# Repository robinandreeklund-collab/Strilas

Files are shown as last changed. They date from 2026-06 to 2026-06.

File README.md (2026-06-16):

# STRILAS

**Ballistic Laser Tactical-Engagement Simulator** — an open, DIY force-on-force training/gaming system. Players carry replica weapons that fire **coded infrared light** (not projectiles). Hits are registered by body/helmet detectors, ballistics and time-of-flight are simulated centrally, and every shot, movement, reload and hit is logged for live tracking and after-action review.

Think MILES / laser-tag, but with simulated ballistics, physical recoil feedback, NFC-based ammunition logistics, and an open telemetry stack you own.

> 📖 **Komplett systemguide (master-referens):** [`STRILAS-SYSTEM-GUIDE.md`](STRILAS-SYSTEM-GUIDE.md)
> — allt på ett ställe: arkitektur, ballistik/räckvidd, precision, hitbox, algoritm, optik, RTK-position,
> haptik, korten, batteritid, eye-safety, tillverkning, verifiering och repo-karta.
> Tillverkningsberedskap: [`vapen-stack/nextpcb/FORSTA-BATCH.md`](vapen-stack/nextpcb/FORSTA-BATCH.md).

---

## ⚠️ Safety first — read this before building anything

STRILAS is a **simulation and immersion** system. It does **not** fire projectiles and provides **no** uplift toward any real weapon. It does, however, contain three genuine hazards that you are responsible for handling correctly:

1. **Eye safety (IR laser).** The engagement emitter uses near-IR (~905 nm) which is **invisible**. Keep the optical output within **Class 1 (eye-safe)** limits and enforce the current limit **in hardware**, not just firmware. The risk is highest near the muzzle where players point at each other. If you are not confident you can keep it Class 1, use a diverged IR-LED emitter instead of a collimated laser diode.
2. **LiPo charging.** The base dock charges many lithium packs at once. This is the single largest fire risk in the project — larger than the laser. Use per-cell balancing, a real BMS, thermal monitoring, and a fire-safe charging area.
3. **High-current contacts.** The recoil rail carries ~20 A peaks through the magazine interface. Use contacts rated **> 25 A** and only ever make/break them **cold** (rail disabled during insert/extract — see the make-ready state machine).

**Replica / airsoft chassis:** STRILAS is typically built onto an airsoft replica body. Airsoft replicas are age- and region-restricted; check and follow your local laws for ownership, transport (e.g. muzzle covers / cases), and where you may use them. Treat and store the device responsibly and never carry it in public in a way that could be mistaken for a real firearm.

**Play safety:** eye protection (rated goggles) for all participants, defined play boundaries, and a clear "weapons safe" procedure.

---

## What it does

- **Coded IR engagement** — every shot transmits a packet (shooter ID, weapon profile, ammo/damage code). Detectors on harness + 360° helmet register hits and hit zones.
- **Simulated ballistics** — per-weapon/ammo profiles define muzzle velocity, drag model, drop and time-of-flight. Because the laser arrives instantly, the **server** adjudicates whether the simulated round would land, using both players' positions, the weapon's attitude and the computed flight time.
- **Physical recoil** — an electronic reciprocating-mass unit gives a real kick, scaled per weapon profile. The IMU senses the muzzle climb it causes and feeds it into the **next** shot's trajectory (the recoil-to-aim loop), so uncontrolled bursts walk off target.
- **NFC ammunition logistics** — each magazine carries a passive NFC tag (ID, capacity, rounds remaining). Inserting a mag sets the ammo counter; running dry blocks fire; reloading rewrites the tag to full at base.
- **Make-ready drill** — the recoil power rail (sourced from a battery inside the magazine) is enabled only after racking a charging handle, mirroring "chamber a round," and disabled before the magazine is released. This also guarantees the high-current contacts are always made/broken cold.
- **Live positioning & telemetry** — UWB (+ GNSS outdoors) gives sub-30 cm position; body/weapon IMUs give pose. Everything is timestamped to a shared clock.
- **After-action review** — weapon-cam video synced with the full event timeline, plus a live dashboard and map.

---

## How it works (engagement model)

```
trigger ──► IR emitter sends coded pulse ──► target detector registers strike
   │                                                  │
   └─► recoil unit fires (PWM scaled)                 │
   └─► IMU captures barrel attitude                   ▼
                                       SERVER adjudicates:
                                       shooter pos + target pos (UWB/GNSS)
                                       + barrel attitude (IMU)
                                       + simulated time-of-flight & drop
                                       ──► hit / miss / hit-zone outcome
```

The key design choice is **central, positional adjudication**: rather than computing the result on each weapon, the server knows where both parties are and how they are moving, and resolves the engagement with the simulated projectile's flight time. This is fairer for moving targets and is the basis for the analytics layer.

---

## Project map (design → validated → runnable)

This repo has grown from the spec above into a **physically-validated design with a runnable
reference implementation**. Where to look:

| Area | What | Where |
|---|---|---|
| **Analysis & BOM** | README review + state-of-the-art level-3 BOM + chosen dev boards | [`docs/hardware-analysis.md`](docs/hardware-analysis.md) |
| **Architecture** | geometric ballistic adjudication + fused pose stack (incl. precision ≠ beam width) | [`docs/level3-ballistic-architecture.md`](docs/level3-ballistic-architecture.md) |
| **System flow** | how it all connects (component map, shot sequence, pose layers) | [`docs/system-flowchart.md`](docs/system-flowchart.md) |
| **v1 build** | exact shopping list for a precise 100–150 m shooting test | [`docs/mvp-shooting-test-bom.md`](docs/mvp-shooting-test-bom.md) |
| **Weapon PCB** | optic module: camera + 2× 940 nm emitters + IMU + buck-CC driver (42×62 mm) | [`hardware/README.md`](hardware/README.md) |
| **Receiver PCBs** | vest detector patch + helmet halo (TSOP + 860 nm constellation + GNSS) | [`hardware/receiver-boards.md`](hardware/receiver-boards.md) |
| **Design resolution** | every open problem → decision (wavelength split, eye safety, etc.) | [`hardware/weapon-module-design-resolution.md`](hardware/weapon-module-design-resolution.md) |
| **Eye safety** | Class 1 current budget (script + report) | [`hardware/eye-safety-budget.md`](hardware/eye-safety-budget.md) |
| **Physics verification** | end-to-end @150 m (radiometry + Monte Carlo + link budget) | [`hardware/system-verification-report.md`](hardware/system-verification-report.md) |
| **Firmware/CV** | runnable, hardware-abstracted chain (CV → fire-control → server) — no HW needed | [`firmware/README.md`](firmware/README.md) |
| **3D simulator** | interactive level-3 pipeline in the browser | [`sim/README.md`](sim/README.md) |

Run it (no hardware): `python3 -m firmware.run_demo` · `python3 -m firmware.test_chain` ·
`python3 hardware/system_physics_verification.py`

The key design choice — **central, positional adjudication** — is fully realized in
[`firmware/adjudicator.py`](firmware/adjudicator.py): the server knows where both parties are and
how they move, and resolves the engagement with the simulated projectile's flight time.

---

## System architecture

```
PLAYER NODE ×N
  ├─ Weapon unit (ESP32 + IMU)   ── ballistics, recoil control, state machine, radio
  ├─ IR emitter (905 nm, coded)
  ├─ Recoil unit (reciprocating mass)   ◄── powered by magazine LiPo via load-switch
  ├─ Harness + 360° helmet detectors
  ├─ Magazine (NFC tag + recoil LiPo + power contacts)
  ├─ Charging-handle & mag-release sensors  (make-ready / cold-mate sequencing)
  ├─ Internal logic cell  ── keeps node alive without a magazine
  └─ Weapon camera
        │  ESP-NOW / WiFi
        ▼
NETWORK (field)
  ├─ UWB anchors ×4–8   (sub-30 cm trilateration)
  ├─ WiFi mesh AP        (telemetry + video backhaul)
  └─ [optional] LoRa gateway + GNSS beacons   (large outdoor fields, coarse/long-range)
        │
        ▼
SERVER / EXERCISE CONTROL
  ├─ Hit adjudicator      (position + attitude + flight time → outcome)
  ├─ Position engine      (UWB + GNSS + IMU fusion → live map)
  ├─ Telemetry DB         (shots · movement · recoil · hits · ammo · make-ready)
  └─ AAR / replay + live dashboard
```

---

## Hardware (reference BOM, per player)

| Subsystem | Part (reference) | Notes |
|---|---|---|
| Weapon MCU | ESP32 (WiFi/BLE/ESP-NOW) | the brain; timing-critical IO |
| IMU | BNO085 (or BNO055) | barrel attitude + muzzle climb |
| IR emitter | 905 nm pulsed module + constant-current driver | **Class 1**, hardware current limit |
| Detectors | IR receiver array (harness) + 360° helmet sensor | hit + hit-zone |
| NFC reader | PN532 (I²C/SPI) + magwell switch | wakes on mag insert |
| Magazine tag | NTAG215 (passive) | ID / capacity / remaining |
| Recoil unit | reciprocating-mass actuator | ~0.12 kg moving mass, ~30 mm stroke |
| Recoil switching | logic-level MOSFET load-switch (>30 A) + flyback diode + 2×2200 µF low-ESR | soft-start |
| Magazine battery | high-discharge LiPo (≥25C) | powers recoil rail only |
| Logic battery | small internal 1S/2S cell + buck | keeps node alive without mag |
| Tracking | UWB tag (e.g. DW3000) + GNSS + body IMU | sub-30 cm + pose |
| Camera | ESP32-CAM / RunCam (5.8 GHz FPV or WiFi) | AAR + live |
| HUD | micro-OLED (SPI) | ammo · hits · weapon state |
| Sensors | charging-handle + mag-release micro-switches/hall | make-ready sequencing |

**Infrastructure:** UWB anchors ×4–8, WiFi mesh AP, server host, multi-bay LiPo charging dock (with BMS), optional Heltec CubeCell (HTCC-AB02S) boards as GNSS beacons / LoRa gateway for large outdoor fields.

> The CubeCell boards are **not** suitable as the weapon MCU (no WiFi/BLE, low-power M0+ core, LoRa is low-rate/duty-cycle-limited). Use them only for coarse outdoor GNSS beaconing or as a long-range LoRa gateway.

---

## Power architecture

Two physical sources, deliberately separated:

- **Logic rail** — internal cell → buck (3V3/5V) → MCU, IMU, IR driver, NFC, camera, OLED, radio. ~0.95 A average.
- **Recoil rail** — magazine LiPo → cold-mate power contacts → MOSFET load-switch (soft-start) → cap bank → recoil motor. ~4 A average, ~20 A peaks during full-auto.

The recoil rail is enabled by the MCU **only between "rack" and "mag release"**, so the magazine contacts are never made or broken under load.

---

## Make-ready state machine

```
NO MAG ──insert mag──► MAG IN (rail OFF, cold contacts)
                          │
                          └─ rack charging handle ─► validate (mag present, ammo>0)
                                                     ─► soft-start recoil rail
                                                     ─► chamber ─► READY (rail ON)
READY ──trigger──► IR + recoil, ammo−1 ──► READY
READY ──ammo == 0──► EMPTY (fire blocked, bolt-lock)
EMPTY ──swap mag + re-rack──► READY
ANY  ──mag-release──► drop rail FIRST ─► mag out (cold) ─► NO MAG
```

---

## Magazine NFC tag layout

| Field | Size | Contents |
|---|---|---|
| UID | 7 B | fixed magazine ID (read-only) |
| Capacity | 2 B | max rounds |
| Remaining | 2 B | current rounds |
| Profile | 1 B | weapon/ammo type |
| HMAC (optional) | 4–8 B | signature to prevent tampering |

Notes:
- The live count is held in **weapon RAM** while seated; the tag is written **once on extraction** (and once on base reload), staying well within EEPROM endurance.
- **Ammo count and battery charge are separate quantities.** Base reload is two decoupled cycles: a fast NFC ammo rewrite, and a slow BMS-managed battery charge. Keep a pool of magazines in rotation.
- For competitive integrity, sign `remaining` with an HMAC shared by weapon and base; mirror counts server-side per mag ID as backup.

---

## Weapon profile (example)

```yaml
# profiles/m4_556.yaml
name: "M4 / 5.56 sim"
muzzle_velocity_mps: 880
drag_model: G7
ballistic_coefficient: 0.151
rof_rpm: 720           # capped by recoil cycle time (~12 Hz)
recoil_pwm: 0.65       # 0..1 felt-recoil scale
mag_capacity: 30
damage_code: 0x12
```

---

## Repository structure

```
strilas/
├─ firmware/
│  ├─ weapon-node/        # ESP32: ballistics, recoil FSM, IR, NFC, IMU, radio
│  ├─ tracking-tag/       # UWB + GNSS + IMU beacon
│  ├─ base-dock/          # NFC rewrite + charge sequencing + logging
│  └─ detectors/          # harness / helmet receiver
├─ server/
│  ├─ adjudicator/        # positional hit resolution + flight-time model
│  ├─ position-engine/    # UWB/GNSS/IMU fusion
│  ├─ telemetry-db/       # time-series store
│  └─ dashboard/          # live map + AAR replay
├─ hardware/
│  ├─ weapon-unit/        # schematics, PCB, enclosures
│  ├─ magazine/           # tag + LiPo + contacts
│  └─ base-dock/          # multi-bay charger + BMS
├─ profiles/              # weapon/ammo YAML
├─ docs/
│  └─ strilas-systemritning.html   # full schematic set
└─ README.md
```

---

## Build & flash (outline)

> Detailed per-module instructions live in each subfolder's README.

```bash
# Weapon node (ESP32, PlatformIO)
cd firmware/weapon-node
pio run -t upload

# Server (dev)
cd server
docker compose up        # adjudicator + position-engine + telemetry-db + dashboard
```

Configuration (network keys, UWB anchor coordinates, weapon profiles) is set in `config/` — see `config/example.env`.

---

## Calibration & pre-game checklist

- [ ] IR emitter verified within Class 1 limits (hardware current limit confirmed).
- [ ] IR/detector boresight and range check; hit-cone divergence set per play style.
- [ ] UWB anchors surveyed; position fix < 30 cm in the play area.
- [ ] Recoil rail soft-start verified; no contact arcing on rack/mag-release.
- [ ] Magazine tags initialised (ID, capacity, profile); base reload writes full.
- [ ] All LiPos balanced/charged on the BMS dock; no swollen cells.
- [ ] Clocks synced across nodes (NTP/PTP); telemetry logging confirmed.
- [ ] Eye protection issued; boundaries and "weapons safe" briefed.

---

## Roadmap

- [ ] Environmental ballistics (wind, temperature) in the flight model.
- [ ] AR reticle/HUD overlay in the optic.
- [ ] Auto-generated engagement clips in AAR (tag video by event).
- [ ] Optional LoRa layer for large outdoor fields.
- [ ] Bolt-lock-back + muzzle-report audio for empty/feedback realism.

---

## Contributing

Issues and PRs welcome. Please keep the safety constraints (IR class, cold-mate contacts, BMS charging) non-negotiable in any hardware change, and document power/timing implications for changes that touch the recoil or engagement path.

---

## License

- Code: MIT
- Hardware: CERN-OHL-S
- Docs: CC BY 4.0

*(Adjust to taste before publishing.)*

---

*STRILAS is a training/gaming simulator. It is not a weapon and provides no real-world weapon capability. Build and operate it responsibly and within your local laws.*

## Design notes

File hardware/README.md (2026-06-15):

# STRILAS — Hårdvaruritningar

Två fysiskt skilda noder, två kort:

| Kort | Nod | Funktion | Doc |
|---|---|---|---|
| **Vapnets optikmodul** | vapen | precis sikteskamera + IR-**sändare** (940 nm) + IMU + driver | nedan |
| **Väst-detektor-patch** | väst | IR-**mottagare** (TSOP 940 nm) + 860 nm-konstellation | [receiver-boards.md](receiver-boards.md) |
| **Hjälm-halo** | hjälm | 8× TSOP 360° + 860 nm-konstellation + **GNSS-patch** | [receiver-boards.md](receiver-boards.md) |

*(Föråldrad: `detector-ring-8x-tsop4856` hade kamera i mitten — player har ingen kamera; ersatt av väst-patch + hjälm-halo.)*

---

## 1. Vapnets optikmodul v1 (KOMPAKT) — sikteskamera + 2× IR-emitter + IMU + driver

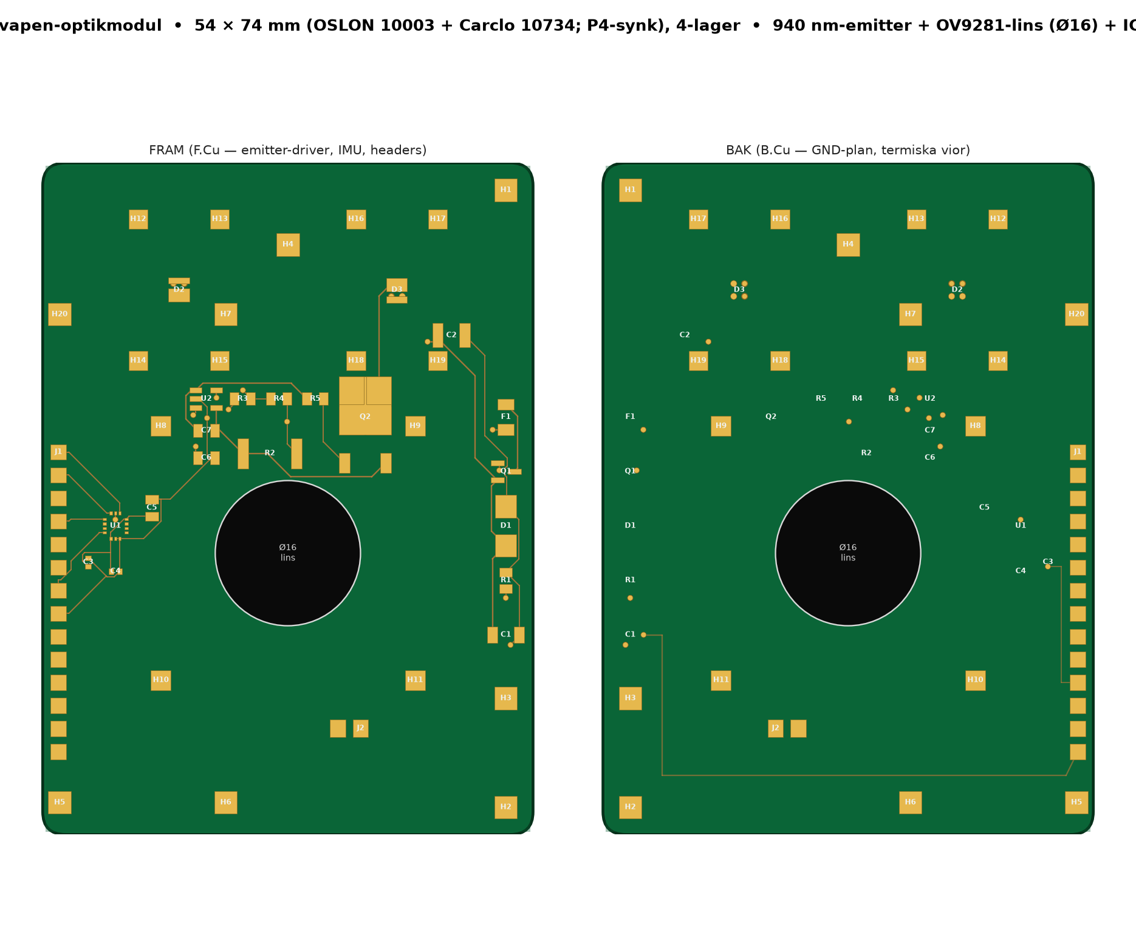
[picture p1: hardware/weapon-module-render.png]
Vapnets optikmodul


**Allt vapnet behöver** på ett kort: precist sikte, skottstråle, attityd och driver.
Krympt från Ø80 (4 emittrar) till **42×62 mm** *utan prestandaförlust*. Genereras av
[`weapon_emitter_layout.py`](weapon_emitter_layout.py).

> **Full designupplösning (alla problem → beslut):** se
> [`weapon-module-design-resolution.md`](weapon-module-design-resolution.md).

**Precisionen** kommer från **sikteskameran** (centrum) som mäter bäringen till målets
IR-konstellation → sub-0,1° (se `../docs/level3-ballistic-architecture.md` §3.2) — den är
**oförändrad oavsett emitterantal**. **Skottet** är de 2 kollimerade emittrarna, symmetriskt
ovanför kameran → **samboresikt** (parallax ~0,01° @150 m; bred kon = bara LOS/ID).

### Vad som sitter på kortet

| Ref | Del | Roll |
|---|---|---|
| (mitten) | **Sikteskamera: OV5647 NoIR + 860 nm bandpass + M12 (FOV 15–30°)** | **PRECISION** — ser konstellationen → solvePnP → bäring (rolling shutter; fast-pan-grind i firmware) |
| D1–D2 | **940 nm OSLON Black** ×2 + **Carclo 10195** (~Ø20) kollimator | **skott** — kodad 56 kHz-stråle, 100–150 m |
| U2 | **TDK ICM-45686 IMU (SPI)** | attityd mellan kamerabildrutor + rekyl; **array borttagen — verifierat 1 räcker** (drift 0,0005°) |
| U6 / L1 / Rsense | **buck konstantströms-LED-driver** (från 2S) / induktor / sense-resistor | konstantström + **hårt HW-tak = ögonsäkerhet** |
| C1 / Cin / D5 / Q1 | Cout 220 µF / in-cap / freewheel-diod / AO3400 **56 kHz-gate** | switch-passiva + bärvågs-gate |
| Q2 / TVS / F1 | reverse-FET / clamp / PTC | inskydd på VBAT |
| J1 | **2×5 SPI:** VBAT·EN·IR_MOD·SCK·MOSI / GND·3V3·GND·MISO·CS | mot ESP32-P4 (kamera via FFC) |

### Mått & el — och varför prestandan hålls

- Kort **42 × 62 mm** (rundad rektangel), 3× M2.5. **~48 % mindre yta än Ø80**, halva bredden.
- **2 LED i serie** delar effektlasten → 100–150 m bibehålls; **VBAT 2S in**, U6 **buck-CC** steg ner (boost ej nödvändig); **IR_MOD** = 56 kHz på Q1-gaten.
- **1 IMU på SPI** (SPI för hög ODR vid rekyl). Array **borttagen** — fysik-verifieringen visade inter-frame-drift 0,0005° ≪ krav.
- **Precision = kameran** (emitter- & IMU-antal påverkar inte rubrik-precisionen — kameran 90 fps GS är primär referens).

### ✅ Självbländning — LÖST via våglängdssplit

**SKOTT = 940 nm**, **kamera = 860 nm bandpass** → kameran **avvisar sina egna emittrar**.
Inget timing-/baffelberoende (baffel kvar som backup). Bonus: 940 nm = TSOP-topp, 860 nm =
bättre kisel-QE för konstellationen. (Detaljer: design-resolution §0.)

### ⚠️ Ögonsäkerhet (mätpunkt)

Buck-CC-drivern (U6) ger **hårt HW-strömtak** (sense-resistor; firmware bara lägre).
**150 m kräver ~2 A** med medium-lins (10195) → Eavg ≈ 18× *punktkälle*-MPE @100 mm; **extended-
source-relaxationen täcker** men **måste mätas** (AE/skenbar källa per IEC 60825-1).
**Bringup: börja 1 A.** Notera: **ögonexponeringen sätts av 150 m-räckviddskravet (~Ie 59 W/sr),
ej av linsvalet** — medium @ 2 A ≈ minsta möjliga exponering. (Verifiering + design-resolution §3.)

### ⚠️ Kamera = OV5647 (kit), men MÅSTE vara NoIR

Kit-kameran är **Raspberry Pi Camera Model B = OV5647** (5 MP, 1/4″, M12 6 mm/F2.0/60,6° diag),
P4-stödd. **MEN spec säger "IR night vision: nonsupport" → den har IR-cut-filter och ser INTE
860 nm.** Vår precisionsväg kräver att kameran ser målets 860 nm-konstellation, så:
**du måste använda NoIR-varianten** (ta bort IR-cut-filtret, eller köp RPi NoIR-kameran).
Utan det ser sikteskameran ingen konstellation.

- **Stock-lins 6 mm/F2 (~33° H):** fungerar (verifierat SNR ≈ 30 @150 m, kort exp) men mindre
  marginal. **M12-linsen är utbytbar** → längre brännvidd ger mer räckvidd/SNR om du vill.
- Rolling shutter hanteras med kort exponering + modulerade LED + **fast-pan-grind** i firmware.

**GS-uppgradering om grinden blir för begränsande:** **ams-OSRAM MIRA220MINI MONO** (global shutter,
NIR) — köpbar (DigiKey **~$141**), men **eval-/sensorkort**, inte ett färdigt kit → P4-integration
gör du själv (ams-OSRAM-exempel finns); footprint ur deras öppna PCB-filer.

**Inte** IMX296/Arducam Pivariety (= Pi). Fullt kameraval: [`camera-selection.md`](camera-selection.md).

---

## 2. Detektor-ring (MÅLSIDAN) — 8× TSOP4856 + kamera

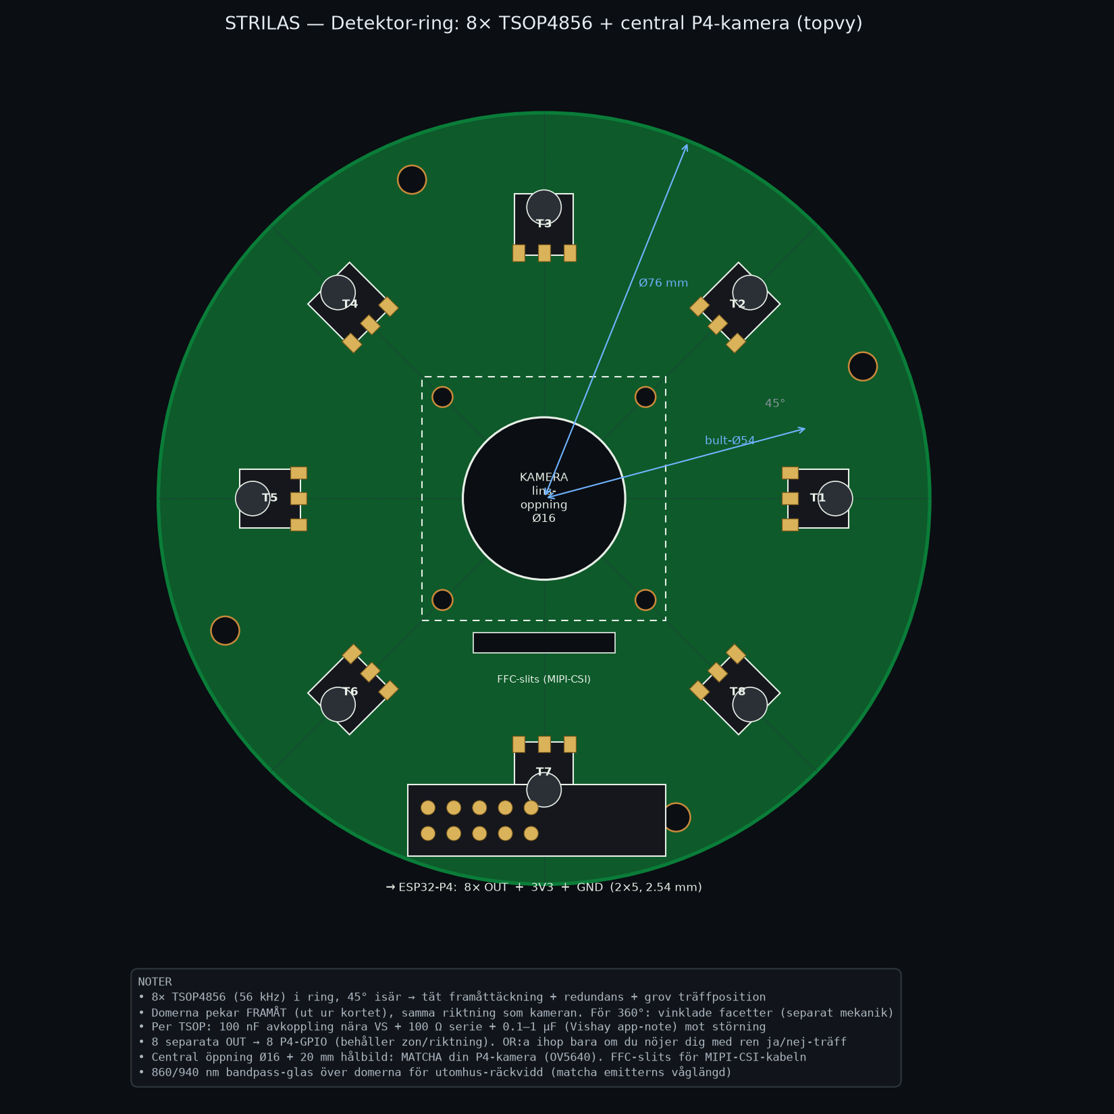
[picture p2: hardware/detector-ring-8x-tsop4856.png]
Detektor-ring


**Målets/västens** mottagarmodul (du skjuter MOT den) — 8 IR-mottagare i ring runt en
kamera. Genereras av [`detector_ring_layout.py`](detector_ring_layout.py). Separat nod
från vapnet; specen för mått/avkoppling/360°-täckning står i skriptets noter.

> Den här hör hemma på målet/västen, inte på vapnet — vapnet **sänder** (kort 1),
> målet **tar emot** (kort 2).

---

## Nästa steg mot riktig PCB

Dessa ritningar → KiCad: SFH 4715AS- + TSOP4856- + kameramodul-footprints, dragning till
header. Säg till så genererar jag KiCad-footprintsen och ett schema.

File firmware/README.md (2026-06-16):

# STRILAS — firmware/CV-skelett (komplett, körbart utan hårdvara)

Hårdvaru-abstraherad referensimplementation av **hela** STRILAS-kedjan + sim-harness,
så allt kan köras och testas i kod innan en enda lödpunkt. Samma logik portar till ESP-IDF
(vapen/mål); bara I/O-lagret (`world_sim`) byts mot riktiga sensorer.

## Kör

```bash
cd <repo-rot>
python3 -m firmware.run_demo      # end-to-end-demo @150 m (perception → FC → server → verdikt)
python3 -m firmware.test_chain    # 15 automatiska tester (alla PASS)
python3 -m firmware.benchmark     # server-prestanda (~57k adj/s)
```

## Moduler

| Fil | Roll | HW-motsvarighet |
|---|---|---|
| `config.py` | delade HW-värden (kamera, konstellation, zoner, profil) | — |
| `protocol.py` | `FireEvent`/`IRHit`/`PlayerState`/`Verdict` (+ nonce/hmac) | WiFi/MQTT-meddelanden |
| `cv_pose.py` | **blob-detektion + pose** (az/el/range) | ESP-P4 kamera/ISP |
| `fire_control.py` | **sikteslösning**: lead (rörligt mål) + holdover (drop) | vapen-firmware/HUD |
| `ballistics.py` | bana → flygtid/drop/anslagsfart (**cachad tabell, O(1)**) | server |
| `imu`-modell | *(IMU-residual i `world_sim`)* | ICM-45686 |
| `anticheat.py` | rullande IR-kod + nonce + HMAC + replay-skydd | säkert element + server |
| `transport.py` | meddelandebuss (pub/sub) | WiFi6/MQTT |
| `engine.py` | **server**: pairing FireEvent↔IRHit, lag-komp, tick-loop | laptop/server |
| `adjudicator.py` | **dom**: ballistik + lead + geometri × IR-grind + anti-fusk | server |
| `weapon_node.py` | vapen-logik: perception + engage → signerad FireEvent | ESP32-P4 |
| `target_node.py` | mål-logik: TSOP → IRHit + PlayerState | ESP32-C5/XIAO-S3 |
| `vest_mb_hw.py` | **väst-moderkortets HW-I/O**: 74HC165-läsning + TPIC6B595-PWM + LED_EN (delat SPI-svep) | XIAO ESP32-S3 (MicroPython→ESP-IDF) |
| `world_sim.py` | **sim-harness**: fejk-kamera, IR-länk, scenario | *ersätts av hårdvaran* |

## Vad som är verifierat i kod (@150 m, allt PASS)

- **Perception:** `render_frame`→`detect_blobs` hittar alla 5 konstellations-LED → pose, range ~150 m.
- **Fire-control:** stationärt + rörligt → HIT rätt zon (bröst/huvud); lead + holdover räknas.
- **Realism:** naivt skott utan holdover landar **lågt** (drop 16 cm @150 m); utan lead **missar** rörligt mål.
- **IR-grind:** cover (ingen IR-LOS) → `NEAR_MISS_NO_LOS` (geometrin dömer, IR grindar hits).
- **Anti-fusk:** manipulerad HMAC + omspelad sekvens → `REJECTED_REPLAY`.
- **Server-motor:** pairing FireEvent↔IRHit, tick-timeout, lag-komp via PlayerState.
- **Prestanda:** **~57 000 adjudikationer/s** (17 µs/skott) → ×120 marginal mot full-auto 32 spelare.

## Nyckelresultat: fire-control

| Mål | Naivt (människa) | Fire-control |
|---|---|---|
| Stationärt | ~10 % | **~100 %** |
| 4 m/s | ~7 % | **~100 %** |

Människans sikt-σ är begränsningen — **inte systemet** (kamerans σ ≈ 0,0004°). Kameran mäter
felet exakt och räknar lead/holdover → träff-% mot 100 %.

## Hårdvaru-abstraktionen (nyckeln)

`WeaponNode.process_detections()` tar **detektor-utdata** (sim nu / P4-kamera sen). Allt ovanför
(pose → fire-control → FireEvent → server-adjudikation) är **identiskt** sim↔HW. `world_sim` är
det enda som kastas när hårdvaran kommer.

## Nästa steg mot skarp drift

1. **Port:** `cv_pose`/`fire_control`/`weapon_node` → C (ESP-IDF); `adjudicator`/`engine` stannar i Python.
2. **Riktig CV:** byt centroid+baslinje mot `cv2.solvePnP` (full 6DoF) + modulerad blink-ID-matchning.
3. **Nät/tid:** WiFi6/MQTT på `transport` + PTP-tidsstämplar på protokoll-lagret.
4. **Bänk:** koppla mot riktiga kort + mät (Class 1, dagsljus-SNR, räckvidd).

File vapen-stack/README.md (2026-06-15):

# STRILAS — vapen-stack (ren leveransmapp)

Allt för den kompletta vapen-stacken i **en mapp**: tre kort, hopsättnings-STEP,
verifiering och komplett BOM. Källkoden (generatorerna) ligger kvar i `../hardware/`.

## Stacken (uppifrån och ned)
```
FC-kort   (fire-control)  ── socket J1 → P4 edge A (12)  ·  J2 → P4 edge B (3V3-tapp)
ESP32-P4  (Waveshare)     ── edge A uppåt (FC) · edge B nedåt (optik)
Optik     (weapon-module) ── socket J1 → P4 edge B (14)  ·  lins Ø16 fram
```
Kraft: **batteri → optik J2 → VBAT → P4 VSYS → P4-regulator → 3V3 → alla kort**
(FC tar 3V3 direkt från edge B via J2 — ingen kabel/bygel).

## Filer

**Färdiga kort (beställ/tillverka):**
| Kort | PCB | 3D | Gerbers |
|---|---|---|---|
| Optik | `weapon-module.kicad_pcb` | `weapon-module.step` | `weapon-module-gerbers.zip` |
| P4-carrier* | `p4-board.kicad_pcb` | `p4-board.step` | — (köps, ej PCB) |
| Fire-control | `firecontrol.kicad_pcb` | `firecontrol.step` | `firecontrol-gerbers.zip` |

\* P4 = köpt **Waveshare ESP32-P4-WIFI6**. `p4-board.*` är mekanik-/headermodell.

**Hopsättning i Fusion (co-orienterade — droppa in vid origo, utan rotation):**
`weapon-module.step` (ankare) · `p4-board-stack.step` · `firecontrol-stack.step`
→ lyft P4 och FC i Z (~socket+header-höjd). USB-kabelpluggen i J_CAM kräver
clearance i P4↔optik-gapet.

**Färdig hop-assembly (allt i en fil):** `strilas-assembly.step` — alla tre korten
i en STEP, co-orienterade, **12 mm plan-till-plan** (optik z0 · P4 z12 · FC z24).
Standoffs läggs in av användaren. Regenereras med `python3 merge_assembly_step.py`
(kräver `pip install cadquery` — bygger en korrekt OCCT-assembly, stel Z-placering).

**BOM:** `BOM.csv` · `BOM.md` (komplett, alla kort + externa moduler). Regenereras
med `python3 gen_bom.py`.

**Verifiering:** `python3 system_sim.py` → ström-/signalflöde över kortgränserna
(0 typkrock · 0 utan ström · 0 dinglar). Bilder (regenereras ur live-netlista/-geometri):
- `port-matching.png` — varje stift etiketterat, mate-par med ✓ (`render_port_labels.py`)
- `edgeB-match-proof.png` — edge B↔optik: alla 14 stift + 4 hål, standoff-låst,
  speglad mate J1.k↔P4-stift(15-k), verifierad 0.000 mm (`render_edgeb_proof.py`)
- `system-flow.png` — kraft-/databuss-översikt

> **Mate (verifierat 0.000 mm mot _pads_z-geometrin):** P4 edge B är flippad till baksidan
> (J_B) → STACKAD/speglad mate, så optik **J1.k ↔ P4 edge B-stift (15-k)** (J1.1↔GPIO32 …
> J1.14↔VSYS). Edge A (FC) är på framsidan → RAK mate (FC J1.k ↔ edge A-stift k+5).
> De 5 IMU/SPI-näten ligger på J1-stift {1,2,4,6,7} = GPIO {32,27,26,23,22} och är
> permuterade för planär (korsningsfri, via-fri) routning IMU→J1 på F_Cu.

**Footprints:** `strilas.pretty/` (IR-emitter + ICM-456xx IMU).

**Design-noter:** `firecontrol.md` · `weapon-module-fab.md`

## Regenerera (källa i ../hardware/)
```
python3 hardware/weapon_module_netlist.py   &&  python3 hardware/receiver_place.py weapon
python3 hardware/make_p4_board.py
python3 hardware/firecontrol_netlist.py     &&  python3 hardware/receiver_place.py firecontrol
python3 hardware/export_stack_step.py        # co-orienterade STEP
```

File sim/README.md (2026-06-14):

# STRILAS — 3D hårdvarusimulator (webb-frontend)

En **komplett interaktiv simulering** av hela STRILAS-vapnet med den valda hårdvaran, i en 3D-vy. Inget behöver köpas — du ser exakt hur allt fungerar och hänger ihop, och kan trimma alla parametrar förrän du spikar designen.

## Kör den

Den är **självständig (offline)** — Three.js ligger lokalt i `vendor/`. ES-moduler kräver en HTTP-server (inte `file://`):

```bash
cd sim
python3 -m http.server 8099
# öppna http://localhost:8099 i Chrome/Edge/Firefox
```

## Vad som simuleras (all "riktig" hårdvara)

| Hårdvara | Modelleras som |
|---|---|
| **ESP32-P4 + C6** | fire-control-FSM (NO_MAG→MAG_IN→READY→EMPTY→KIA), ammo, timing |
| **SFH 4715AS-emitter** | IR-länkbudget på riktigt: räckvidd = √(Ie/Emin), beror på **pulsström, strålvinkel, antal LED, 860 nm-filter och miljö (sol!)**. IR-räckviddsringen på marken blir röd när målet är utom räckhåll. |
| **TSOP4856-detektorer** | kroppszoner (huvud/bröst/mage/ben) som tänds vid träff; träff kräver att strålen når inom IR-räckvidd |
| **ICM-45686-IMU** | rekyl-klättring per skott (ackumuleras i auto → serien vandrar av), IMU-pitch-rate i telemetrin |
| **Magasin / NFC** | ammo-räkning, omladdning |
| **MilesTag II** | paketet (typ+ID+team+skada) byggs och visas live + airtime |
| **Ballistik (M4-profil)** | flygtid/drop, skalas per vapenprofil |
| **Fas 2 server-adjudikation** | togglas: flygtid + lead mot rörligt mål + exakt zon (headshot på alla avstånd). Av = Fas 1 (stråle+zon, headshot bara nära). |

## Kontroller

- **Auto-eld** (på som default) visar systemet live direkt.
- **Skytt-vy (FPS):** klicka knappen → sikta med musen, vänsterklick = eld, `Esc` = tillbaka till orbit.
- **Orbit:** dra för att rotera, scrolla för zoom.
- Reglage: vapenprofil, miljö (sol), pulsström, strålvinkel, antal LED, 860 nm-filter, **GNSS-heading**, **kamera/AI-pose**, Fas 2 på/av, skytt-skicklighet (siktfel σ), målets fart.
- FSM-knappar: sätt i magasin · rack · avfyra · ladda om.

## Saker att testa (bevisa designen själv)

1. Ställ miljö = **"Direkt sol mot sensor"**, pulsström **1 A**, 1 LED → se IR-räckvidden krympa (ringen röd, missar). Höj till **3 A, 2 LED, smal stråle, +filter** → räckvidden återvänder. (Bevisar IR-länkbudgeten från `docs/phase1-feasibility-sim.md`.)
2. Sätt **strålvinkel ±0.4°** och hög skicklighet → precisa headshots. Höj **σ** → missar. (Sikt-momentet.)
3. **Fas 2 av** + snabbt mål → se hur headshot-precisionen tappas på avstånd. **Fas 2 på** → återställs.
4. Håll auto-eld i gång → se **rekyl-klättringen** vandra serien uppåt (IMU).

Modellerna ligger i `hardware.js` (porterade från Python-simuleringen i `docs/`).

## Nivå 3 — geometrisk ballistik-adjudikation (uppdaterad)

Simulatorn kör nu den **riktiga nivå-3-pipelinen** (se `docs/level3-ballistic-architecture.md`), inte laser-tag:

1. **① Sikte** — auto-aim/FPS-siktvektor med siktfel σ, rekyl-klättring och **IMU heading-drift** (växer över tid, **nollställs av varje IR-träff** → visar varför IR-ankaret behövs).
2. **② Ballistik-bana** — kulan integreras i 3D (`integrate3D`): gravitation + drag + **sidvind**. Banan ritas som en **böjd gul kurva**; kulan flyger längs den med drop.
3. **③ Geometri** — **CCD-skärning** av banan mot målets **kapsel-kropp** (huvud/bröst/mage/ben), utvärderad vid varje tidssteg → leadet mot rörligt mål sköts automatiskt.
4. **④ IR LOS + zon** — strålen mot målplanet: inom strålkon + IR-räckvidd → LOS ✓ + zon.
5. **FUSION** — `HIT` = geometri-anlände **OCH** IR-LOS; zon från IR, skada skalad av anslagsfart. Annars NEAR-MISS / FÖRKASTAD / MISS.

Adjudikationspanelen (nere till höger) visar alla fyra steg + fusionsverdikt live. Testa: sätt **sidvind** och se banan kröka i sidled; öka **avstånd/målfart** och se geometrin räkna lead; dra ut målet bortom IR-räckvidden och se att fusionen kräver både geometri och IR.

## Fuserad pose-stack (kamera/AI + GNSS-heading)

Den **beslutade** pose-arkitekturen (se `docs/system-flowchart.md`) är inbyggd som två togglar under "Pose-stack (fuserad)":

- **GNSS-heading-ankare (~0,1° yaw)** — på som default. Binder IMU:ns heading-drift kontinuerligt; av → driften vandrar igen tills nästa IR-träff nollställer den.
- **Kamera + AI-pose (samboresiktad emitter-ring)** — sikteskameran läser målets **fiducial-konstellation** och AI-fire-control förfinar siktet optiskt. När lås finns krymper **σ_eff** till kamerans bäringsgolv (~0,17° @30 m) och leadet blir exakt (kameran mäter farten).

**Visuellt:** vid mynningen sitter de **4 IR-emittrarna i en kvadrat runt en cyan kamera** (samaxlig fire-stråle). När kameran är på syns målets fiducial-konstellation; vid **lås** tänds den cyan och en lås-linje dras till målet. Telemetrin visar **Pose-källa**, **σ_eff** och **Kamera-lås** live.

**Bevisa värdet:** sätt **σ = 2–3°** (skakig skytt) och håll auto-eld → spridda missar. Slå på **Kamera/AI** → σ_eff kollapsar, serien dras ihop och träffprocenten skjuter i höjden. Det är exakt vinsten med den optiska pose-uppgraderingen (HITS/TrackingPoint-vägen) ovanpå IMU/IR-basen.

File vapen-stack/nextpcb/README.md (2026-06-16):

# STRILAS — NextPCB tillverknings-underlag (PCB + SMT-montering)

Två tillverkade kort. **P4 (Waveshare ESP32-P4-WIFI6) köps separat — tillverkas ej.**

För varje kort, ladda upp på nextpcb.com:

| Steg | Optik | Fire-control |
|---|---|---|
| **PCB (Gerber)** | `optik-gerbers.zip` | `firecontrol-gerbers.zip` |
| **BOM** | `optik-bom.xls` | `firecontrol-bom.xls` |
| **Centroid (pick&place)** | `optik-centroid.csv` | `firecontrol-centroid.csv` |

## Kort-data (för PCB-formuläret)
- **Lager:** 4 (F.Cu signal · In1=GND · In2=VBAT · B.Cu=GND) — bägge korten.
- **Optik:** ~54 × 74 mm. **Fire-control:** ~71 × 21 mm.
- Koppar 1 oz, FR-4, HASL eller ENIG. Min spår/gap 0.2 mm, min via 0.3 mm (håller marginal).

## BOM — kolumnstruktur (NextPCB-mall)
`Designator* · Quantity* · Manufacturer Part Number* · Manufacturer ·
Package/Footprint · Description · Procurement Type · Customer Note`
- **Procurement Type:** tom = NextPCB sourcar · `DNP` = montera ej · `C` = du levererar delen.
- Monteringshål (H*) och Carclo-linsben är **kort-features, ej komponenter** → ej i BOM.

## Att VERIFIERA före beställning (`Customer Note`-flaggor)
1. **U1/U2 IMU = TDK ICM-42670-P** — vald för att den är **IN-STOCK** hos LCSC/NextPCB (C3288646),
   till skillnad från ICM-42688-P/45686 (~285–327 dgr ledtid). Pinout verifierad mot databladet
   DS-000451 (`../../datasheet/`): pin 7 = FSYNC ("connect to GND if not used" → vår koppling).
   **Drop-in i SAMMA footprint** som hela ICM-426xx/456xx-familjen → vill du senare ha lägre
   gyrobrus kan ICM-42688-P bestyckas på exakt samma kort utan ändring.
2. **D2/D3 SFH 4725S** (IR-emitter) — bestyckas av NextPCB (matchad, ~10 dgr). INTE kund-levererad
   → kortet kommer komplett bestyckat. (Linser/kamera tillkommer separat, se huvud-README.)
3. **R2 (optik) 3R3 2W 2512** — effektresistor (IR-strömtak). MPN är 2 W-variant (Vishay HP); bekräfta effekt.
4. **F1 (optik) PTC** — bekräfta hold-ström mot systemets toppmedelström (16 V-variant vald för 2S).
5. **C2 (optik) 100 µF 25 V 1210** — bytt till in-stock Murata (matchar direkt).
6. **Genomplåtskontakter (TH):** JST-PH/-XH + stiftssocklar → selektiv-/handlödning,
   kan offereras separat. Sätt `C` om du själv lödder/levererar dem.
7. Generiska passiva (R/C) MPN = representativa — byt gärna mot NextPCB:s basbibliotek
   (lägre pris); paket/värde är det som måste stämma.

## Centroid-format
`Designator, Mid X(mm), Mid Y(mm), Layer, Rotation` — samma origo som Gerbers
(KiCad absolut/sidorigo). Rotation enligt KiCad/IPC-konvention; granska vid DFM.
J1/J2 sitter på **Bottom** (stack-kontakter flippade till baksidan).

Regenereras: `python3 gen_nextpcb.py` (i `vapen-stack/`).

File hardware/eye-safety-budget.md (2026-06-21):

# STRILAS — Class 1-ögonsäkerhets-strömbudget (skott-emitter, 940 nm)

> **Ingenjörsestimat** för att sätta konservativ start-/HW-tak-ström. **Ersätter inte**
> en formell IEC 60825-1-mätning — slutlig Class 1 kräver uppmätt accessible emission vid
> aperturen, vid låst pulsformat. Beräknad av [`eye_safety_budget.py`](eye_safety_budget.py)
> (parametrisk — stoppa in dina uppmätta värden).

## Antaganden

2× LED, 80 % lins-effektivitet, ±7,5° kon (Carclo 10195), eval @ **100 mm** (IEC Condition 3),
7 mm pupill. Pulsduty: **semi 1,4 %**, **full-auto 9,1 %** (56 kHz-bärvåg × paket × repetition).
λ = 940 nm → C4 = 3,02. Konservativ punktkälle-MPE ≈ **30,6 W/m²** (medel, ~10 s).

## Resultat (konservativ punktkälla, C6 = 1)

| Ström | Ie [W/sr] | E@100 mm | Eavg full-auto | verdikt |
|---|---|---|---|---|
| 0,25 A | 8,3 | 834 | 76 | 2,5× över |
| 0,50 A | 16,5 | 1648 | 150 | 4,9× över |
| 1,0 A | 32,1 | 3215 | 293 | 9,6× över |
| 3,0 A | 86,8 | 8680 | 790 | 25,8× över |

**Max ström för Class 1 (punktkälla):** full-auto **~0,10 A**, semi **~0,67 A**.

## Den avgörande nyansen: utsträckt källa (C6)

Punktkälle-antagandet är **worst case** och dödar räckvidd. Men en **LED + lins är en
utsträckt källa**. Om den uppmätta **skenbara källan ≥ α_max (100 mrad)** relaxeras taket
**~67×** → då blir **1–3 A Class 1 med marginal** (full-auto-tak ~6,7 A, semi ~44 A).

→ **Svaret hänger helt på den skenbara källstorleken.** Det är därför mätning krävs:
- Skenbar källa = liten LED-die imagead → nära punktkälla → restriktivt.
- Skenbar källa = fylld linsöppning (Ø20 @ 100 mm = 200 mrad) → full relaxation.

## Design-regler (beslutade)

1. **HW-strömtak** via sense-resistor (firmware kan bara gå lägre) — "ögonsäkerhet i hårdvara".
   **REALISERAT** (2026-06): aktiv CC-sänka (U2=OPA171 + DPAK-FET + R2=0R2 sense) i optik-netlistan.
   Hård gräns I = Vref/Rsense; Vref ≤ 0,206 V (3,3 V-delaren 15k/1k) → **default I_max ≈ 1,0 A** (R2=0R2).
   **3A-OVERRIDE (2026-06):** montera-för-3A-motstånd **R3 (Rp=0R1, 0805, DNP)** parallellt direkt
   över R2 (sense) → Rsense 0,2→0,067 Ω → I_max ≈ **3,0 A**. Kraft-HW (Rp, F1=PTC_3A, spår) 3A-klassad;
   default **DNP/obestyckat = 1 A** (säker fail-safe — kortet levereras som 1 A). 3 A kräver **medveten
   montering av R3 + förnyad mätning**. (Optikkortet är för tätt för en separat bygel vid sense-noden;
   ett DNP-motstånd är platsfritt, ligger >4,6 mm från linshålskanten och täcker inte kamera-aperturen.)
   - **Headroom (2S, 2 emittrar i SERIE):** 3 A behöver VBAT > 2·Vf(3A)+Vsense ≈ 7,1 V → håller bara i
     övre 2S-delen; firmware-LV-spärr ~7,5 V @3 A (~6,9 V @1 A).
   - **Emitter:** SFH 4725S utgången → **SFH 4725AS** (samma paket/footprint/optik, drop-in; puls-max
     3 A @ tp≤800µs; vårt ~9µs/≤9,1% duty ligger inom kurvan, men 3 A = emitterns abs-tak).
2. **Börja på 0,5–1 A** vid bringup.
3. **Cap full-auto-duty** i firmware (semi är ~6–7× snällare).
4. **2 separata emittrar** = 2 skenbara källor → var och en lägre exponering.
5. **MÄT** AE + skenbar källa per IEC 60825-1 (inkl. enkelpuls + pulståg-N^(-1/4)) **innan**
   modulen riktas mot människor. Köp räckvidd med mottagar-bandpass före mer ström.

## Slutsats

Med konservativ punktkälla är vi **inte** Class 1 vid räckviddsström — men extended-source-
relaxationen täcker troligen 1–3 A. **Det måste mätas**, inte antas. HW-taket + duty-cap +
2-emitter-splitten är de hårda skyddsbarriärerna oavsett mätutfall.

---

# Konstellations-emitter (850 nm Lumileds L1I0, väst-patch + hjälm-mb) — FIRMWARE-TRIMBAR CC-sänka

> Separat hazard från skott-emittern: **850 nm, 90° vidvinkel** (kamera-markör, LUXEON IR Domed).
> Ingen lins-koncentration → irradiansen vid given ström är **mycket lägre** än den kollimerade
> skott-strålen. Men 850 nm är näIR-näthinnefarligt vid hög effekt → samma HW-tak-princip gäller.
>
> **⚠️ LED-BYTE VSMY98545 → Lumileds L1I0-0850090200000 (2026-06):** L1I0 ger **~750 mW/sr@1A ≈ 2× VSMY:s
> 380 mW/sr**. Det betyder att **den ögonsäkra strömmen ungefär HALVERAS** mot VSMY-budgeten nedan — det HÅRDA
> 1 A-taket står kvar (säkert), men den uppmätta säkra DRIFTPUNKTEN blir lägre. *Netto positivt för räckvidd:*
> du når samma räckvidd som VSMY vid ~halva strömmen → större eye-safety-marginal. L1I0 tål 1,5 A DC / 5 A puls
> (200000-variant), Vf~3,2 V@1A (tightare 2S-headroom → firmware-LV-spärr ~7,2 V). **Kräver förnyad IEC 60825-1-
> mätning med L1I0 innan modulen riktas mot människor** — siffrorna nedan är VSMY-baserade och konservativa nu.
>
> **STATUS:** Realiserat på BÅDA korten — **väst-patch** (×14; U5/Q1/R6 etc.) OCH **hjälm-mb:s egna 6
> navmarkör-LED** (U9/Q1/R14 etc.). Hjälm-mb routades INKREMENTELLT (`hardware/helmet_cc_sink.py`,
> bevarar de 886 befintliga spåren) eftersom full freerouting hänger på det tätt routade 4-lagers-kortet.

## Topologi (2026-06, ersätter passiv 10R-strömsättning)

Samma aktiva CC-sänka som skott-emittern, men **referensen är nu FIRMWARE-STYRD**:
- **U5 = OPA171** + **Q1 pass-FET (AO3400)** + **R6 = 0R2 sense** → I = Vref/Rsense.
- **Vref = LED_EN** (moderkortets broadcast-GPIO) körd som **FILTRERAD LEDC-PWM**: R8(15k)/R9(1k)-
  delare + C6(100nF) → RC ~94 µs släpper blink (≤120 Hz kamera-fps) men filtrerar PWM-bärvågen.
- **Delaren 15k/1k är SAMTIDIGT det HÅRDA TAKET:** Vref_max = 3,3·1/16 = 0,206 V → **I_max = 1,0 A**
  (R6 = 0R2). Firmware sätter PWM-duty 0–100 % → I **0–1,0 A STEGLÖST** men kan **ALDRIG** överstiga
  taket (eye-safety-regel #1 i HÅRDVARA — firmware-bugg/full duty ger fortfarande ≤1 A).
- **3A-override:** montera DNP **R7 = 0R1** parallellt över R6 → 0,2∥0,1 = 0,067 Ω → I_max ≈ 3 A.
  Default **DNP/obestyckat = 1 A** (säker fail-safe, levereras så). 3 A = medvetet labbeslut, kräver
  **förnyad IEC 60825-1-mätning + branch-balans-R-termik-koll** (R3-R5 = 1R 1206: 1 A/gren → 1 W → uppgradera).

## ⚠️ FIRMWARE-KONTRAKT — LED_EN är nu ANALOG setpunkt, EJ digital enable

`LED_EN` (vest-mb GPIO7 / helmet-mb GPIO2, broadcast till alla konstellations-drivare) drivs nu som
**LEDC-PWM**, INTE en på/av-GPIO. **Ström ∝ PWM-duty** (filtrerad). Blink/identifiering görs genom att
släppa duty till 0 i blink-takten (RC släpper ≤120 Hz). PWM-bärvåg ≥100 kHz (filtreras av RC). Varje
kort har egen CC-sänka → **självreglerar oavsett kabellängd** (ingen kalibrering per patch).

## Design-regler (konstellation)

1. **Börja LÅGT** (duty f. ~0,3 A) vid bringup; öka stegvis och **MÄT** accessible emission + skenbar
   källa per IEC 60825-1 **innan** patchar/hjälmar bärs mot människor.
2. HW-taket (R6 + 15k/1k) = hård barriär; firmware kan bara gå lägre. 3 A endast via medveten R7-montering.
3. L1I0 (~2× VSMY mW/sr) når räckvidd vid LÄGRE ström — **varje strömnivå/LED-byte kräver ommätning**
   (OSLON 0,5A → VSMY → L1I0: Ie/A ökar nu kraftigt → KÖR LÄGRE ström, mät om den säkra punkten).

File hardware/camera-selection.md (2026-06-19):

# STRILAS — Kameraval (sikteskamera)

> ## 🔒🔒 LÅST (för 150 m): **Arducam B0332 (USB OV9281 GS) + 16 mm M12-lins + 850 nm IR-pass**
> | Del | Exakt | ~Pris | Not |
> |---|---|---|---|
> | **Modul** | **Arducam B0332** — 1 MP OV9281 **mono global shutter**, **USB-UVC 2.0**, M12-fäste | ~$30 | UVC → P4:ans USB OTG 2.0 HS, ingen drivrutin; sensorn ser NIR (850 nm) i grunden |
> | **Lins** | **16 mm M12, F/2** (t.ex. Arducam M2016ZH01) → på 1/4″ OV9281 = **13,7° H FOV** | ~$8 | byt mot stock-vidvinkeln; M12-barrel Ø12 mm går genom Ø16-hålet |
> | **Filter** | **M12 850/860 nm IR-pass/bandpass** | ~$8 | dagsljus-avvisning + ser bara 860 nm-konstellationen |
>
> **Varför 16 mm (inte 6 mm):** OV9281 är 1 MP. Vid 6 mm (35,5° FOV) subtenderar konstellationen
> bara ~9 px @150 m → LED:erna smälter ihop. **16 mm (13,7°) ger ~24 px baslinje + ~14 px LED-
> separation → robust PnP @150 m med marginal** (verifierat, se [`system-verification-report.md`](system-verification-report.md),
> brännvidds-svep). Scen @150 m = 36 m bred → gott om plats att hitta mål. *(12 mm = vidare FOV men
> knappare marginal; 6 mm = bara ~80 m.)*
> **MÅSTE se 860 nm:** OV9281-sensorn är NIR-känslig utan IR-cut; välj 16 mm-lins **utan IR-cut**
> + IR-pass-filtret ovan. (Stock-B0332-linsen har redan 850 nm-pass — vid linsbyte tillförs filtret separat.)
> Kameran sitter mekaniskt **bakom** optikkortet, linsen genom Ø16-hålet; ansluts till P4 via **USB-kabel**.
> P4 mounteras som **carrier** (header-mount). **PCB:t är oberoende av brännvidd** (kameran är mekanisk/USB).
>
> ### P4-carrier pin-map (J1 → P4-GPIO)
> | Signal | P4-pin | | Signal | P4-pin |
> |---|---|---|---|---|
> | VSYS (batteri→P4) | VSYS | | SCK | GPIO22 |
> | 3V3 (P4→logik) | 3V3 | | MOSI | GPIO23 |
> | IR_MOD | GPIO20 (RMT) | | MISO | GPIO26 |
> | IMU INT | GPIO32 | | nCS | GPIO27 |
> *(Batteri matas in på optikkortet J2 → VSYS till P4 + emitter-rail; trigger → egen P4-GPIO på greppet.)*

> ## ✅ KAMERA-BESLUT (juni 2026) — B0332 NU, AR0234-USB som framtida uppgrade
> **P4 = LÅST: Waveshare ESP32-P4-WIFI6.** Kameran kopplas på P4-kortets **4-pin MX1.25 USB-OTG**.
> Verifierat ur Waveshare-schemat: stiften = **USB0_5V (5 V/VBUS, TVS-skyddad), USBD_P (D+),
> USBD_N (D−), GND** — kortet kan **källa 5 V i host-läge** (DCDC + switch). Carriern bär ej
> kamerasignal → **kameran = mekanik + USB-kabel, NOLL PCB-ändring.** (Verifiera pin-ordning mot silk +
> aktivera host-mode VBUS i firmware. Kamera drar ~150–250 mA @5 V → inom VBUS-budget.)
>
> **NU (vald): Arducam B0332** = OV9281 1 MP mono global shutter **USB-UVC**, M12 (~$30) +
> **16 mm M12-lins** (13,7° → 150 m) + **850/860 nm bandpass** (~$16). UVC → ingen drivrutin.
> Kabel: kamera-USB → P4 MX1.25 (5V/D+/D−/GND). **Räcker för 150 m** (verifierat, ~24 px konstellation).
>
> **FRAMTID (drop-in-uppgrade): DECXIN AR0234 1/2.6″ mono GS USB-UVC** (2,3 MP, ~$78) + **25 mm M12**
> (13° på större sensor) + 850 nm. **Mekanisk + elektrisk drop-in:** 38×38 mm kort med **28 mm fäst-hål
> = samma som B0332**, M12-fäste, USB (5-pin-1.25 → P4 MX1.25). 2,3× upplösning → mer 150 m-marginal.
> Bänk-verifiera UVC-enum + 860 nm-känslighet vid leverans. (AR0234:s NIR-QE < OV9281 → bandpass +
> LED-modulering bär; B0332 = fallback om NIR/UVC sviktar.)
>
> **⚠ VIKTIG distinktion AR0234:** funkar **bara via USB-UVC** (DECXIN ovan — egen ISP, syns som webbkamera).
> AR0234 via **MIPI** funkar EJ på P4 (ingen `esp_cam_sensor`-driver), och **Pivariety/Jetson-AR0234**
> (Arducam B0353, Camemake) är Pi-/Jetson-låsta → köp INTE dem.
>
> **Max-NIR-alternativ (ej planerat): ams Mira220 mono** (`MIRA220MINI-SENSOR-BOARD-MONO`, ~$92, 2,2 MP
> NIR-*enhanced*) via MIPI-CSI — bäst 860 nm, har officiellt P4-exempel (ams-OSRAM), men kräver MIPI-
> adapter till P4:ans CSI + firmware-port. Bara om USB-AR0234 inte räcker.
>
> **❌ Köp INTE:** AR0234-**MIPI**/Pivariety (B0353), allt *"Pivariety / for Raspberry Pi / libcamera"*,
> Sony **IMX** = Raspberry-Pi-låsta. Tumregel: "raw MIPI/bare sensor" i `esp_cam_sensor` (ov9281, sc2336,
> mira220, ov5647) → ja; "Pivariety/Pi/libcamera" → nej; **USB-UVC (webbkamera) → ja oavsett sensor.**

> ## (Bakgrund) Två nivåer (custom PCB → tänk långsiktigt)
> - **v1-bänk / snabbstart: Arducam 5MP OV5647 NoIR, M12** (B012S6WJOS, ~$15) — drop-in i kit:et,
>   börja CV-utvecklingen direkt.
> - **Custom-PCB (långsiktigt optimalt): SC2336** (2MP MIPI) — **NIR-native** (ser 860 nm utan
>   filter-pyssel), **större 1/3″-pixlar → bäst IR-SNR** av de billiga, **P4-stödd** (esp_cam_sensor
>   + jeff-cn-exempel), ~$5–10. Designa kortets kamera-urtag/kontakt för SC2336-modulen.
> - **Global shutter** (ideal mot pan-smet): **OV9281 HAR P4-drivrutin** (`esp_cam_sensor`, MIPI) +
>   fungerar via **USB-UVC** (B0332, ingen driver) → GS är fullt möjligt. (AR0234 saknar P4-driver;
>   Mira220 har P4-exempel men dyr/eval.) Se KÖP-KLARA MODULER ovan. *(Äldre not: trodde fel att ingen
>   billig GS hade P4-stöd — OV9281 finns i esp_cam_sensor.)*

### USB-vägen (P4 har USB OTG 2.0 HS) — enda billiga global-shutter-vägen

P4:an har **USB 2.0 HS host** + Espressifs **UVC-host-drivrutin** + **HW-JPEG-avkodare** → en
**USB UVC-kamera fungerar**. Det låser upp **global shutter (OV9281, ~$30)** plug-and-play utan
MIPI-drivrutin — GS tar bort rolling-shutter/pan-smet, den verkliga vinsten för ett rörligt vapen.
Pris: USB-kabel (klumpigare än FFC) + JPEG-avkod-latens (litet med HW-JPEG) + mer firmware
(USB-host+UVC). **OV9281 måste vara NoIR** (ser 860 nm). Ändrar EJ det routade kortet (kameran =
mekanisk + kabelval).

**Gaffel efter prioritet:** GS-precision på rörligt mål → **USB OV9281 GS**; enklast/lägst latens →
**MIPI SC2336/OV5647 NoIR** (rolling + fast-pan-grind).

Kravet: **ser 860 nm** (måste), **billig**. Resolution: ≥1–2 MP räcker för blob-konstellationen.

## Beslut: **OV5647 NoIR** ⭐

| Kamera | P4 | Ser 860 nm | Kontakt | ~Pris | Kommentar |
|---|---|---|---|---|---|
| **OV5647 NoIR** ⭐ | ✅ (egen ISP) | ✅ (inget IR-cut) | **= kit (RPi-stil)** | **$10–15** | **drop-in**, 5 MP, P4-native |
| SC2336 (NIR) | ✅ (P4-exempel) | ✅ NIR-native | 24-pin MIPI (verifiera) | $5–10 | billigast, större 1/3″-pixlar = bäst IR-SNR, 2 MP |
| Kit-OV5647 stock | ✅ | ❌ (IR-cut) | kit | (medföljer) | ser ej IR → kan ej användas som sikte utan filterbortagning |
| Mira220 mono (GS) | ✅ | ✅ NIR | eval-kort | ~$141 | global shutter, men dyr — uppgradering, ej v1 |
| IMX296 / Arducam Pivariety | ❌ (Pi) | — | — | — | ingen P4-drivrutin |

## Varför OV5647 NoIR

- **Drop-in:** kit:et tar redan OV5647 → NoIR-versionen = samma kamera utan IR-cut-filter → samma
  kontakt + samma P4-drivrutin, men **ser 860 nm**. Noll integrationsfriktion.
- **Billig** (~$12), 5 MP (gott om marginal).
- **Verifierad:** SNR ≈ 30 + bäring σ ≈ 0,0008° @150 m med denna sensor-klass (`system-verification-report.md`).

## Billigare alternativ: SC2336

Ännu billigare ($5–10), **NIR-native** (säkerhetskamerasensor → ser 860 nm utan filter-pyssel),
**större pixlar (1/3″) → bättre IR-SNR**, 2 MP räcker. **Haken:** ofta 24-pin MIPI-modul →
**verifiera att FFC/kontakten matchar kit:et**. Driver finns i `esp_cam_sensor` + jeff-cn/esp32-p4-cam-exempel.

## Global shutter (senare)

GS undviker pan-smet men kostar: **Mira220 mono** (~$141 eval) är den P4-stödda GS-NIR-vägen.
Skjut på — rolling shutter + **fast-pan-grind** i firmware räcker för v1.

## Åtgärd — och köp inte en kamera du inte kan använda

Kit:ets stock-OV5647 (med IR-cut) duger **inte** som sikte som den är. Två rena vägar:

1. **Köp kit UTAN kamera + OV5647 NoIR separat (~$12)** — om "utan kamera"-varianten är billigare
   med ungefär kamerans pris. Garanterat, ingen mod-risk. **(rekommenderas)**
2. **Köp kit med kamera + konvertera till NoIR** — RPi Cam Model B har justerbar M12-lins;
   IR-cut-filtret sitter i linshållaren och kan tas bort → NoIR. Gratis, ~10 min, viss risk.

P4 + C6 + högtalare behövs oavsett — frågan gäller bara kameran. SC2336 ($5–10 NIR-native) är
billigast om dess 24-pin-kontakt matchar kit:et.

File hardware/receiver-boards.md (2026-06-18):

# STRILAS — Receiver-/player-kort (väst + hjälm)

Player-sidan. **Ingen kamera** (det är skytten som ser dig). Varje kort gör två saker:

- **Tar emot skott:** Vishay **TSOP4856** (56 kHz) + **940 nm bandpass** — skottstrålen är 940 nm.
- **Syns för skyttens kamera:** **860 nm IR-konstellations-LED** i känd geometri → PnP-bäring.

Genereras av [`receiver_boards_layout.py`](receiver_boards_layout.py). Två kort:

## 1. Väst-detektor-patch (placera 10 → zoner)

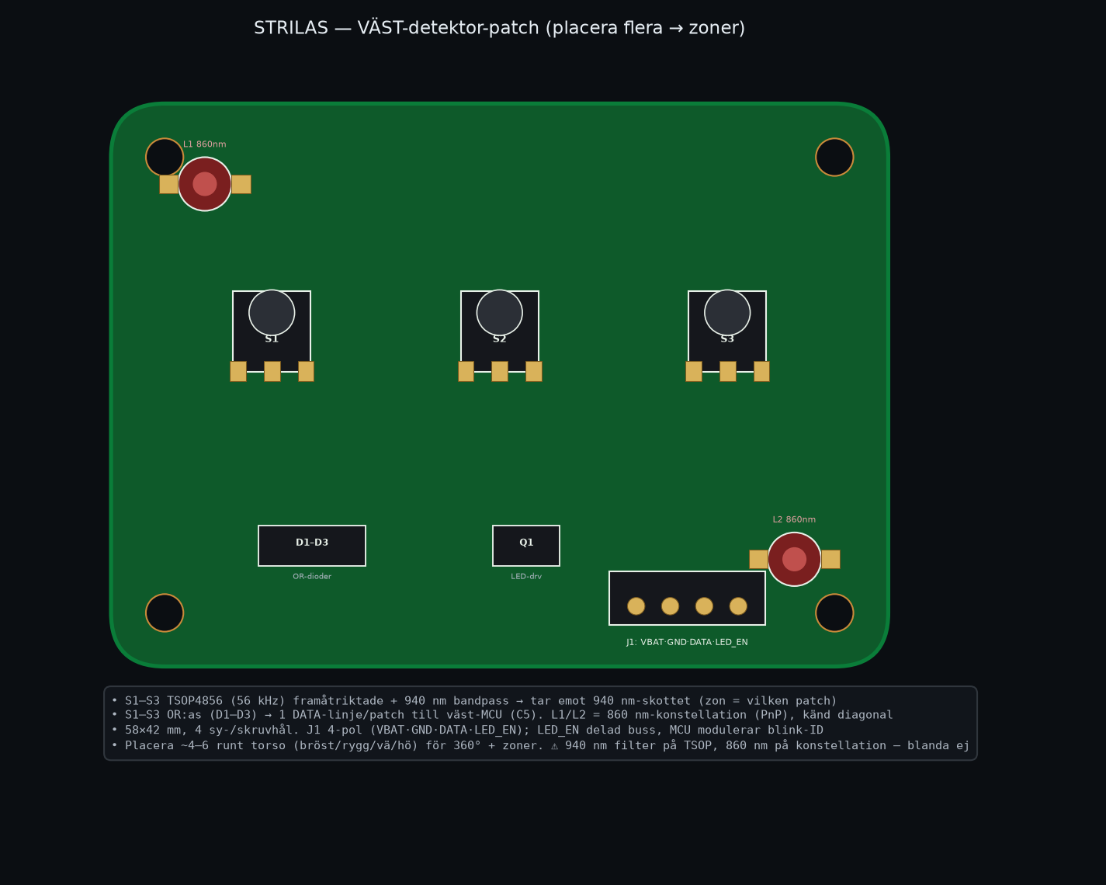
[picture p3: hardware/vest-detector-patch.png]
Väst-patch


- **RUND Ø43 mm** (4-falds symmetrisk, för skydds-/dom-kåpa), 4× M2-skruvhål. **U1–U4 TSOP4856** i
  diamant på kanten, var böjd ~40° utåt (99,5 % framåt-hemisfär, funkar i valfri vridning) +
  **konstellation: 2 fasta 860 nm OSLON (centrum) + 4 böjbara LED-tabbar (kant N/Ö/S/V)** = **6 LED**.
  Rund form → optiken aim:ar radiellt ut utan att en platt frontkant skuggar synvinkeln; ryms i en
  rökfärgad polykarbonat-dom (Ø46,5 inner) som skyddar de böjda benen.
- U1–U4 **OR:as** (BAT54-dioder D5–D7 + en till) → **1 DATA-linje per patch** till väst-noden (ESP32-P4).
  Zon = vilken patch som fyrar.
- **J1 5-pol:** `VBAT · GND · DATA · LED_EN · +3V3`. +3V3 kommer FRÅN moderkortet (matar TSOP, abs-max
  6 V → tål ej 2S direkt); LED-konstellationen drivs på **VBAT** via N-FET (AO3400, LED_EN-grind), i
  **3 seriepar-grenar** (2 LED + 10R 2512/gren). LED_EN delad buss; noden modulerar blink-ID.
- **10 patchar runt torso** (bröst / rygg / vä / hö) → 360° + zoner. (Vibratorn matas separat via zon-kontaktens VIB-stift.)

## 2. Hjälm-halo (360° + huvud-zon + GNSS)

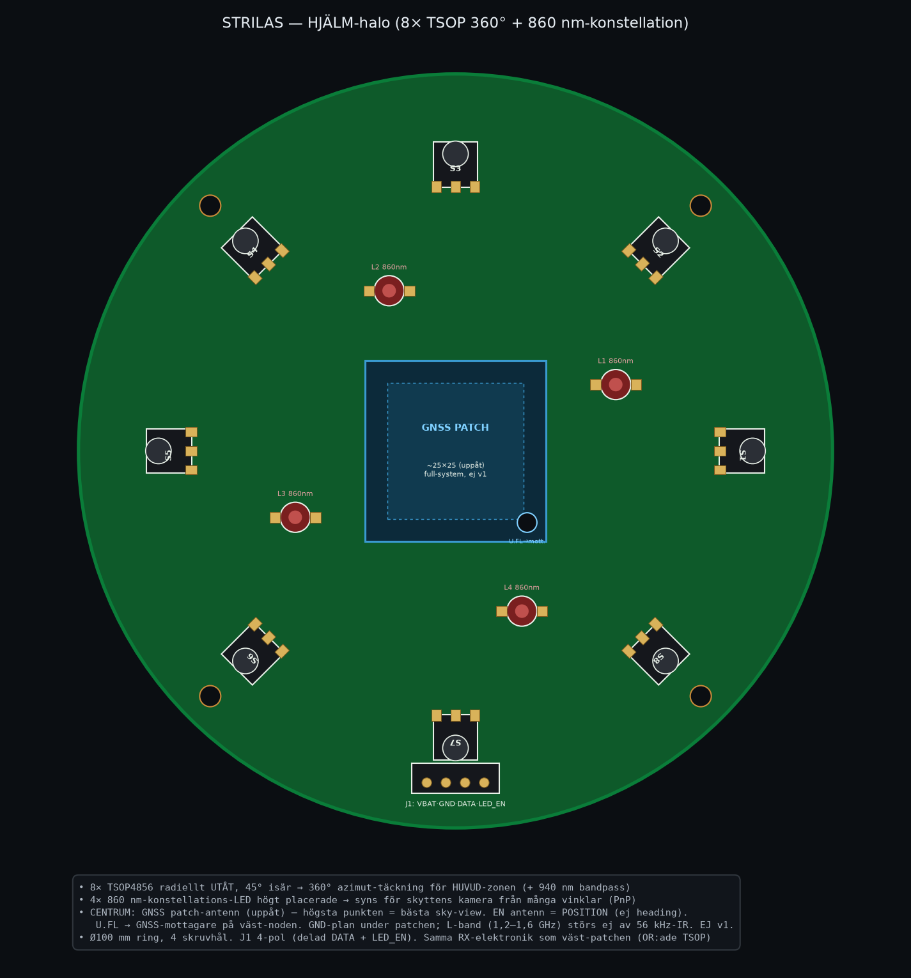
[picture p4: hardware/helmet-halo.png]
Hjälm-halo


- **Ø100 mm ring**, 4 skruvhål. **8× TSOP4856 radiellt utåt** (45°) → 360° azimut för **huvud-zonen**.
- **4× 860 nm**-konstellation högt placerade → syns för skyttens kamera från många vinklar.
- **CENTRUM: GNSS patch-antenn (uppåt)** — hjälmen är högsta punkten = bästa sky-view.
  - **En** antenn = **position** (heading är vapnets dubbelantenn-jobb, separat).
  - U.FL → GNSS-mottagare på väst-noden. GND-plan under patchen. L-band (1,2–1,6 GHz) störs ej av 56 kHz-IR.
  - **Full-system, ej v1-aktiv** — footprint nu, bestyckas senare.

## Våglängdsplan (måste hållas)

| Funktion | Våglängd | På kortet |
|---|---|---|
| Ta emot skott | **940 nm** | TSOP4856 + 940 nm bandpass |
| Synas (konstellation) | **860 nm** | 860 nm-LED |

⚠️ Blanda inte filtren: 940 nm på TSOP, 860 nm på konstellationen.

## Inkoppling (samma för båda)

Varje patch → **5-pol** kabel till **väst-noden (ESP32-P4)**: `VBAT · GND · DATA · LED_EN · +3V3`
(zon-kontakten på moderkortet är 6-pol, med extra **VIB**-stift för zonvibratorn). DATA = patchens
OR:ade TSOP-utgång (noden avkodar MilesTag + vet vilken patch = zon). LED_EN = delad; noden blinkar
konstellationen (frame-synk för skyttens kamera + ID).

## Användning i testet (v1)

Receiver-korten **är** måltavlan: ett kort (eller en patch på ställning/väst) registrerar
skottet (TSOP → ljud/log) **och** lyser med 860 nm-konstellationen så skyttens kamera kan
PnP:a bäringen. GNSS-patchen är vilande i v1 (position mäts med måttband).

## Att verifiera (mätpunkter)

- TSOP-räckvidd @150 m i sol (940 nm bandpass-vinst) — bänk/fält.
- Konstellations-LED-effekt/modulering för kamera-detektion @150 m dag.
- Zon-granularitet (antal patchar) vs önskad upplösning.

---

> **Föråldrad:** `detector-ring-8x-tsop4856.png` (8 TSOP med **kamera** i mitten) var en tidig
> felaktig player-design — player har ingen kamera. **Ersatt av** väst-patch + hjälm-halo ovan.

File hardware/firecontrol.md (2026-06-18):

# STRILAS — Fire-control-kort (vapen)

Litet kort (**71 × 21 mm, samma format som ESP32-P4-WIFI6**, 2-lager) som **stackas rakt
ovanpå P4** och tar dess SIGNALKANT **edge A** via en **FEMALE socket** (P4 bär
male-stiften). Fan-out till greppets I/O via **stående JST-PH** (kabel rakt upp).
Bär även en **extra IMU** (I²C). Optikmodulen (edge B, under P4) förblir ren optik.

## Stack & orientering

```
   FC-kort        (socket ↓ mot P4 edge A, stående JST ↑)
   ───────────  ← genomgående M2-standoff (4 st, P4:ans hål)
   P4 (USB-upp)   (male header edge A ↑ / edge B ↓)
   ───────────
   Optikmodul     (female socket ↑ mot P4 edge B)
   ───────────
   IR + lins + kamera (under)
```

- **P4 orienteras USB-C uppåt.**
- **KANTBYTE (2026-06):** mot den RIKTIGA P4-modellen (Fusion) hamnade J1 fel — den dockade
  edge B i stället för edge A. FC-kortet är därför **speglat om långaxeln (y=120)** så att
  J1 (→ edge A) och J2 (3V3-tapp → edge B) byter långsida och dockar rätt (bekräftat i CAD:
  optik→P4→FC monteras korrekt). Speglingen behåller hålbilden (symmetrisk) → samma genomgående
  M2-standoff. **Pin-ORDNINGEN är OFÖRÄNDRAD (original):** FC J1 (B.Cu) möter edge A på P4:ans
  F.Cu = MOTSATT lager, så speglingen + ansikts-flippen tar ut varandra → fysisk J1.k möter
  edge A pin (k+5). Verifierat mot riktig P4-geometri + kalibrerat mot optik↔edge B = 8/8.
- Edge A saknar kraftskena → **3V3 matas via edge-B kraft-tapp (J2)** direkt från P4 edge B.

## J1 — FEMALE socket mot P4 edge A (pin 6–20, 15-pin)

| J1 | P4-pin | GPIO | Funktion |
|---|---|---|---|
| 1 | 6 | GPIO29 | MAGWELL (magasin-närvaro) |
| 2 | 7 | GPIO28 | RECOIL_FAULT (eFuse fault-in) |
| 3 | 8 | GND | |
| 4 | 9 | GPIO50 | **IMU_INT** (IMU U1, 0x69) |
| 5 | 10 | GPIO49 | **IMU_INT** (IMU U2, 0x68) |
| 6 | 11 | GPIO5 | RACK |
| 7 | 12 | GPIO4 | TRIG |
| 8 | 13 | GND | |
| 9 | 14 | GPIO3 | MAG_REL |
| 10 | 15 | GPIO2 | RECOIL_PWM (→ eFuse EN/gate) |
| 11 | 16 | GPIO8 | NFC_SCL (I²C) |
| 12 | 17 | GPIO7 | NFC_SDA (I²C) |
| 13 | 18 | GND | |
| 14 | 19 | GPIO24 | MODE_A (lägesväljare bit 0) |
| 15 | 20 | GPIO25 | MODE_B (lägesväljare bit 1) |

## Komponenter

| Ref | Typ | Funktion |
|---|---|---|
| J1 | PinSocket 1×15 (female) | mot P4 edge A (pin 6–20) |
| J2 | PinSocket 1×3 (female) | edge-B kraft-tapp (3V3+GND direkt från P4) |
| J3–J6 | JST-PH B2B vertikal 2-pin | trigger / rack / mag-release / magwell (interna pull-ups) |
| J7 | JST-PH B3B vertikal 3-pin | recoil-effektkort (PWM/FAULT/GND) |
| J8 | JST-PH B4B vertikal 4-pin | NFC PN532 (SDA/SCL/3V3/GND) |
| J9 | JST-PH B4B vertikal 4-pin | **OLED SSD1306 I²C** (GND/3V3/SCL/SDA) |
| J10 | JST-PH B3B vertikal 3-pin | **4-läges rotarykopplare** (MODE_A/MODE_B/GND) |
| U1 | TDK IIM-42653 (LGA-14) | **extra IMU #1**, I²C 0x69 (AD0 hög), INT=GPIO50 |
| U2 | TDK IIM-42653 (LGA-14) | **extra IMU #2**, I²C 0x68 (AD0 låg), INT=GPIO49 |
| R1/R2 | 4k7 | I²C-pullups (delas av NFC + båda IMU + OLED) |
| R3/R4 | 4k7 | MODE_A / MODE_B pull-ups (pull-up till 3V3, switch drar till GND) |
| C1/C2 | 100nF / 1µF | 3V3-rail/NFC-avkoppling |
| C3/C4 | 100nF | U1 VDD/VDDIO-avkoppling |
| C5/C6 | 100nF | U2 VDD/VDDIO-avkoppling |
| H1–H4 | M2 | i linje med P4-standoffsen → genomgående stack |

> **4-läges rotarykopplare (MODE_A/MODE_B):**
> Switch common=GND, utgång A → MODE_A, utgång B → MODE_B.
> Pull-ups R3/R4 (4k7) håller linjerna höga när switch-positionen är öppen.
> | Läge | MODE_A | MODE_B | Binärkod |
> |------|--------|--------|----------|
> | Safe | H | H | 00 |
> | Single | L | H | 01 |
> | Burst | H | L | 10 |
> | Auto | L | L | 11 |

> **OLED I²C (J9):** SSD1306 adress 0x3C → ingen krock med NFC (0x24/0x48), IMU (0x68/0x69).
> Delar SDA/SCL (GPIO7/8) med NFC + båda IMU:er. Pinout JST: GND / 3V3 / SCL / SDA.

> **2 IMU på delad I²C-buss** (max på en buss — ICM-45686 har bara adress 0x68/0x69).
> Båda: CS hög → I²C-läge; SDO/AD0 sätter adress. Delar SDA/SCL (GPIO7/8) med NFC
> (PN532 = 0x24/0x48) och OLED (0x3C) — ingen adresskrock; egna INT på GPIO50 resp GPIO49.

## Bygg / reproduktion

```
python3 hardware/firecontrol_netlist.py          # SKiDL → firecontrol.net
python3 hardware/receiver_place.py firecontrol   # placering + outline (71×21, PRE-MIRROR)
python3 hardware/firecontrol_flip.py             # J1/J2 → B.Cu (face down mot P4)
python3 hardware/fc_add_ports_v2.py              # speglar + lägger till J9/J10/R3/R4 (KÖRS EJ vid ny plac.)
# DSN → freerouting → ses_apply → GND-pour → gerbers/STEP
python3 hardware/route_firecontrol.py
python3 hardware/fc_route_fixup.py               # VID BEHOV: kopplar U2.1 om maze stängt in den (annars no-op)
```

> **U2.1-fixen (fc_route_fixup.py) — villkorlig:** U2 (IIM-42653, LGA-14) har AD0/SDO = GND (pin 1)
> inne i fotavtrycket. freerouting kör med GND uteslutet (maze-routas separat). Med nuvarande
> placering (J9/J10 borta från U2) når maze U2.1 direkt → skriptet blir en no-op. MEN routning är
> icke-deterministisk; skulle en seed stänga in U2.1 (verify: 1 oroutad GND, ingen via-plats mellan
> +3V3/NFC_SCL i LGA-pitchen 0,5 mm) tar skriptet bort +3V3-väggen söder om paddan, drar en egen
> GND-flykt (F.Cu→via→B.Cu) och routar om C5:s +3V3 med DRC-min keepout (`MAZE_KEEP=0.30`).

> **Placering (trångt 71×21-kort):** överkanten (y114) full → J9 (OLED, 4-pin) i nedre högra hörnet,
> J10 (lägesväljare, 3-pin) i luckan J6→H4 (J3–J6 skjutna 1 mm vänster), R3/R4 i cap-radens luckor.
> 0 courtyard-krock verifierat.

Routning verifierad **ren**: 0 oroutade (inkl. GND-plan), 0 clearance @0,2 mm, 0 courtyard-krock.
Mate mot P4 edge A verifierad: **0 felmatchningar** (15/15 paddar).

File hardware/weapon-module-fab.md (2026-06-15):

# STRILAS — Vapen-optikmodul: tillverkningspaket (PCB 1)

Komplett elektrisk design för vapen-modulen, genererad i kod
([`weapon_module_netlist.py`](weapon_module_netlist.py) → [`weapon-module.net`](weapon-module.net),
KiCad-format). Kortet är **färdigroutat** (4-lager) med Gerbers — se status nedan.

> **Driver-val (v1):** enkel + ögonsäker — effektresistor **R2 (Rset)** sätter ett **hårt
> strömtak**, N-FET **Q1** gatar 56 kHz. (Buck-CC = effektivitetsuppgradering, design-resolution §2.)
> **Sikteskameran (USB OV9281 GS NoIR) är MEKANISK** bakom kortet (lins genom Ø16-hålet),
> ansluts till P4 via **USB-kabel** → ingen kamera-elektrik på detta kort.

## BOM (24 komponenter, riktiga footprints — inga platshållare)

| Ref | Värde / del | Footprint | Roll |
|---|---|---|---|
| J1 | **P4-carrier-header (2×6)** — VSYS·3V3·GND·IR_MOD·SCK·MOSI·MISO·nCS·INT | PinHeader_2x06 | **P4-anslutning** (kort kabel till P4:ans GPIO) |
| J2 | 2S batteri-in | PinHeader_1x02 | matar VSYS + emitter-rail |
| F1 | PTC ~1 A | Fuse_1206 | inskydd (över-ström) |
| Q2 | AO3401 (P-FET) | SOT-23 | reverse-polarity-skydd |
| R1 | 100 k | R_0805 | Q2 gate-pulldown |
| D1 | SMBJ12A | D_SMB | TVS-clamp på VBAT |
| C1 | 10 µF | C_1206 | ingångskondensator |
| C2 | 100 µF | C_1210 (MLCC) | reservoar för IR-pulsen (låg-ESR @56 kHz) |
| R2 | 3R3 2 W | R_2512 | **Rset — sätter hårt strömtak (ögonsäkerhet)** |
| D2, D3 | **Vishay VSMA1094750X02 (940 nm)** | `strilas:IR_Emitter_Vishay_VSMA1094750` | 2× IR-skott-emitter i serie (1,5 A DC / 5 A puls) |
| Q1 | AO3400 (N-FET) | SOT-23 | 56 kHz-gate |
| R3 | 220 Ω | R_0805 | gate-resistor |
| U1 | **TDK ICM-45686** | `strilas:InvenSense_LGA-14_2.5x3mm_ICM-456xx` | IMU (SPI 4-wire) |
| C3, C4 | 100 nF | C_0402 | IMU-avkoppling |
| C5 | 1 µF | C_0805 | 3V3-bulk |
| H1–H3 | M2.5 | MountingHole_2.5mm | kort-montering (till GND) |
| **H8–H15** | Ø3,2 | MountingHole_3.2mm | **kollimatorfäste — Carclo 60475 4-bens-hållare**, 4 hål/lins, 9,5×16,45 mm-rektangel (R2,4 ben-clearance) |
| **H4–H7** | **M2** | MountingHole_2.2mm_M2 | **kamerafäste — Arducam B0332 28×28-mönster**; **6 mm M2-standoff** (DigiKey 9488532) → kamera bakom, lins genom Ø16 |

Footprints för D2/D3 och U1 ligger i [`strilas.pretty/`](strilas.pretty/) och är ritade mot
datablad (Vishay DocNo 80365; TDK AN-000483 Fig. 2). **Standard DFM:** verifiera padstacken mot
den köpta delens datablad innan beställning.

> **Våglängd:** skottstrålen är **940 nm** (TSOP-topp + kamerans 860 nm-bandpass avvisar egen
> stråle → ingen självbländning). Vishay VSMA1094750X02 = äkta 940 nm (945 nm topp). *(Tidigare
> dokument angav felaktigt "SFH 4715AS 940 nm" — OSLON "AS" är 850/860 nm; rättat här.)*

> **Kamerafäste:** kameran (Arducam B0332, 38×38 mm, OV9281 USB) skruvas fast **bakom** kortet
> via **H4–H7 (M2, 28×28 mm)** — matchar B0332:s hålbild; linsen går genom Ø16-hålet. (B0332 stödjer
> 28×28 och 34×34; vi använder 28×28 = mest inåt, fritt från komponenter.)
> **P4-anslutning:** **J1 (2×6)** för en kort kabel till ESP32-P4-WIFI6:ans GPIO (P4-kortet 71×21 mm
> monteras i vapenkroppen — det får inte plats bakom kortet där kameran sitter). Se routed-doc.

## Nät (konnektivitet — verifierad)

```
VBAT_IN : F1.1 J1.1                    (batteri in)
VBAT_F  : F1.2 Q1.3                    (efter säkring → reverse-FET drain)
VBAT    : C1 C2 D1(TVS) Q2.S R2(Rset)  (skyddad rail; Q2 = reverse-P-FET)
R2→D2→D3→Q1.D (LED-sträng) ; Q1.S→GND ; Q1.G←R3←IR_MOD   (driver + 56 kHz-gate, Q1 = N-FET)
SPI     : SCK(13)/MOSI(14)/MISO(1)/nCS(12)/INT1(4)  ↔  U1(ICM-45686)  ↔  J1
+3V3    : U1.VDD(8)/VDDIO(5) + C3/C4/C5 + J1.2
GND     : U1.GND(6) + allt retur + monteringshål   (IMU RESV 2,3,7,9,10,11 = NC per datablad)
```

## Stackup & designregler (4-lager)

- **4 lager:** Sig / GND / VBAT-pour / Sig. Solid GND-plan; separat effekt-pour för pulsströmmen.
- **Pulslooped** (C2 → R2 → LED → Q1 → GND) **kort & bred**; MLCC nära LED:erna.
- **Termiska vias** under LED-paddarna till baksidans koppar (pulsad effekt).
- **EMI:** håll IR-driverns switchande nod borta från IMU-SPI-spåren.
- DRC: 6/6 mil spår/gap (JLCPCB std), via 0.3/0.6 mm.
- Kort **52×80 mm** (stackad box: P4 bakom); placering enligt [`weapon_emitter_layout.py`](weapon_emitter_layout.py)
  (kamera i mitten, 2 emittrar ovan, IMU + driver i sidoremsorna, J1 nedtill).

## Status: FÄRDIGROUTAD — Gerbers klara

Hela kedjan (placering → routning → kopparplan → Gerbers) kördes autonomt i container; se `build_weapon.sh` för stegen och egenkontrollen.
**35 komponenter, 166 spår + 22 vior, 0 oroutade, 0 clearance-brott @ 0,2 mm.** Färdiga filer:

- **`weapon-module-gerbers.zip`** → ladda upp direkt till JLCPCB/PCBWay (4-lager, 1,6 mm).
- **`weapon-module.kicad_pcb`** → öppna i KiCad för granskning / GUI-DRC.

> **DRC-not:** clearance/connectivity är kontrollerade geometriskt i container (kicad-cli 7
> saknar `pcb drc`). Öppna gärna i KiCad 8 GUI för en formell DRC-stämpel — inga fel väntas.

## Två kvarvarande fysik-steg (kräver den fysiska delen — normalt)

1. **Verifiera footprint-padstacken** mot den köpta delens datablad innan beställning (standard DFM).
2. **Bänkmät ögonsäkerhet (Class 1 / AE)** per IEC 60825-1 vid driftströmmen — R2/Rset är vakten.

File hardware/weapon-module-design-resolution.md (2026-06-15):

# STRILAS — Vapen-optikmodul: full designupplösning (inga genvägar)

> Mål: ta modulen från placerings-sketch → **korrekt, byggbar spec**. Varje känt
> problem listas med **beslut + konkreta värden + motivering**. Det som *måste mätas*
> (ögonsäkerhet, exakt kameramodul) är utpekat som mätpunkter — det är rätt process,
> inte en genväg.

---

## 0. Den avgörande låsningen: två våglängder (löser självbländning + optimerar båda vägar)

| Funktion | Väg | **Våglängd** | Filter |
|---|---|---|---|
| **SKOTT** (vapen-emitter → måls TSOP) | D1/D2 | **940 nm** | måls-TSOP + **940 nm** bandpass |
| **POSE-konstellation** (måls LED → vapnets sikteskamera) | mål-LED | **860 nm** | sikteskamera NoIR + **860 nm** bandpass |

**Varför detta löser allt:** sikteskamerans 860 nm-bandpass **avvisar vapnets egna 940 nm-
skott** → **ingen självbländning** (inget beroende av timing/baffel). Dessutom optimalt per
väg: **940 nm = TSOP-känslighetstopp** (~950 nm), **860 nm = bättre kisel-QE** i kameran →
konstellationen syns på avstånd. 56 kHz-bärvågen är *modulation*, oberoende av våglängd.

> Konsekvens (LÅST): skott-LED = **Vishay VSMA1094750X02 (äkta 940 nm, 945 nm topp)**, 1,5 A DC /
> 5 A pulsat, AEC-Q102 — datablad + footprint klara. *(Tidigare "OSLON Black 940 nm SFH 4715AS"
> var fel: OSLON "AS" är 850/860 nm.)* TIR-kollimator för 3,4 mm-källa. Konstellation = billiga
> 860 nm-LED på målet.

---

## 1. Optik

| # | Problem | Beslut |
|---|---|---|
| 1.1 | Självbländning | **Löst** via våglängdssplit (§0). Baffel = defense-in-depth, ej bärande. |
| 1.2 | FOV-val (telefoto kontra bred) | **FOV är en avvägning, inte ett fast tal.** Det tidigare "telefoto krävs" gällde *passiva ArUco* (avkoda mönster → ~20–30 px på markören → smal FOV @150 m). Vi bytte till **aktiv IR-konstellation** (lokalisera ljuspunkter → få px + subpixel räcker) → **bäringsprecisionen är trivial vid vilken FOV som helst** (30° → 0,013°/px, subpixel ~0,001° ≪ kravet 0,19°). **MEN** smalare FOV/längre brännvidd ger bättre **dagsljus-SNR @150 m** (större bländare, mer signal mot sol). → Sätt FOV av §1.3-testet; trolig landning **15–30°** (smalare = mer räckviddsmarginal; bredare = lättare målfångst, ±7,5° @15° är ändå lätt med grovsikte). |
| 1.3 | Syns konstellationen @150 m i dagsljus? (= det som egentligen sätter FOV) | Konstellations-LED **modulerade** (frame-differencing) + 860 nm-bandpass + tillräcklig **strålstyrka** (~0,5–1 W/sr/LED, ev. lätt kollimerade) + vald **brännvidd**. **Mätpunkt** vid bringup → bestämmer både LED-effekt och FOV. |
| 1.4 | Carclo-linsmontering | 3 **pins** per lins ner i PCB-hål (Carclo-footprint) + lim; LED i optiskt centrum; montera **efter** reflow. |
| 1.5 | Baffel | Svart shroud-ring mellan emittrar och linsbarrel (blockerar sidoljus/scatter). |
| 1.6 | Fokus | M12 fast-fokus satt på **hyperfokal** för engagemangsavstånd (konstellationen är ändå punktkällor → tolerant). |

---

## 2. Emitter-driver (skottet)

| # | Problem | Beslut |
|---|---|---|
| 2.1 | "Rsense som strömgräns" är inte konstant ström | **Hårt HW-strömtak (Rset = R2, 3R3 2W)** sätter Imax oberoende av firmware → "ögonsäkerhet i hårdvara". Det här är vad som är **byggt på kortet** (enkelt, robust, få komponenter). |
| 2.2 | Topologi — **BYGGD v1 = Rset-tak + N-FET-gate** | VBAT 2S (6,4–8,4 V) → **R2 (Rset)** → LED-sträng 2× Vf(940 nm) → **Q1 (N-FET)** mot GND. C2 (220 µF) levererar pulsen. *Buck-CC (nedan) är en **effektivitetsuppgradering**, ej i v1-netlistan.* |
| 2.2b | (Framtida) Buck-CC-uppgradering | VBAT > LED-sträng → steg **ner**; kräver **L1** + **Cin** + freewheel-diod + Rsense. Ger högre verkningsgrad än Rset men fler delar. **Inte** i det routade kortet. |
| 2.4 | 56 kHz-modulering | **Q1 (AO3400) i serie** gatar bärvågen mot GND (RMT från P4 driver gaten via R3). |
| 2.5 | Inskydd | **Reverse P-FET (Q2)** + **TVS** + **PTC (F1)** på VBAT — PTC:s **håll-ström > pulsens medel** (annars nuisance-trip). |

---

## 3. Ögonsäkerhet — riktig bedömning (inte gissning)

**Radiometrisk output (vår modell, 2× 940 nm Vishay, ±5° TIR, 1 A):** Ie ≈ **~54 W/sr** kombinerat.
Irradians vid ögat: `E = Ie / d²`. Värsta fall (någon **1 m** från mynningen): E ≈ 54 W/m² →
genom 7 mm-pupill (3,85·10⁻⁵ m²) ≈ **2,1 mW in i ögat** (pulsat, låg duty).

**Detta är inte trivialt Class 1.** Bedömning per **IEC 60825-1** krävs, med:
- **Definierat pulsformat:** 56 kHz-bärvåg, paket ~14 ms, max repetition (semi: få Hz; full-auto: ~10–15 Hz). Lås detta i firmware (oöverstigligt).
- **Mätvillkor:** radiant effekt genom 7 mm apertur vid 100 mm & 14 mm, inom acceptansvinkeln, för det verkliga pulståget — jämför mot AEL (worst-of: enkelpuls / medel / pulståg).
- **Extended-source-lättnad:** LED (inkoherent, utsträckt) ger högre tillåten exponering än laser — vår fördel.

**Beslut/regel:**
1. CC-driverns sense-resistor sätter **absolut HW-tak**; **börja på 1 A**.
2. Köp räckvidd med **mottagar-bandpass** före mer ström.
3. **MÄT AE vid aperturen** (optisk effektmätare) och få Class 1-utlåtande **innan** modulen pekas mot människor.

> Detta är en **mätpunkt**, inte en genväg: ögonsäkerhet får aldrig härledas ur minnet.
>
> **Kalkyl gjord:** se [`eye-safety-budget.md`](eye-safety-budget.md) + [`eye_safety_budget.py`](eye_safety_budget.py).
> Konservativ punktkälla → max **~0,1 A full-auto / ~0,67 A semi**; men utsträckt-källa-relaxation
> (C6 upp till ~67×) gör **1–3 A Class 1 *om* skenbar källa ≥ α_max** — **måste mätas**.

---

## 4. Termik

Vf(940 nm) ~2 V @ 3 A → ~6 W/LED *under puls*. Men **låg duty** (14 ms-paket @ ~10 Hz ≈ 14 %)
→ snitt ~0,8 W/LED. **Beslut:** kopparpour + **termiska vias** under varje LED:s thermal-pad;
FET (AO3400, låg Rds) klarar pulsat. Verifiera junction-temp vid värsta full-auto-duty.

---

## 5. IMU — 1× ICM-45686 (SPI) — array BORTTAGEN

- **1 IMU på SPI** (SPI för hög ODR vid rekyl-transienten). **Arrayen borttagen** efter
  fysik-verifieringen: kameran re-ankrar attityden varje frame → inter-frame-drift **0,0005°**
  (@60 fps) ≪ krav. 4 chip gav försumbar vinst → onödig yta/komplexitet.
- **Stel koppling** till optisk axel (samma styva kort) — kritiskt för kamera-IMU-extrinsics.
- 100 nF avkoppling; SPI-linjer korta. **Extrinsisk kalibrering** (IMU↔kameraram) en gång.

---

## 6. Kameragränssnitt (löser MIPI-SI-problemet genom att undvika det)

**Ingen kamera-elektrik på detta kort.** Kameramodulen sitter mekaniskt **bakom** kortet (lins
genom Ø16-urtaget) och ansluts till P4 via **USB-kabel** — inte via detta kort. Kortet bär bara:
emitter-driver (effekt), IMU (SPI), P4-carrier-header, batteri-in. → ingen kamera- eller
höghastighets-differential-routing här.

**Vald kamera (LÅST): Arducam B0332 — USB OV9281 mono GLOBAL SHUTTER** (1 MP 1280×800, 3 µm, 1/4″,
USB-UVC → P4:ans USB OTG 2.0 HS; sensorn ser NIR i grunden). **⚠️ Lins utan IR-cut + 850 nm IR-pass-
filter**, annars syns ingen 860 nm-konstellation. **Lins: 16 mm M12 (~13,7° FOV)** — fysiken kräver det
för 150 m (1 MP @ 6mm/35,5° upplöser bara ~9 px konstellation → LED:erna smälter ihop; 16 mm ger ~14 px
LED-separation + 24 px baslinje → robust PnP med marginal; 12 mm = knappare, 6 mm = bara ~80 m).
Global shutter (OV9281) → ingen pan-smet i grunden; kort exponering + modulerade LED ger ren blob-
detektion i dagsljus. (En 6 mm-lins kan behållas om man nöjer sig med robust räckvidd ~80 m.)

**Avstånd:** kommer ur **PnP** (konstellationens kända bas + vinkelutbredning); i v1 mäts målets
position med måttband. **Ingen LiDAR behövs** (superseder av PnP; kan återkomma endast för markörlöst avstånd).

---

## 7. Kontakt & signaler (J1, 2×4) + skydd

**J1 = 2×5:** `VBAT · EN · IR_MOD · SCK · MOSI / GND · 3V3 · GND · MISO · CS`
(SPI för 1 IMU). Trigger går **direkt till P4-GPIO** (på greppet), ej via modulen.
**ESD:** serieresistor + TVS/ESD-diod på IR_MOD och SPI-linjerna.
*(VBAT/GND ev. dubblerade pinnar för pulsström — se §9.5.)*

---

## 8. Boresight & kalibrering (procedurer, en gång)

1. **Kamera-intrinsics** (brännvidd, distorsion) — schackrutemönster.
2. **Kamera-IMU-extrinsics** — relativ orientering.
3. **Boresight-zero** — kameran mäter var skotten landar vs retikel → lagra offset (emittrarna
   är monterade parallellt; firmware-zero tar resten).
4. **Konstellationsgeometri** mätt + lagrad (PnP-modell).

---

## 9. PCB-layoutregler

- **4-lager** (signal / GND / VBAT-pour / signal): solid GND-plan, separat effekt-pour för
  pulsströmmen, stjärnjordning vid sense-resistorn.
- Pulsström-loopen (Cin → buck → L1 → LED → FET → sense) **kort & bred**; MLCC nära LED.
- Termiska vias under LED-pad till baksidans pour.

---

## 9.5 Designgranskning — fynd & optimering

**Funktionellt (åtgärdat):**
- ✅ **Buck-switchens passiva tillagda** (L1 + Cin + D5 freewheel + Cout) — saknades; boost→buck rättat (§2).
- **Per-IC-avkoppling explicit:** 100 nF/IMU, U6 in/ut-caps, 3V3-buss-MLCC. (Schema-detalj, måste ritas.)

**Elektrisk optimering:**
- **EMI:** buck-switchern (U6) är störkälla mot kamera-MIPI/IMU. Placera bort från kamera, skärma,
  och kör helst drivern **bara under skott** (pulsad ändå). Switchfrekvens bort från känsliga band.
- **Pulsström på J1:** VBAT/GND vid 1–3 A puls → **dubbla pinnar / separat effektkontakt**; stjärnjord vid Rsense.

**Mekaniskt / miljö (rekylerande vapen, utomhus):**
- **Låsande + dragavlastade kontakter** (FFC + J1) mot rekylvibration.
- **Kamerafokus-lås** (gänglås/lim på M12) + lins-/filter-retention.
- **Conformal coating** (fukt/damm); stel IMU-montering (redan §5).

**Bekräftat (ingen åtgärd):**
- Kamerans matning + SCCB (I²C-styrning) kommer från **P4:ans CSI-kontakt** → inga kamerarails på detta kort.
- Trigger → direkt P4-GPIO (greppet), ej via modulen.
- ⚠️ **Välj/verifiera TIR-kollimator** för Vishay VSMA1094750 (3,4 mm-källa) → strålvinkel ≤ ±7,5°.

---

## 10. Kvarvarande MÄTPUNKTER (ärlig lista — inte olösta "problem", utan saker som *kräver* mätning)

| Mätpunkt | Hur |
|---|---|
| **Class 1-AE** | optisk effektmätare + IEC 60825-1-villkor, vid låst pulsformat |
| **Exakt kameramodul-mått** | mät OV9281 USB-modulen → lås `CAM_W/H/HOLE` (lins genom Ø16) |
| **Konstellations-synlighet @150 m dag** | bringup-test, justera LED-effekt/modulering |
| **Junction-temp vid full-auto** | termisk mätning vid värsta duty |
| **Räckvidd vs ström** | fälttest, sätt CC-tak till lägsta som klarar 150 m |

Allt annat ovan är **beslutat och låst.**

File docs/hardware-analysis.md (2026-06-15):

# STRILAS — README-analys & hårdvaru-/dev-board-utredning

> Författad som teknisk underlagsrapport. Del 1 granskar nuvarande README/designspec. Del 2–8 är en researchdriven utredning (källor 2025–2026) av varje delsystem med konkreta komponenter, dev boards, priser och en rekommenderad uppgraderingsväg för att ta systemet till "next level". Del 9 samlar allt i en prioriterad roadmap + referens-BOM.

---

## Del 1 — Komplett analys av README

### 1.1 Vad README:n beskriver

STRILAS är en öppen DIY force-on-force-/MILES-liknande träningssimulator: replikvapen skjuter **kodat 905 nm IR** (inga projektiler), träffar registreras av kropps-/hjälmdetektorer, och en **central server avgör träff/miss** utifrån båda spelarnas position (UWB/GNSS), pipans attityd (IMU) och **simulerad ballistik med flygtid**. Systemet har fysisk rekyl (reciprocerande massa), NFC-baserad ammunitionslogistik, make-ready-tillståndsmaskin, live-telemetri och after-action review (AAR).

### 1.2 Styrkor i nuvarande spec

- **Säkerheten kommer först och är genuint genomtänkt.** De tre verkliga riskerna (IR-ögonsäkerhet, LiPo-laddning, högströmskontakter) är korrekt identifierade och rangordnade — och kravet att ögonsäkerheten ska upprätthållas **i hårdvara, inte firmware** är helt rätt.
- **Central, positionsbaserad adjudikation** är den arkitektoniska kärnan och rätt designval — rättvist för rörliga mål och grunden för analyslagret.
- **Två fysiskt separerade kraftskenor** (logik vs rekyl) och **cold-mate-sekvensering** av magasinskontakterna via make-ready-maskinen är välresonerat och säkerhetsdrivet.
- **NFC-ammunition med RAM-buffrad räknare** som bara skriver vid uttag/omladdning respekterar EEPROM-livslängd och är en smart detalj.
- README:n är genomarbetad, internt konsekvent i resonemanget och har realistisk power-budget.

### 1.3 Gap, inkonsekvenser och risker (åtgärdbara)

| # | Observation | Konsekvens | Förslag |
|---|---|---|---|
| 1 | **Repot innehåller bara `README.md`.** `docs/strilas-systemritning.html`, hela mappstrukturen (`firmware/`, `server/`, `hardware/`), `config/example.env` och per-modul-READMEs som länkas/refereras **finns inte ännu**. | Build-instruktionerna (`pio run`, `docker compose up`) går inte att följa; länkar är döda. | Markera README som designspec, eller börja bygga ut skelettet. Skapa minst `docs/` + stubbar. |
| 2 | **Vapen-MCU = en ensam ESP32** som ska göra mikrosekund-exakt IR-kodning, rekyl-PWM, triggerfångst, ballistik-FSM **och** radio på samma kärnor. | WiFi-stacken stjäl CPU-cykler → **timingjitter under nätverkslast**, just i den mest tidskritiska vägen. | Se Del 2: dela compute/radio (ESP32-P4+C6) eller lägg IR/rekyl på en deterministisk IO-coprocessor (RP2350 PIO). |
| 3 | **ESP-NOW** antyds som radioval. Hård gräns på **20 krypterade peers**, ingen QoS/garanterad retransmit. | Skalar inte rent till 16–32 spelare med dubbelriktad telemetri + video. | 5 GHz WiFi 6 (OFDMA/TWT) som backhaul + ev. 802.15.4/Thread-mesh som resilient hit-kanal. |
| 4 | **Tidssynk anges löst som "NTP/PTP".** Rättvis ballistik-adjudikation kräver gemensam tidsbas **snävare än engagemangets timingtolerans** (sub-ms). | Med ren NTP över WiFi (10-tals ms jitter) blir träffordningen mellan snabba skott tvetydig. | PTP/IEEE-1588 över backhaul + **hårdvarutidsstämpling av IR-ankomst** lokalt (PIO/PPI capture). |
| 5 | **IR-kodningsschema är ospecificerat.** | Egen kod är skör mot solljus och replay-/record-fusk. | Anta **MilesTag II / OpenLaserTag** (38–56 kHz modulerad bärvåg + pulslängd) och lägg **CRC + rullande nonce** ovanpå mot replay. |
| 6 | **IMU = BNO085 (eller BNO055).** BNO085 är i praktiken EOL/svåråtkomlig, har en känd "snap"-bugg vid snabba rörelser och **magnetometerfusion fungerar dåligt nära stål** (ett vapen = metall). | Pip-klättring är exakt en snabb, metallnära transient — BNO085:s svaghetszon. | **TDK ICM-45686** i 6DOF (mag av), gyro ≥1–2 kHz, host-side-fusion. |
| 7 | **UWB-metod (TWR vs TDoA) anges inte.** README säger "DW3000 + 4–8 ankare". | TWR skalar dåligt till många taggar; en tagg/ankare kan bara ranga i en slot åt gången. | **TDoA** (synkade ankare) för hög taggdensitet; se Del 3. |
| 8 | **905 nm "raw" laser i BOM.** README flaggar risken korrekt, men default bör vara den säkra vägen. | Ögonsäkerhet hänger helt på diffusion + strömgräns. | Default = diffuserad **860 nm IR-LED (SFH 4715AS)**; 905 nm-laser endast som verifierad Class 1-långdistansvariant. |
| 9 | **ESP32-CAM som vapenkamera.** Rolling shutter + 2.4 GHz + ingen HW H.264. | Smetar vid snabba panoreringar; trängs i 2.4 GHz; svårt att tidssynka frames för AAR. | Se Del 5: Pi Zero 2 W + Cam Module 3 (NoIR), global-shutter-variant för primärvapen. |
| 10 | **Spelarantal definieras aldrig.** Arkitekturen antyder "många". | Dimensionering av radio/server/anchors blir godtycklig. | Sätt ett designmål (t.ex. 16–32 noder) och dimensionera mot det. |

**Sammanfattning Del 1:** Designen är sund och säkerhetsmedveten. De största verkliga svagheterna är (a) en överbelastad ensam-MCU i den tidskritiska vägen, (b) odefinierad/underdimensionerad radio + tidssynk för rättvis adjudikation, och (c) några komponentval (BNO085, ESP32-CAM, raw 905 nm) som redan har bättre 2025–2026-alternativ. Resten av rapporten åtgärdar dessa konkret.

---

## Del 2 — Compute & nätverk (vapnets hjärna + radio)

Vapennoden behöver tre saker samtidigt: **hård realtids-IO** (µs-exakt IR-pulskodning, rekyl-PWM, triggerfångst), en **ballistik-FSM med headroom för sensorfusion**, och **lågfördröjd, deterministisk radio**. Nuvarande ensam-ESP32 tvingar allt på samma Xtensa-kärnor som delar tid med WiFi-stacken — där brister den.

### 2.1 MCU-kandidater

| MCU / board | Kärna / klocka | RAM / flash | Tidskritisk IO | Radio | Determinism | ~Pris (board) |
|---|---|---|---|---|---|---|
| ESP32-S3 (nuvarande klass) | Xtensa LX7 ×2 @240 MHz | 512 KB +8 MB PSRAM | RMT (HW IR-modulering), MCPWM, LEDC | WiFi4 + BLE5 | Medel — radio stjäl cykler | ~$15 |
| **ESP32-P4 (+C6)** Waveshare ESP32-P4-WIFI6 | RISC-V ×2 @400 MHz + LP-kärna | 768 KB L2 + upp till 32 MB PSRAM | RMT, MCPWM; pinna IR/ballistik på en kärna | **C6-kompanjon** (WiFi6 + BLE5 + 802.15.4) via SDIO | Bra — radio avlastad | ~$14–26 |
| **RP2350** (Pico 2 / 2 W) | Cortex-M33 ×2 @150 MHz | 520 KB / 4 MB ext | **12 PIO-state machines** = jitter-fri kodad pulståg + HW IR-ankomststämpling | Ingen (2 W = CYW43 WiFi4/BLE) | **Utmärkt** (bare-metal) | $5 / ~$7 |
| Teensy 4.1 | Cortex-M7 @600 MHz | 1 MB / 8 MB | HW IR-modulator, FlexIO, DMA | Ingen | Utmärkt | ~$32 |
| STM32H7 (H743/H723) | Cortex-M7 @480–550 MHz | upp till 1 MB | Avancerade timers, **on-chip 1588 PTP** | Ingen | Utmärkt (brantast toolchain) | ~$25–30 |
| **nRF54L15** DK | Cortex-M33 @128 MHz + RISC-V | 256 KB / 1.5 MB | PPI/GPIOTE (zero-jitter HW-eventrouting), NFC | **BLE6 + 802.15.4/Thread + 2.4G** | Utmärkt | ~$22–39 |

**Om IR-timing:** renast är RP2350 PIO (12 oberoende state machines = dedikerad HW för 905 nm-pulståg, rekyl-PWM och IR-ankomststämpling med noll CPU-jitter), Teensy 4.1:s HW IR-modulator, och nRF54L:s PPI/GPIOTE. ESP32 RMT fungerar bra för IR men konkurrerar med RF-stacken på samma kärnor.

### 2.2 Nätverk för många noder, låg latens

| Alternativ | Latens | Nodantal | Determinism | Not |
|---|---|---|---|---|
| ESP-NOW (nuvarande) | 1–10 ms | **20 krypterade peers** (hård) | Dålig (CSMA, ingen QoS) | Bryts vid 32 noder med dubbelriktad telemetri |
| **5 GHz WiFi 6 (OFDMA/TWT)** | sub-ms–få ms | 30+ via AP | Bättre (RU-schemaläggning) | Flyr trängseln i 2.4 GHz; bär även video |
| Thread / 802.15.4 | få ms/hopp, mesh | hundratals, självläkande | Bra för telemetri | Klarar inte video; bra som resilient hit-/status-mesh |
| LoRa | 100-tals ms | många | n/a realtid | Endast långdistans-muster/säkerhetsbeacons |

### 2.3 Tidssynk (rättvis adjudikation)

- **NTP/SNTP:** 10-tals ms över WiFi — otillräckligt.
- **PTP / IEEE-1588 (gPTP 802.1AS):** sub-µs trådbundet, sub-ms över WiFi med PHY-tidsstämpling. Öppen `ESP1588`-klient finns för ESP32; STM32H7 har 1588-HW.
- **Praktik:** kör PTP över backhaul **och** tidsstämpla optisk IR-ankomst i HW (PIO/PPI capture) lokalt, försonat mot serverns grandmaster. Det tar bort OS/stack-jitter ur den känsligaste händelsen.

### 2.4 Rekommendation — Compute & nätverk

> **Primärt:** **ESP32-P4 + ESP32-C6** (t.ex. Waveshare ESP32-P4-WIFI6, ~$14–26). Pinna ballistik-FSM + IR/rekyl/trigger på en P4-kärna, låt C6 sköta all radio över SDIO — löser ensam-ESP32:ns kontentionsproblem direkt och ger WiFi6 + BLE + 802.15.4 för dual-radio-split. Behåller Espressif-ekosystemet.
>
> **För hårdaste IR-determinism:** lägg en **RP2350 (Pico 2, $5) som dedikerad IO-coprocessor** (12 PIO state machines → jitter-fritt pulståg + HW IR-tidsstämpling) bredvid radio-SoC:n.
>
> **Radio:** 5 GHz WiFi 6 OFDMA-backhaul till server + valfri Thread-mesh för hit/status. **Tidssynk:** PTP över backhaul + HW-tidsstämplad IR-ankomst.

---

## Del 3 — Positionering & lokalisering (mest noggrannhetskritiska delsystemet)

Rättvis träffadjudikation står och faller med positionsnoggrannheten. Mål: kontinuerlig sub-30 cm-pose ute och inne.

### 3.1 UWB — kärnan

| Modul / kit | Chip | Noggrannhet | AoA | ~Pris | Not |
|---|---|---|---|---|---|
| **Qorvo DWM3000** modul | DW3110/DW3000 | ~10 cm | nej (modul) | **$23.62** (1), EVB **$29.50** | Brett ekosystem, billigast |
| DW3220 (chip) | DW3000-familj | <5 cm, AoA | **5°** | — | AoA-kapabel variant |
| **Makerfabs MaUWB_ESP32S3** | DW3000 | ~10 cm | nej | **$46.58** | ESP32-S3 + UWB + WiFi/BLE, "unlimited anchors + 64 tags", Multi-PAN — DIY-vänligast |
| NXP SR150 (Murata Type2BP EVK) | SR150 | ~10 cm | **<3° (dual-RX), 3D med 3 antenner** | **~$148** (1) | FiRa, interop med Apple U1/Android UWB |
| NXP SR040 (Murata Type2DK EVK) | SR040 | ~10 cm | nej (tagg) | **~$100** (1) | Lågeffekttagg |

**TWR vs TDoA — avgörande för många taggar:** med klassisk **TWR** kan en tagg/ankare bara ranga i en slot åt gången → skalar dåligt. **TDoA** (envägs-blink, synkade ankare) ger teoretiskt tusentals taggar/cell, lägre tagg-effekt och latens. Priset är att **alla ankare måste vara sub-ns-synkade** (1 ns klockfel ≈ 30 cm) — den svåraste infra-biten.

**Pragmatisk nyans (viktig):** **DS-TWR (double-sided two-way ranging) + CFO-korrektion** self-cancelar klockoffset (residual ~ps), vilket **eliminerar behovet av nätverksvid sub-ns-synk**. Rekommenderad väg: börja med DS-TWR + TDMA-schemaläggning för 16–32 spelare (klarar ~10 Hz aggregerat, fördelat per tagg), och gå till uplink-TDoA endast om du behöver passiv höghastighetstracking av många taggar — och bygg då PTP/UWB-trådlös 1588-synk (~10 ns) på ankarna. Notera att Makerfabs stock-bibliotek är demo-grade single-tag — **MAC/TDMA/TDoA-lagret skriver du själv**.

### 3.2 GNSS RTK (utomhus)

- **u-blox ZED-F9P:** dubbelband (L1/L2) RTK, **0.01 m + 1 ppm CEP**, upp till 20 Hz, <10 s konvergens, Moving Base. Kräver korrektionsdata (egen bas eller NTRIP). Boards: ArduSimple simpleRTK2B ~€172 (~$185), SparkFun GPS-RTK2 **$259.95**.
- **ZED-F9R:** RTK + on-chip IMU dead-reckoning (ADR) — håller position i GNSS-skugga (urban canyon, under tak), upp till 30 Hz. SparkFun-board **$299.95**. Bra för fält med blandad täckning.
- **Heading:** ZED-F9H eller F9P-par i moving-baseline → **~0.4° heading @1 m baslinje** (förbättras med längre baslinje) — GNSS-härlett, kräver ingen magnetometer.
- Integration: GNSS ger absolut utomhusankare, UWB tar över inomhus/under tak, IMU broar glappen.

### 3.3 Sensorfusion

2025-forskning (arXiv 2512.10480, GNSS/UWB/IMU, jämför EKF/FGO/PF) ger tydligt svar: **error-state EKF (ESKF)** är mest konsekvent — bäst median/RMSE (horisontellt fel **0.44–1.73 m** i blandade scenarier; tightly-coupled ESKF når **~8–10 cm** under bra geometri), snabb, stabil kovarians. **Factor Graph Optimization (FGO)** är tyngre men vinner i NLOS-tunga miljöer (träd, byggnader, spelare som skymmer varandra) tack vare robusta loss-kärnor (Huber/Barron) — upp till ~41 % felreduktion. Kör **chest-mounted IMU-PDR som rörelse-backbone** + absoluta UWB/GNSS-uppdateringar.

**Arkitektur (rekommenderad hybrid):** kör hög-rate AHRS (x-io Fusion eller VQF, magnetometer-fritt — magnetometer är opålitlig nära vapen) + ESKF-prediktion **på noden**, skicka filtrerad pose + kovarians **och** råa UWB-ranges till servern som kör **FGO-backend (GTSAM) + ballistik/adjudikation** med global världsram. Skicka inte rå IMU (bandbredd); lös inte allt på noden (förlorar global konsistens). Survey:a varje UWB-ankare in i samma globala ram (WGS84/UTM) vid installation → ingen runtime-transform vid handoff. Hysteres-handoff (två fix-kvalitetströsklar + överlappszon) förhindrar "flapping" i dörröppningar.

### 3.4 Rekommendation — Positionering

> **Inomhus/arena:** UWB i **TDoA-läge** med synkade ankare. DIY-snabbast: **Makerfabs MaUWB_ESP32S3 ($46.58/nod)**. För vinkeldata/färre ankare: **NXP SR150-ankare ($148) + SR040-taggar ($100)** (bonus: telefoner kan agera taggar). Renaste low-cost-byggblock: **Qorvo DWM3000 ($24/modul)**.
> **Utomhus:** **u-blox ZED-F9P** (RTK-rover) + NTRIP/egen bas; **ZED-F9R** där täckningen är skuggig.
> **Fusion:** **ESKF** på servern, IMU-PDR backbone + UWB(inne)/GNSS(ute), med OSM-/banbaserad feasibility-constraint vid övergångar. Sikta sub-30 cm inne, cm-RTK ute.

---

## Del 4 — IR-engagement, IMU & optik

### 4.1 IR-emitter, kodning & räckvidd

| Väg | Del | Uteffekt | Stråle | Ögonsäkerhet | Not |
|---|---|---|---|---|---|
| **Diffuserad IR-LED (default)** | ams-OSRAM **SFH 4715AS** (860 nm) | 780 mW/sr @1A | 45–90° | **Trivialt Class 1** (inkoherent, stor källa) | ~$1; kiseldetektorer något känsligare @860 nm; ~15–40 m |
| IR-LED (bred) | SFH 4170S (860 nm) | 280 mW/sr | 130° | Class 1 | Bättre som IFF-beacon än skott |
| Pulsad 905 nm-laser | ams-OSRAM **SPL PL90 / DP90_3** | 25–65 W peak | 10–25° | **Kräver diffusor + HW-strömgräns** för Class 1 | Riktig MILES använder detta; 50–150 m+, men MÅSTE diffuseras + mätas |

**Ögonsäkerhet (icke förhandlingsbar):** riktig MILES når Class 1 via korta pulser + låg pulsenergi + **divergens/diffusion** (Army-utvärdering bekräftar att sändare modifierades och om-testades). Per IEC 60825-1 måste pulsad tillgänglig energi respektera ~514 nJ/puls skalad av C5=N^(-1/4). **Designregel: HW-strömgräns (fast resistorstak, inte bara firmware) + diffusor + uppmätt AE vid aperturen.**

**Kodning — anta MilesTag II / OpenLaserTag:** 38–56 kHz modulerad bärvåg (solljus-/sabotageförsvar), pulslängdskodning (header 2400 µs + 600 µs paus; "1"=1.2 ms, "0"=0.6 ms), paket = typ + spelar-ID + team + **4-bit damage** + extended ID. **Lägg CRC + rullande nonce** ovanpå mot replay (stock MilesTag saknar krypto). Fork: `LZRTag` (ESP32) och `milesTag`-Arduino-libbet.

### 4.2 IR-detektor

| Ansats | Solljusavvisning | Hit-zon | Latens | Dom |
|---|---|---|---|---|
| **TSOP-mottagarmoduler** (Vishay TSOP382xx/48xx/75xxx, ~$1) | Utmärkt (AGC + bärvågs-bandpass) | placera många → zoner | få ms (golv ~180–260 µs) | **Bästa DIY-default** — demodulerar i kapsel |
| Rå PIN-fotodiod (BPW34, SFH 213 FA) + TIA + bandpass | Du bygger filter/AGC själv | hög (om array) | lägst | Mer jobb; bara för custom bärvåg/finare timing |

**Täckning (kopiera MILES):** hjälm-"halo" med **6–8 mottagare** utåtvinklade (360°), torso-sele med **~8–16 mottagare** grupperade i zoner (huvud/bröst/rygg/vä/hö). ±45°-delar med ≥90° mellanrum (≥4/ring); ±75° (TSOP753) minskar antal men suddar zongränser. Kill/near-miss kodas i själva paketet. Standardisera **en bärvågsfrekvens** (38/40/56 kHz) i hela systemet, emitter+mottagare matchade. Utomhushärdning: billigt 905 nm glas-bandpass (10–30 nm FWHM) eller SFH 213 FA (inbyggt dagsljusfilter) — bara värt om emittern verkligen är 905 nm.

### 4.3 IMU-uppgradering

Per SlimeVR:s publika drift-dataset: **BNO085/086** har bekväm onboard-fusion men en "snap"-bugg vid snabb rörelse och magnetometerberoende som **fallerar nära stål** — fel verktyg intill en pipa. **ICM-42688-P** har låg gyrobrus men driver. **Rekommendation: TDK ICM-45686** (~$5 chip) i **6DOF (mag av)**, gyro-ODR **≥1–2 kHz** för att fånga sub-100 ms pip-klättringsimpuls, med egen complementary/Madgwick-fusion på host → deterministisk, tunbar rekyl-loop. Dev: TDK ICM-45686 EVAL (~$99), SlimeVR Mumo-breakout (ICM-45686+QMC6309), eller generisk breakout. BNO086 (Adafruit/SparkFun Qwiic ~$25–30) endast som snabb prototyp-stopgap.

### 4.4 AR-HUD / optik (roadmap-funktion)

Riktigt genomförbart: en **micro-OLED reflekterad in i optiken** är den beprövade vägen (Revic Radikl-smartscope ~$3995, Maztech X4-FCS ~$3495 gör exakt detta). DIY-vägar:

- **Billigaste prototyp:** Sony **micro-OLED HDMI-kit (~$185, 640×400, 2400 nit)** + 45° plattstrålsplittare i 3D-printad sikteshus; rendera reticle/ammo/träffar vit-på-svart (svart = transparent genom combiner). Funkar inomhus, marginellt i starkt dagsljus.
- **Dagsljusljusstyrka utan optik-R&D:** köp **Vuzix Z100 ($499/$799 dev)** — JBD **microLED + waveguide**, genomskinlig monokrom grön HUD läsbar ute, SDK; mata reticle/ammo över BLE.
- **Öppet/hackbart:** **Brilliant Labs Frame ($349)**, öppen HW+SW, ~3000 nit micro-OLED-prisma.
- **2026+ produktionsoptik:** färg-microLED-waveguide (Vuzix/TCL CSOT) för äkta dagsljus.

**Designtips:** monokrom grön/vit-på-svart, glanceable HUD (reticle + 2–3 siffror), 640×400 räcker (billigare/ljusare). Montera display+combiner som en "fire-control"-modul klampad över optiken (Maztech-stil) snarare än att bygga om ett kikarsikte.

### 4.5 Rekommendation — IR/IMU/optik

> **Emitter:** default **SFH 4715AS (860 nm)** + diffusor (~30 m). 905 nm-laser (SPL PL90) endast som långdistansvariant **bakom HW-strömgräns + diffusor + bänkverifierad Class 1-AE**. Firmware är aldrig ögonsäkerhetsvakt.
> **Kodning:** MilesTag II/OpenLaserTag + CRC/nonce.
> **Detektor:** zonade Vishay TSOP-moduler, hjälm-halo + torso-zoner, en bärvåg systemvitt.
> **IMU:** **ICM-45686** 6DOF, gyro ≥1–2 kHz, host-side-fusion.
> **HUD:** micro-OLED-waveguide nu → färg-microLED-waveguide 2026+.

---

## Del 5 — Kamera, edge-AI & server

### 5.1 Vapenkamera

ESP32-CAM duger för PoC men brister: **rolling shutter smetar vid snabba panoreringar**, ingen HW H.264 (bandbreddstung MJPEG), endast 2.4 GHz, ingen lågljus/IR-cut, svag per-frame-tidsstämpling.

| Alternativ | Sensor/slutare | Encode | Lågljus | Latens | Not |
|---|---|---|---|---|---|
| ESP32-CAM (nuv.) | OV2640 rolling | MJPEG (SW) | dålig | 50–80 ms @VGA | ~$8, 2.4 GHz, smetar |
| **Pi Zero 2 W + Cam Module 3 (NoIR)** | IMX708 rolling, AF | HW H.264 | bra | ~100–150 ms | ~$15 + $25–35; bäst $/funktion |
| Pi Zero 2 W/CM5 + **GS-kamera** | IMX296 **global shutter** | HW H.264 | IR-cut | ~100 ms | $50; eliminerar pan-smet — idealt för AAR |
| RunCam analog 5.8 GHz | rolling, NTSC | analog | varierar | <30 ms | lägst latens, låg uppl., ingen frame-tidsstämpel |

### 5.2 Video-backhaul (16–32 cams)

- **Analog 5.8 GHz:** lägst latens men bara ~8 rena kanaler — kan inte bära 32 strömmar; endast som enstaka live-feed.
- **Digital FPV (HDZero/Walksnail/DJI O4):** punkt-till-punkt-goggle-ekosystem, dyrt/nod, ej byggt för 32 strömmar in i en server.
- **WiFi 6/6E (rekommenderas):** standard-IP, inspelningsbart, tidsstämplat. Budget H.264: 720p30 ≈ 2–4 Mbps/cam → 32 cams ≈ 64–128 Mbps. Praktik: **flera 4×4 WiFi 6/6E-APs (OFDMA/MU-MIMO), ~8–10 cams/AP**, dedikerad video-VLAN på 5/6 GHz (håll 2.4 GHz fritt). Plana ~3–4 APs för 32 noder.

### 5.3 Edge-AI

Auto-taggning av engagemangsklipp, mål-ID, lågljusförbättring är värdefullt — men gör **inferens på servern, inte på vapnet**. Behåll bara en billig rörelse-/skott-trigger på noden för att bokmärka klipp.

| Board | TOPS | Pris | Roll |
|---|---|---|---|
| Pi 5 + AI HAT (Hailo-8L/8) | 13/26 | $70–110 | per-cam edge om det nånsin behövs |
| **NVIDIA Jetson Orin Nano Super** | upp till 67 | **$249** | bäst edge-AI-värde, CUDA |
| Google Coral | 4 | ~$60 | svagare/äldre |

### 5.4 Server & telemetristack

- **Host:** en modern **Ryzen mini-PC** (32 GB, NVMe) kör fusion + adjudikation + DB + dashboard i realtid. N100/N150 räcker om AI offloadas. Undvik moln i den heta loopen.
- **Ingest:** MQTT (Mosquitto/EMQX).
- **TSDB:** **TimescaleDB** (Postgres-extension) för blandad snabb-telemetri + relationell sessionsdata; InfluxDB 3 om rå ingest-rate dominerar.
- **Dashboard:** Grafana för analys + custom websocket-app för live-karta/adjudikationsoverlay.
- **Klocksynk:** PTP på trådbunden backbone, chrony/NTP till vapen-Pis; tidsstämpla varje frame + hit.

### 5.5 Rekommendation — Kamera/AI/server

> **Cam:** Pi Zero 2 W + Cam Module 3 NoIR (standard); GS IMX296-variant för primärvapen. ESP32 kvar som skott/hit/trigger-sensor.
> **Backhaul:** dedikerad WiFi 6E video-VLAN, 3–4×4×4-APs.
> **AI:** centralt på servern + **Jetson Orin Nano Super ($249)** som AI-coprocessor.
> **Server:** Ryzen mini-PC; MQTT → TimescaleDB → Grafana + websocket-karta; PTP+chrony.

---

## Del 6 — Rekyl, kraft & NFC

### 6.1 Rekylaktuator

- **Beprövad DIY-väg:** airsoft **reciprocerande massa** (Tokyo Marui Next Gen Recoil Shock-stil) ger realistisk muzzle-flip via en elektriskt cyklad vikt — kommersiellt mogen och hackbar.
- **Alternativ:** solenoid (enkel, hård "smäll", hög toppström, dålig termisk uthållighet vid 12 Hz), **voice-coil** (rätt fysik men off-the-shelf VCA med 30 mm slag + nog kraft för 0.12 kg är stora/dyra → opraktiskt för DIY), BLDC-svänghjul/kam med **FOC-driver** för programmerbar felt-recoil-skalning per vapenprofil.
- **Bästa DIY-praktiska valet enligt research: BLDC + vev/kam-reciprokation driven av en ODrive S1 (~$149, 12–48 V, 40 A kont., closed-loop FOC).** 12 Hz = 720 RPM är trivialt; vevradien sätter 30 mm-slaget, intensiteten tunas i firmware (RPM/acceleration/vridmomentstak). Budgetvariant: SimpleFOC Mini eller ST B-G431B-ESC1 (~$20–30). **Snabb prototyp/fallback:** hobby push-pull-solenoid (~$15–25) + MOSFET för att validera känslan på en helg. **Genväg:** skörda en Tokyo Marui NGRS-rekylmotor (~$400–550 donator) — färdig reciprocerande massa, men borstad motor utan FOC-tuning.

### 6.2 Högströmsväxling (rekylskenan, ~20 A peak)

- **Integrerad eFuse (rekommenderat): TI TPS25983** (2.7–26 V, **20 A**, 2.7 mΩ) — soft-start/inrush, OC/SC, termisk avstängning och omvänd-ström-blockering i ett chip. Sätt strömgräns + fault-timer **över** 20 A-toppen så legitima pulser inte nuisance-trippar. Alternativ: Infineon PROFET high-side för fordonsklassat omvänt-polskydd.
- **Diskret variant:** modern sub-mΩ logic-level-MOSFET (Infineon OptiMOS, t.ex. IAUA250N04S6N005 ~0.55 mΩ — IRLZ44N:s 22 mΩ ger ~9 W vid 20 A) + **snabb Schottky-flyback (SS54-klass, hellre 10–20 A)** eller TVS-clamp (SMBJ15A) för snappare ankarretur + low-ESR cap-bank (READMEns 2×2200 µF, gärna 3–6×1000 µF låg-ESR Panasonic FR + MLCC nära lasten). Driv ev. via hot-swap-controller **TPS24700/24701** för cold-mate-kontakten.
- Behåll READMEns princip: skenan på **endast mellan "rack" och "mag release"** → kontakterna bryts aldrig under last.

### 6.3 Batteri & BMS

- **Cell:** gå från löst "≥25C LiPo" till definierade högdräneringsceller: **Molicel P45B** (21700, 4500 mAh) eller **P42A** (4200 mAh), båda ~45 A — 20 A är bara ~0.5C, stor termisk marginal. Cylindriska är robustare/utbytbara/dock-laddbara vs mjuka LiPo-pouchar (LiPo vinner dock på spänningsstyvhet under burst). 2S–4S sätter spänning; gå 2P för mindre per-cell-stress.
- **Fuel gauge:** för pack-SOC (2S–4S) är **TI BQ34110** (till 65 V/32 A) den enda multicell-gaugen; för enkelcellsövervakning är **MAX17260** (ModelGauge m5, noll-config) bäst — undvik BQ27427 (integrerad 7 mΩ shunt → ~2.8 W vid 20 A).
- **BMS:** **TI BQ76952** (3–16S, hög-side-FET-drive, programmerbara OCD/SCD-delays som rider ut pulsade 20 A, autonom balansering) eller billigare **BQ76920** (3–5S). Undvik billiga DW01-protect-only-kort (underdimensionerade FET, ingen balansering/telemetri, nuisance-trippar på pulser). **Ammo-räkning och laddning är separata storheter** (README:n har rätt) — dockan = långsam BMS-cykel, NFC-omskrivning = snabb; rotera en pool av magasin.
- **Laddningsdocka:** per-bay charger-IC (**BQ25887** ger 2S med inbyggd cellbalansering; **BQ25731** för 3–4S + extern AFE), NTC på charger-TS-pin (JEITA hård-cutoff) + digital **TMP1075** (32 I²C-adresser, ~$0.46) per bay för telemetri, brandsäker zon (README:ns största brandrisk).

### 6.4 NFC / RFID

| Del | Roll | Not |
|---|---|---|
| NTAG215 (nuv.) | passiv tagg | billig men **klonbar** — svag mot fusk |
| **NTAG424 DNA** | passiv tagg + **AES-128 SUN** | dynamisk autentisering/anti-klon i HW; uppgradering mot fusk |
| PN532 (nuv. läsare) | I²C/SPI | enkel, Arduino-vänlig, kort räckvidd |
| **PN5180 / ST25R3916** | läsare | längre räckvidd, bredare tagg-stöd — snabbare/säkrare mag-detektering |

### 6.5 Rekommendation — Rekyl/kraft/NFC

> **Rekyl:** reciprocerande massa (airsoft-stil) + PWM-skalning nu; voice-coil/BLDC-FOC som per-profil-uppgradering.
> **Växling:** integrerad **eFuse/smart high-side-switch** med soft-start, behåll cold-mate-sekvensering.
> **Batteri:** **Molicel P42A/P45B** + **BQ27**-fuel-gauge + balanserande BMS; brandsäker laddningsdocka.
> **NFC:** uppgradera tagg till **NTAG424 DNA (AES/SUN)** mot klon/fusk, läsare till **PN5180/ST25R3916**; behåll HMAC + server-side-spegling.

---

## Del 7 — Säkerhet & "fairness/anti-cheat" (tvärgående)

Eftersom adjudikationen är central och spelet kompetitivt är detta ett eget spår:

- **Ögonsäkerhet i HW** (Del 4) — strömstak i resistor, inte firmware.
- **IR anti-replay** — CRC + rullande nonce/sekvens ovanpå MilesTag (Del 4.1).
- **NFC anti-klon** — NTAG424 DNA SUN + HMAC + server-side-mirror per mag-ID (Del 6.4).
- **Tidsintegritet** — PTP + HW-tidsstämplad IR-ankomst (Del 2.3) så träffordning inte kan manipuleras via nätverksjitter.
- **LiPo-säkerhet** — BMS, balansering, termisk övervakning, brandsäker docka (Del 6.3).

---

## Del 8 — Vad som saknas i repot (konkreta nästa steg)

1. Skapa `docs/strilas-systemritning.html` (eller byt referensen) — länkas men finns inte.
2. Lägg upp mappskelettet (`firmware/`, `server/`, `hardware/`, `profiles/`, `config/example.env`) så build-instruktionerna stämmer.
3. Definiera designmål för **spelarantal** (t.ex. 16–32) — dimensionerar radio/server/anchors.
4. Specificera **IR-kodningsprotokollet** explicit (MilesTag II-derivat + CRC/nonce).
5. Specificera **UWB-läge** (TDoA) och **tidssynk-budget** (sub-ms).

---

## Del 9 — Prioriterad uppgraderingsroadmap & referens-BOM

### 9.1 Roadmap (effekt vs insats)

| Prio | Uppgradering | Varför | Insats |
|---|---|---|---|
| **1** | Dela compute/radio: **ESP32-P4+C6** (ev. + RP2350 IO-coprocessor) | Tar bort timingjitter i den tidskritiska vägen | Medel |
| **1** | **PTP + HW-tidsstämplad IR-ankomst** | Rättvis, manipuleringssäker adjudikation | Medel |
| **2** | IMU **BNO085 → ICM-45686** (6DOF, ≥1 kHz) | BNO085 är EOL + fallerar på snabba metallnära transienter | Låg |
| **2** | Radio **ESP-NOW → 5 GHz WiFi 6 (OFDMA)** + Thread-mesh | Skalar till 32 noder + videobackhaul | Medel |
| **2** | UWB i **TDoA** (Makerfabs MaUWB / Qorvo DWM3000 / NXP SR150) | Skalar till många taggar, sub-30 cm | Medel–hög |
| **3** | IR-kodning **MilesTag II + CRC/nonce**; emitter **860 nm SFH 4715AS** default | Solljus-/sabotagerobust + säkrare default | Låg–medel |
| **3** | Kamera **ESP32-CAM → Pi Zero 2 W + Cam Module 3** | Tidsstämplad HW-H.264, lågljus, ingen pan-smet | Medel |
| **3** | Server: **Ryzen mini-PC** + MQTT + TimescaleDB + Grafana/websocket | Realtidsfusion/adjudikation/DB/karta för 32 noder | Medel |
| **4** | NFC **NTAG215 → NTAG424 DNA**, läsare **PN5180/ST25R3916** | Anti-klon/fusk, snabbare detektering | Låg |
| **4** | Kraft: **eFuse smart-switch** + **Molicel P42A/P45B** + BQ27/BMS | Robustare högströmsväxling + batterimarginal | Medel |
| **5** | AR-HUD: micro-OLED-waveguide → microLED 2026+ | Roadmap-funktion, reticle/ammo i optiken | Hög |
| **5** | Edge-AI: **Jetson Orin Nano Super** för auto-tagg/mål-ID | AAR-automation | Medel |

### 9.2 State-of-the-art Nivå-3-BOM (2025–2026)

Uppdaterad för **nivå 3** (geometrisk ballistik-adjudikation): UWB/GNSS/kropps-IMU/server/tidssynk är nu **kärna**, inte bonus. Senaste 2025–2026-delar.

**Vapennod**

| Subsystem | **State-of-the-art** | ~Pris | Not |
|---|---|---|---|
| Hjärna | **ESP32-P4 PICO** (P4 + C6) | ~$24 | dual-core, MIPI-CSI/DSI, H.264, ljud, WiFi6 ombord |
| Radio-uplink | **ESP32-C5** (dual-band **5 GHz** WiFi 6) där 5 GHz krävs | ~$15 | C6 (2.4 GHz) räcker annars |
| IMU (pose) | **TDK ICM-45686** (ev. **2–4 i array** → √N-brus) | ~$5/st | array = billig pose-vinst; tactical: ADIS16470 ($300–400) |
| UWB | **Qorvo DWM3001CDK / QM33110W** (tagg, TWR/TDoA) | ~$32 | AoA-ankare separat (infra) |
| IR-emitter (**samboresiktad ring**) | **ams-OSRAM SFH 4715AS (860 nm)** **×4 i kvadrat runt sikteskameran**, lensad, 3 A puls | ~$3/st | samaxlig med kameran → "det kameran siktar på = dit IR går"; dubblar som **aktiv fiducial-konstellation** (känd kvadrat → 6DoF-PnP för observerande kameror, funkar i mörker); större apparent källa → **lättare Class 1** |
| **Sikteskamera + edge-AI** (fuserad pose-väg, uppgradering, se ⓥ) | **P4 MIPI-CSI: OV5647** (rolling, v1) / **ams-OSRAM Mira220** (global shutter, NIR — P4-stödd) + ArUco-läsning, **centrerad i emitter-ringen** | $25–200 | bäring + zon + ID optiskt (HITS/TrackingPoint-vägen). **OBS: IMX296 = Pi-only, ingen P4-drivrutin** |
| Avstånd | **ur PnP** (konstellationens kända bas + vinkelutbredning); v1: inmätt med måttband | $0 | **LiDAR struken** — superseder av PnP; kan återkomma endast för markörlöst avstånd |
| NFC | **NTAG424 DNA** + **ST25R3916** | ~$1 + $20 | anti-klon/fusk |
| Rekyl | **BLDC + vev + ODrive S1** FOC | ~$149 | per-profil-kraft |
| Rekylväxling | **TI TPS25985** (80 A stapelbar eFuse) + SS54 + cap-bank | ~$5 | nyare/kraftigare än TPS25983 |
| HUD | micro-OLED-waveguide → **microLED-waveguide** 2026 | $185+ | reticle/avstånd i optiken |

**Väst/hjälm-nod**

| Subsystem | **State-of-the-art** | ~Pris |
|---|---|---|
| MCU | **ESP32-C5** (5 GHz WiFi6 + BLE + 802.15.4/Thread) | ~$15 |
| Detektorer | **Vishay TSOP4856** (56 kHz) ×16–24, zonade | ~$1/st |
| Kropps-IMU (pose) | **TDK ICM-45686** (postur stå/huk/ligg) | ~$5 |
| UWB-tagg | **DWM3001CDK / QM33110W** | ~$32 |
| **Fiducial (för kamera-pose)** | ArUco/AprilTag-mönster på väst+hjälm | ~$0 | ger ID + 6DoF-pose till sikteskameran |
| Feedback | WS2812 + haptik + I²S-ljud | ~$12 |

**Magasin:** **Molicel P50B** (21700, 5000 mAh, ~45–60 A — nyaste/bästa) + **BQ76952**-BMS + **BQ34110**-gauge + NTAG424. ~$10–14/st.

**Infrastruktur**

| Del | **State-of-the-art** | ~Pris |
|---|---|---|
| UWB-ankare (AoA) | **Qorvo QM35825** (4-antenn AoA, ±5 cm/±2°, IEEE 802.15.4-2024) ×4–8 | DK ~$599 |
| GNSS-rover (ute) | **u-blox ZED-X20P** (all-band L1/L2/L5/L6) | ~$281 |
| GNSS-heading-ankare | **u-blox ZED-X20D** dubbelantenn (**~0,1° yaw**) — *vapen-pose-ankaret* | board-pris |
| GNSS-bas (anti-jam) | **Septentrio mosaic-X5** (OSNMA/AIM+) | ~$500+ |
| Server | **Jetson Orin NX 16GB** (100 TOPS, NVDEC/NVENC 16–32 strömmar) | ~$599 |
| Server (budget) | **Jetson Orin Nano Super** (67 TOPS) | $249 |
| Nätverk | **WiFi 7-AP** (MLO 5/6 GHz) + ESP32-C5-noder på 5 GHz | $300–600 |
| Laddningsdocka | **BQ25756** (snabb) / **BQ25798** (MPPT-sol/USB-PD) per bay | — |

> **ⓥ Vapen-pose — systemets nyckelgräns (BESLUT: fuserad, alla lager samverkar):**
> 1. **ICM-45686-array** — hög-rate tilt/attityd (√N-brus).
> 2. **GNSS-dubbelantenn-heading (ZED-X20D, ~0,1°)** — absolut yaw som binder IMU-driften (ute).
> 3. **IR-stråle** — LOS-grind + heading-ankare + zon + ID, robust i allt ljus (behålls oavsett).
> 4. **Sikteskamera + edge-AI + fiducials (HITS/TrackingPoint-vägen)** — optisk bäring (~2 mrad), zon & ID ur bilden; vassast, kräver compute på/nära vapnet + degraderar i mörker (→ thermal). **Uppgradering.**
> *Tactical IMU ADIS16470 (8°/hr, $300–400) = dyrt high-end-alternativ till lager 1.*
>
> **Emitter-ring-knepet:** de 4 IR-emittrarna sitter i en kvadrat **runt kameralinsen** → fire-strålen blir *samaxlig* med kamerans optiska axel (siktbäring = IR-bäring), och samma 4 emittrar utgör en **aktiv fiducial-konstellation** som andra kameror kan PnP-pose:a på i mörker. Se [`system-flowchart.md`](system-flowchart.md) §emitter-ring.

---

## Del 10 — Valda dev boards (projektbeslut)

**Strategibeslut:** bygg Fas 1 direkt på Fas 2/nivå-3-plattformen — slipp firmware-port och få nivå-3-gränssnitten "vilande" från dag ett.

| Kort | Roll | Senaste-teknik-not |
|---|---|---|
| **ESP32-P4 PICO** (P4 + C6) | **Vapenhjärna** | MIPI-CSI-kamera + H.264 + DSI + ljud + WiFi6 ombord; ~$24 |
| **ESP32-C5** | **Väst/hjälm + 5 GHz-uplink** | dual-band WiFi6 (2025) — slår C6 för uplink; behåller Thread |
| **Qorvo QM35825** (DK) | **UWB-ankare (AoA)** | 4-antenn ±2°/±5 cm, IEEE 802.15.4-2024, integrerad M33 |
| **Qorvo DWM3001CDK** | **UWB-tagg** | billig FiRa TWR/TDoA-nod (~$32) |
| **u-blox ZED-X20P + ZED-X20D** | **GNSS-rover + heading-ankare** | all-band; X20D ger ~0,1° pose-yaw |
| **TDK ICM-45686** | **Pose-IMU** | fortf. klassledande (2025–26); array för √N-vinst |
| **Jetson Orin NX 16GB** | **Server/adjudikation/AI** | 100 TOPS + NVDEC/NVENC för 16–32 cam-strömmar |
| **ESP32-P4-NANO** | **Bas-dock / gateway** | RJ45/PoE/USB-host |
| **WitMotion IWT603** | **IMU-prototyp** → ICM-45686 | snabb bänkvalidering |

**Avvägning:** den verkliga risken (och kostnaden) ligger i **vapen-pose- & positionsnoggrannhet** — samma som primes. Därför är GNSS-heading-ankaret (X20D) + IMU-array (eller kamera/AI) den viktigaste state-of-the-art-investeringen, inte en snabbare MCU.

---

## Källor (urval)

**Compute/nätverk:** [ESP32-P4 vs S3 (Elecrow)](https://www.elecrow.com/blog/who-is-the-true-performance-king-esp32-p4-vs-esp32-s3.html) · [ESP32-P4-WIFI6 (Waveshare)](https://www.waveshare.com/wiki/ESP32-P4-WIFI6) · [ESP32-C5 dual-band $15 (CNX)](https://www.cnx-software.com/2025/04/30/esp32-c5-mass-production-esp32-c5-devkitc-1-board/) · [RP2350 PIO (Geerling)](https://www.jeffgeerling.com/blog/2024/raspberry-pi-pico-2-rp2350-adds-more-pio-risc-v-cores/) · [Teensy 4.1 (PJRC)](https://www.pjrc.com/store/teensy41.html) · [nRF54L15 (CNX)](https://www.cnx-software.com/2025/09/03/nrf54l15-connect-kit-a-compact-bluetooth-6-0-le-802-15-4-and-nfc-development-board/) · [ESP-NOW (Espressif)](https://docs.espressif.com/projects/esp-idf/en/stable/esp32/api-reference/network/esp_now.html) · [ESP1588 PTP](https://github.com/leifclaesson/ESP1588)

**Positionering:** [Qorvo DWM3000 (store)](https://store.qorvo.com/products/detail/dwm3000-qorvo/681949/) · [Makerfabs MaUWB_ESP32S3](https://www.makerfabs.com/mauwb-esp32s3-uwb-module.html) · [NXP SR150](https://www.nxp.com/products/SR150) · [NXP SR040](https://www.nxp.com/products/wireless-connectivity/trimension-uwb/trimension-sr040-reliable-uwb-solution-for-iot:SR040) · [Murata Type2BP EVK (Mouser)](https://www.mouser.com/ProductDetail/Murata-Electronics/LBUA0VG2BP-EVK-P) · [TDoA vs TWR (Inpixon)](https://www.inpixon.com/blog/uwb-localization-tdoa-vs-twr) · [u-blox ZED-F9P](https://www.u-blox.com/en/product/zed-f9p-module) · [ZED-F9R](https://www.u-blox.com/en/product/zed-f9r-module) · [GNSS/UWB/IMU fusion EKF/FGO/PF (arXiv 2512.10480)](https://www.arxiv.org/abs/2512.10480)

**IR/IMU/optik:** [ams-OSRAM SFH 4715AS](https://look.ams-osram.com/m/3a147ddac0391319/original/SFH-4715AS.pdf) · [SPL DP90_3 905 nm](https://ams-osram.com/products/lasers/ir-lasers-eel/osram-ir-laser-diode-spl-dp90-3) · [IEC 60825-1](https://webstore.iec.ch/en/publication/3587) · [Army MILES laser-safety (OSTI)](https://osti.gov/biblio/793320-laser-safety-evaluation-miles-mini-miles-laser-emitting-components) · [OpenLaserTag protokoll](https://openlasertag.org/language/en/openlasertag-ir-communication-protocol/) · [MilesTag II spec](https://wiki.cuvoodoo.info/lib/exe/fetch.php?media=ir-cock-grenade:mt2proto.pdf) · [LZRTag](https://hackaday.io/project/160804-lzrtag-flexible-diy-lasertag) · [Vishay TSOP382](https://www.vishay.com/docs/82491/tsop382.pdf) · [SlimeVR IMU-jämförelse](https://docs.slimevr.dev/diy/imu-comparison.html) · [TDK ICM-45686 (DigiKey)](https://www.digikey.com/en/products/detail/tdk-invensense/ICM-45686/24374985)

**Kamera/AI/server:** [Pi-kameraguide](https://thinkrobotics.com/blogs/learn/raspberry-pi-camera-module-comparison-complete-2025-guide) · [GS-kamera (Geerling)](https://www.jeffgeerling.com/blog/2023/testing-raspberry-pis-new-global-shutter-camera/) · [Jetson Orin Nano $249](https://videocardz.com/newz/nvidia-launches-jetson-orin-nano-developer-kit-at-249-mini-pc-for-developers) · [TSDB-jämförelse](https://www.tigerdata.com/blog/timescaledb-vs-influxdb-for-time-series-data-timescale-influx-sql-nosql-36489299877) · [PTP (Teledyne)](https://www.teledynevisionsolutions.com/learn/learning-center/machine-vision/precision-system-synchronization-with-the-ieee-1588-precision-time-protocol-ptp/)

**Rekyl/kraft/NFC:** [TI smart eFuse](https://www.ti.com/product-category/power-management/high-side-switches-controllers/smart-efuse/overview.html) · [Infineon eFuses](https://infineon.com/products/power/smart-power-switches/efuses) · [Molicel P42A](https://www.18650batterystore.com/products/molicel-p42a) · [Molicel P45B](https://imrbatteries.com/products/molicel-p45b-21700-4500mah-45a-battery) · [NXP NTAG424 DNA](https://www.nxp.com/products/rfid-nfc/nfc-hf/ntag-for-tags-and-labels/ntag-424-dna-424-dna-tagtamper-advanced-security-and-privacy-for-trusted-iot-applications:NTAG4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) · [ST25R3916 (Elechouse)](https://www.elechouse.com/product/st25r3916_nfc_reader/) · [Tokyo Marui NGRS (Evike)](https://www.evike.com/products/56862/)

**Senaste teknik (2025–2026):** [Qorvo QM35825 (4-antenn AoA)](https://www.qorvo.com/products/p/QM35825) · [QM35825DK-05 (DigiKey ~$599)](https://www.digikey.com/en/products/detail/qorvo/QM35825DK-05/26742402) · [Qorvo DWM3001CDK](https://www.digikey.com/en/products/detail/qorvo/DWM3001CDK/24367348) · [NXP SR250 (UWB-radar+AoA)](https://www.cnx-software.com/2024/09/20/nxp-trimension-sr250-short-range-uwb-radar-supports-secure-ranging-for-smart-homes-and-industrial-iot/) · [u-blox ZED-X20P](https://www.u-blox.com/en/zed-x20p) · [ZED-X20D heading (Inside GNSS)](https://insidegnss.com/u-blox-introduces-zed-x20d-gnss-heading-module-for-mass-market-high-precision-applications/) · [Quectel LG290P quad-band](https://www.cnx-software.com/2024/07/30/quectel-lg290p-world-first-quad-band-gnss-module-l1-l2-l5-and-e6/) · [Septentrio mosaic-X5](https://www.septentrio.com/en/products/gnss-receivers/gnss-receiver-modules/mosaic-x5) · [ADI ADIS16470 (tactical IMU)](https://www.analog.com/en/products/adis16470.html) · [Jetson Orin NX / AGX Orin](https://www.hackster.io/news/nvidia-launches-275-tops-jetson-agx-orin-developer-s-kit-at-1-999-bbb5ff80e050) · [Jetson Thor T5000](https://nvidianews.nvidia.com/news/nvidia-blackwell-powered-jetson-thor-now-available-accelerating-the-age-of-general-robotics) · [ESP32-C5 (5 GHz WiFi6)](https://www.cnx-software.com/2025/04/30/esp32-c5-mass-production-esp32-c5-devkitc-1-board/) · [WiFi 7 / MLO (Meraki)](https://documentation.meraki.com/Wireless/Design_and_Configure/Architecture_and_Best_Practices/Wi-Fi_7_(802.11be)_Technical_Guide) · [Molicel P50B vs P45B](https://www.aboutenergy.io/post/molicel-p50b-vs-p45b-key-differences-specifications) · [TI TPS25985 (80 A eFuse)](https://www.ti.com/product/TPS25985) · [TI BQ25798 (MPPT-sol)](https://www.ti.com/product/BQ25798)

**Kamera/AI-pose (HITS/TrackingPoint-vägen):** [BAE HITS (ION 2020)](https://www.ion.org/publications/abstract.cfm?articleID=17741) · [TrackingPoint](https://en.wikipedia.org/wiki/TrackingPoint) · [Lockheed SIMRES](https://www.lockheedmartin.com/en-us/products/simres.html) · [ArUco-markörer (OpenCV)](https://docs.opencv.org/4.x/d5/dae/tutorial_aruco_detection.html) · [Benewake TF02-Pro LiDAR](https://en.benewake.com/TF02Pro/)

---

*Underlagsrapport för STRILAS. Säkerhetsbegränsningarna (IR Class 1 i HW, cold-mate-kontakter, BMS-laddning) är icke förhandlingsbara i varje hårdvaruändring — i linje med README:ns bidragsregler.*

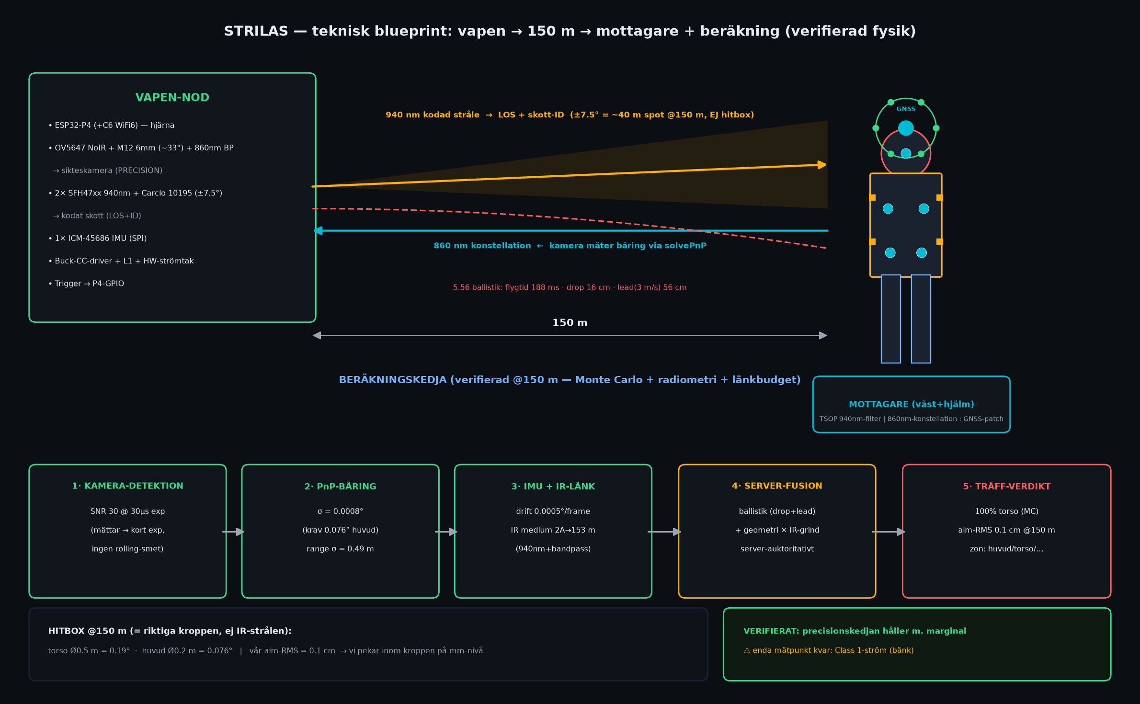
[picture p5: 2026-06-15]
hardware/system-blueprint.png

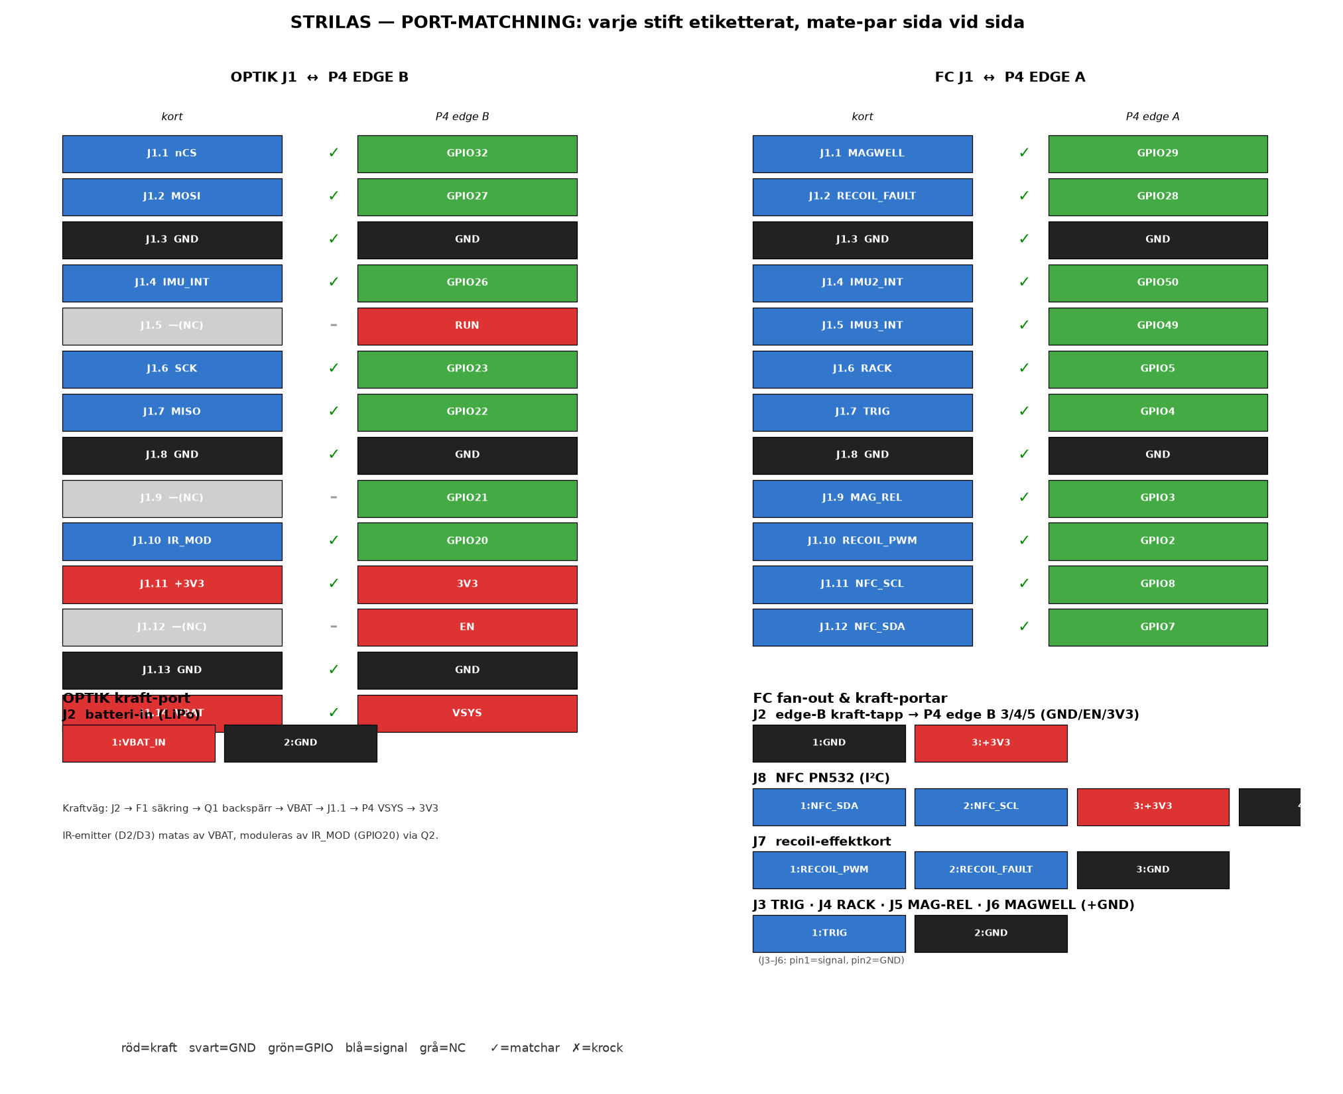
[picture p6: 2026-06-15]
hardware/port-matching.png

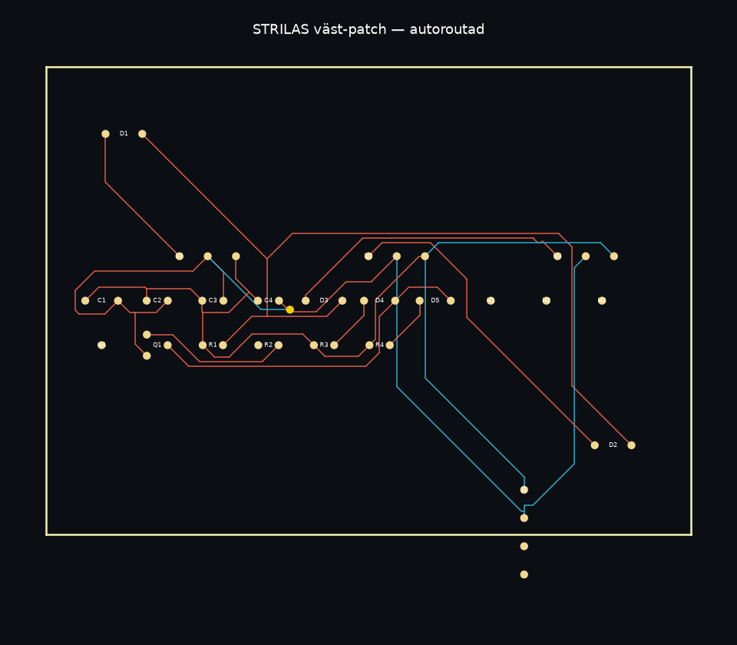
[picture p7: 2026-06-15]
hardware/vest-patch-routed.png

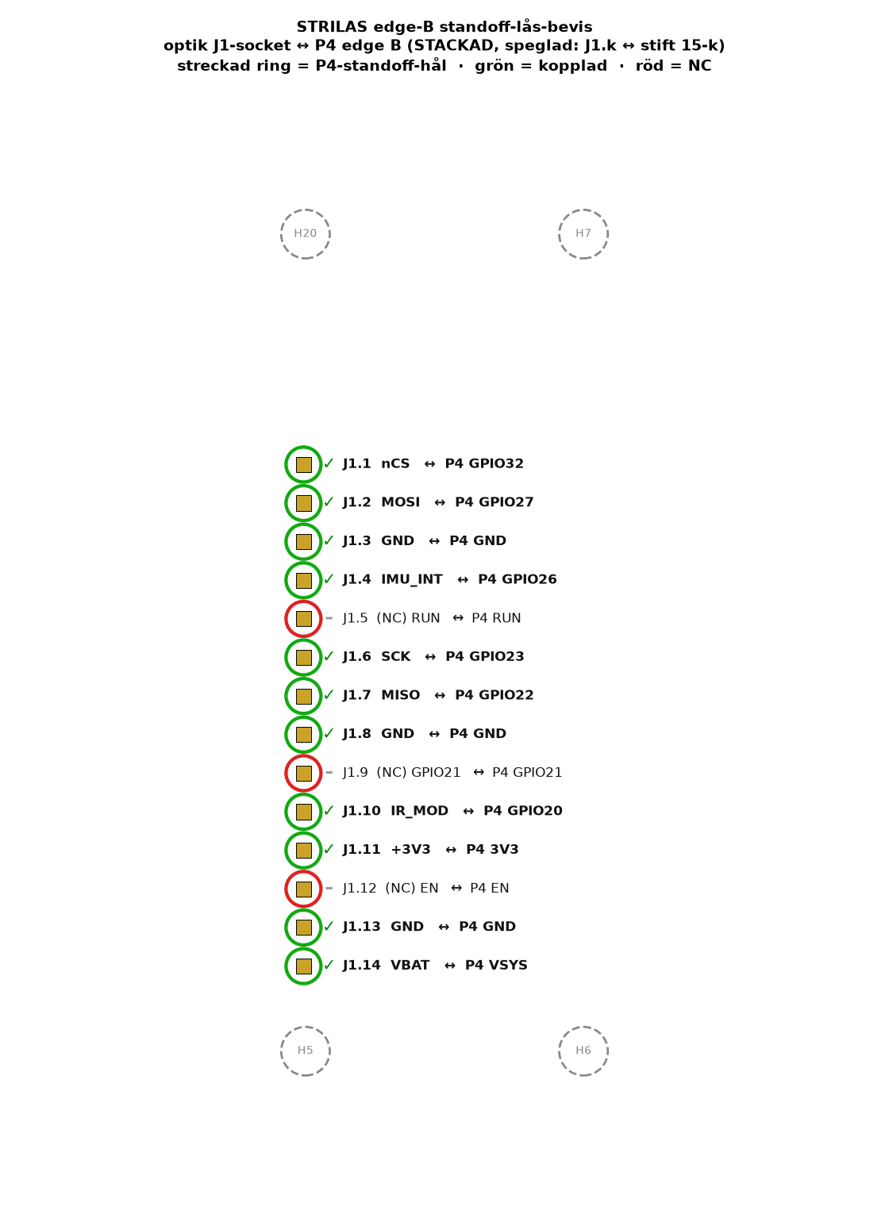
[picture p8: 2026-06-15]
hardware/edgeB-match-proof.png

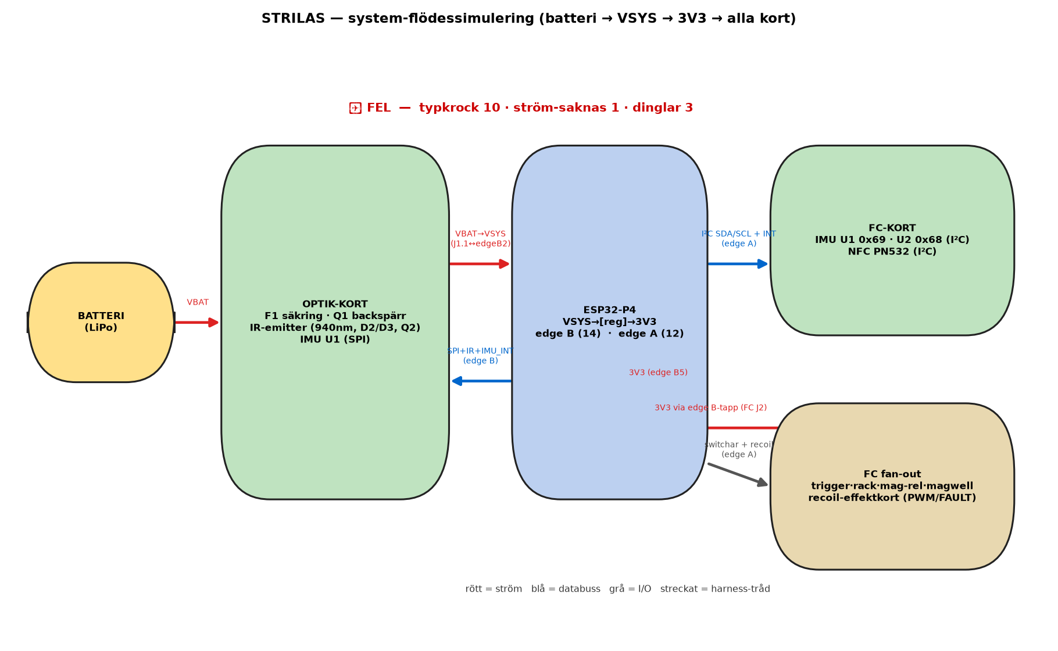
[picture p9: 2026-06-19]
hardware/system-flow.png

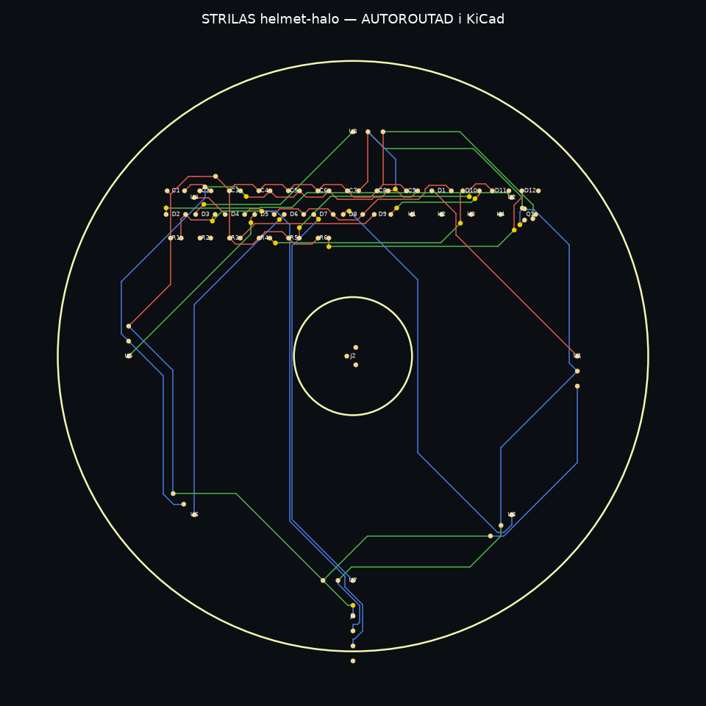
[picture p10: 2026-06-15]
hardware/helmet-halo-routed.png

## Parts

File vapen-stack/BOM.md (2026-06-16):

# STRILAS vapen-stack — komplett BOM

Stack: **optik (weapon-module) → ESP32-P4 → fire-control**. 3V3 matas batteri→VSYS→P4-reg→3V3 (FC via edge-B-tapp).

## Optik (weapon-module)  (38 st)

| Antal | Referenser | Värde | Footprint | Typ |
|---|---|---|---|---|
| 1 | R1 | 100k | `Resistor_SMD:R_0805_2012Metric` | elektrisk |
| 2 | C3,C4 | 100nF | `Capacitor_SMD:C_0402_1005Metric` | elektrisk |
| 1 | C2 | 100uF | `Capacitor_SMD:C_1210_3225Metric` | elektrisk |
| 1 | C1 | 10uF | `Capacitor_SMD:C_1206_3216Metric` | elektrisk |
| 1 | C5 | 1uF | `Capacitor_SMD:C_0805_2012Metric` | elektrisk |
| 1 | R3 | 220R | `Resistor_SMD:R_0805_2012Metric` | elektrisk |
| 1 | J2 | 2S batteri (JST-XH) | `Connector_JST:JST_XH_S2B-XH-A_1x02_P2.50mm_Horizontal` | elektrisk |
| 2 | R2,R4 | 6R8 | `Resistor_SMD:R_2512_6332Metric` | elektrisk |
| 1 | Q2 | AO3400 | `Package_TO_SOT_SMD:SOT-23` | elektrisk |
| 1 | Q1 | AO3401 | `Package_TO_SOT_SMD:SOT-23` | elektrisk |
| 1 | U1 | IIM-42653 | `strilas:InvenSense_LGA-14_2.5x3mm_ICM-456xx` | elektrisk |
| 1 | J1 | P4-socket (edge B) | `Connector_PinSocket_2.54mm:PinSocket_1x14_P2.54mm_Vertical` | elektrisk |
| 1 | F1 | PTC_1A | `Fuse:Fuse_1206_3216Metric` | elektrisk |
| 2 | D2,D3 | SFH4725S_940nm | `strilas:IR_Emitter_OSRAM_OSLON_Black_SFH4725S` | elektrisk |
| 1 | D1 | SMBJ12A | `Diode_SMD:D_SMB` | elektrisk |
| 8 | H12,H13,H14,H15,H16,H17,H18,H19 | Carclo10734-ben_Ø2.1 | `MountingHole:MountingHole_2.1mm` | mekanik |
| 8 | H1,H2,H20,H3,H4,H5,H6,H7 | M2.5 | `MountingHole:MountingHole_2.5mm` | mekanik |
| 4 | H10,H11,H8,H9 | M2_kamera | `MountingHole:MountingHole_2.2mm_M2` | mekanik |

## Fire-control  (22 st)

| Antal | Referenser | Värde | Footprint | Typ |
|---|---|---|---|---|
| 5 | C1,C3,C4,C5,C6 | 100nF | `Capacitor_SMD:C_0402_1005Metric` | elektrisk |
| 1 | C2 | 1uF | `Capacitor_SMD:C_0402_1005Metric` | elektrisk |
| 2 | R1,R2 | 4k7 | `Resistor_SMD:R_0805_2012Metric` | elektrisk |
| 2 | U1,U2 | IIM-42653 | `strilas:InvenSense_LGA-14_2.5x3mm_ICM-456xx` | elektrisk |
| 1 | J6 | MAGWELL_SW | `Connector_JST:JST_PH_B2B-PH-K_1x02_P2.00mm_Vertical` | elektrisk |
| 1 | J5 | MAG_REL_SW | `Connector_JST:JST_PH_B2B-PH-K_1x02_P2.00mm_Vertical` | elektrisk |
| 1 | J8 | NFC PN532 (I²C) | `Connector_JST:JST_PH_B4B-PH-K_1x04_P2.00mm_Vertical` | elektrisk |
| 1 | J1 | P4-socket (edge A) | `Connector_PinSocket_2.54mm:PinSocket_1x12_P2.54mm_Vertical` | elektrisk |
| 1 | J4 | RACK_SW | `Connector_JST:JST_PH_B2B-PH-K_1x02_P2.00mm_Vertical` | elektrisk |
| 1 | J3 | TRIGGER | `Connector_JST:JST_PH_B2B-PH-K_1x02_P2.00mm_Vertical` | elektrisk |
| 1 | J2 | edge-B kraft-tapp 3V3+GND | `Connector_PinSocket_2.54mm:PinSocket_1x03_P2.54mm_Vertical` | elektrisk |
| 1 | J7 | recoil-styrning | `Connector_JST:JST_PH_B3B-PH-K_1x03_P2.00mm_Vertical` | elektrisk |
| 4 | H1,H2,H3,H4 | M2 | `MountingHole:MountingHole_2.2mm_M2` | mekanik |

## P4-carrier (lödbara headers på Waveshare-modulen)  (8 st)

| Antal | Referenser | Värde | Footprint | Typ |
|---|---|---|---|---|
| 1 | J_CAM | PinHeader_1x04_P2.54mm_Vertical | `PinHeader_1x04_P2.54mm_Vertical` | elektrisk |
| 1 | J_A | PinHeader_1x12_P2.54mm_Vertical | `PinHeader_1x12_P2.54mm_Vertical` | elektrisk |
| 1 | J_B | PinHeader_1x14_P2.54mm_Vertical | `PinHeader_1x14_P2.54mm_Vertical` | elektrisk |
| 1 | USBC | USB_C_Receptacle_HRO_TYPE-C-31-M-12 | `USB_C_Receptacle_HRO_TYPE-C-31-M-12` | elektrisk |
| 4 | MP1,MP2,MP3,MP4 | MountingHole_2.2mm_M2 | `MountingHole_2.2mm_M2` | mekanik |

## Externa moduler (kabelanslutna)

| Antal | Artikel | Variant | Not |
|---|---|---|---|
| 1 | ESP32-P4-WIFI6 | Waveshare | Huvudprocessor (Pico-format). Edge B→optik, edge A→FC. |
| 1 | PN532 NFC-modul | modul | Magasin-NFC. Kabel → FC J8 (I²C, 3V3). |
| 1 | USB-kamera (OV9281/B0332) | modul | Kabel → P4 J_CAM (USB 2.0). |
| 1 | LiPo-batteri | — | Kabel → optik J2 (VBAT). |
| 1 | Recoil-effektkort | separat PCB | eFuse+aktuator. Kabel → FC J7 (PWM/FAULT/GND). |
| 4 | Mikrobrytare | — | Trigger/rack/mag-release/magwell. Kabel → FC J3–J6. |
| 4 | M2-standoff + skruv | 15 mm | Genomgående stack: optik–P4–FC. |

**PCB-komponenter totalt: 68 st** (exkl. externa moduler).

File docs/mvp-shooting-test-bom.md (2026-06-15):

# STRILAS — v1 skjut-test: exakt inköpslista

> **Detta är version 1 av hur vapnet är TÄNKT att fungera — inte vanlig peka-och-skjut
> laser tag.** Minsta bygget som visar STRILAS-konceptet på riktigt: vapnet fångar sin
> **siktriktning (IMU)** vid avtryck, skickar en **FireEvent** (riktning + tid + IR-kod)
> till en **adjudikator** som modellerar ballistiken och avgör träff — med **IR-strålen
> som siktlinje-ankare + zon**, inte som hela sanningen. **P4-familjen hela vägen.**

## Vad v1 faktiskt visar (skiljer det från laser tag)

1. **PRECIST sikte (kärnan):** sikteskameran mäter bäringen till målets **aktiva
   IR-konstellation** via solvePnP → **sub-0,1°** relativ bäring. IMU:n fyller mellan
   bildrutorna (hög-rate) + rekyl. *Det här* är precisionen — inte strålbredden.
2. **Server-avgjort:** vapen + mål skickar *bevis* (FireEvent / IRHit) över WiFi; en
   liten **adjudikator avgör** — exakt nivå-3-loopen i miniatyr.
3. **IR-skottstråle = LOS + skott-ID, inte hitbox:** bred kon (länkbudget), geometrin
   gör precisionen (se `level3-ballistic-architecture.md` §3.2).
4. **Riktig räckvidd + precision (100–150 m):** kollimerad emitter (räckvidd) +
   sikteskamera (NoIR) + aktiv IR-konstellation (precis bäring på avstånd) — ingen
   leksak som bara pekar åt rätt håll.

**Server = din laptop/PC** för v1 (ingen Jetson behövs än). **Precisionen är RELATIV**
(kameran mäter vapen→mål direkt) → därför behövs **varken GNSS-heading eller UWB i v1**;
de kommer när spelare rör sig över fält och mål inte alltid är i sikte. Målets grova
position mäts in med måttband.

## Kort — köp 2× samma kit (minimal variation)

| Antal | Del | Roll | ~Pris |
|---|---|---|---|
| **2** | **ESP32-P4-WIFI6-KIT-A** (P4 + C6 **WiFi 6** + **kamera** + **högtalare** + mic) | 1 = **vapen**, 1 = **mål** | ~$32/st |

Identisk hårdvara i båda → en toolchain (ESP-IDF), en sak att lära sig. Kamera +
högtalare ingår i kitet och stannar i scope (pose-väg + ljud senare).

> *Har du redan ETH-kitet (PoE) kan det bli målet istället — men 2× samma WIFI6-kit
> är enklast.*

## Vapnet — emitter (100–150 m) + precis sikteskamera

**A. Skottstråle (räckvidd + LOS):**

| # | Del | Antal | ~Pris | Not |
|---|---|---|---|---|
| 1 | **IR-LED ams-OSRAM SFH 4715AS** (860 nm) | 2 | ~$2 | high-power, tål **1–3 A pulsat** |
| 2 | **TIR-kollimator** (Carclo 10195 ~20 mm, för SFH 4715AS) | 1–4 | ~$3/st | **räckvidd** (bred kon ok — inte precision) |
| 3 | **Logic-level N-MOSFET** AO3400 | 2 | ~$1 | gate från RMT (56 kHz) |
| 4 | **Rsense ~1–3 Ω 2W** + **reservoarcap** 100–470 µF + 220 Ω gate + ¼W-sortiment | 1 sats | ~$6 | resistorn = HW-strömgräns (ögonsäkerhet); cap levererar pulsen |
| 5 | **Mikrobrytare** (trigger) | 1 | ~$1 | |

**B. Precis bäring (det som gör det till mer än en leksak):**

| # | Del | Antal | ~Pris | Not |
|---|---|---|---|---|
| 6 | **TDK ICM-45686 breakout** | 1 | ~$12 | hög-rate attityd + rekyl, fyller mellan kamerabildrutor |
| 7 | **16 mm M12-lins** (utan IR-cut) till sikteskameran | 1 | ~$8 | **krävs för 150 m** (13,7° FOV → 24 px konstellation; 6 mm = bara ~80 m) |
| 8 | **850/860 nm IR-pass/bandpass-filter** (M12-gänga) för sikteskameran | 1 | ~$8 | isolerar konstellationen från dagsljus → robust SNR |
| 9 | Perfboard + lödd LED-strömväg + Dupont | 1 | ~$6 | **löd LED+driver fast** — breadboard tål inte 1–3 A |

> **Sikteskamera = Arducam B0332** (1 MP **OV9281 mono global shutter**, **USB-UVC**, M12-fäste, ~$30)
> → P4:ans USB OTG, ingen drivrutin. Sensorn ser NIR (850 nm) i grunden. **Byt stock-vidvinkeln mot
> 16 mm-lins** (rad 7) + **IR-pass-filter** (rad 8) → 13,7° FOV och ren 860 nm-detektion. **Global
> shutter** → ingen pan-smet. **Fysik:** 16 mm krävs för robust 150 m (1 MP @ 6 mm upplöser bara ~9 px).
> Se [`hardware/camera-selection.md`](../hardware/camera-selection.md) + verifieringsrapporten. CV-firmwaren skriver jag.

IMU på I²C; RMT driver gaten på 56 kHz; kameran via FFC till P4 MIPI-CSI.

## Målet — komponenter att koppla till kit #2

Målet gör nu **två** saker: **syns** (IR-konstellation som vapnets kamera pose:ar på) +
**registrerar skott** (TSOP avkodar strålen).

| # | Del | Antal | ~Pris | Not |
|---|---|---|---|---|
| 1 | **IR-LED 860 nm (vidvinkel)** för **konstellationen** | 4 | ~$3 | i **känd geometri** (PnP-mål) — mät basen exakt, t.ex. ~0,5 m |
| 2 | Liten MOSFET/transistor-driver för konstellationen | 1 | ~$1 | P4 modulerar (blink-ID + skiljer från bakgrund/sol) |
| 3 | **Vishay TSOP4856** (56 kHz) | 4 | ~$4 | tar emot skottstrålen (zon/täckning) |
| 4 | **860 nm bandpass-glasfilter** | 4 | ~$8 | TSOP utomhus-räckvidd i solljus |
| 5 | Status-LED + kablar | 1 | ~$2 | **högtalaren finns i kitet** = träffljud |
| 6 | Fysiskt mål: kartong/foamboard | 1 | – | montera TSOP + konstellation; LED:erna bör ~rama in hitbox-arean |

## Precisionsmekanism (varför detta inte är en leksak)

1. Målets **IR-konstellation** (4 LED i känd geometri) lyser; vapnets **NoIR + IR-pass-
   kamera** ser dem som ljuspunkter (funkar dag/natt, på avstånd).
2. **solvePnP** på de 4 punkterna → målets **3D-pose relativt vapnet** (riktning + avstånd).
3. **Boresight = kamerans optiska axel** (kalibrerad). Servern skjuter ballistik-banan
   längs boresight och kollar om den (med drop) skär målets **hitbox-kapslar**, definierade
   *relativt konstellationen*. Allt i relativ ram → **ingen GNSS/UWB behövs**.
4. **IMU** predikterar mellan kamerabildrutor (16–33 ms) + ger rekyl/tilt.

Vinkelprecision: kameran ger sub-pixel-bäring ≪ 0,1° → upplöser torso (0,19° @150 m)
och nästan huvud (0,076°). **Bringup-tips:** börja CV:n med en stor tryckt **ArUco** på kort
håll (enklast), byt till aktiv IR-konstellation för full räckvidd/mörker.

## ⚠️ Den enda regeln som måste stämma

**Bärvåg = mottagarfrekvens: 56 kHz.** Emittern moduleras på 56 kHz, TSOP**4856**
lyssnar på 56 kHz. Blanda inte 38/56 kHz — då ser målet ingenting.

## ⚠️ Ögonsäkerhet — nu på riktigt (1–3 A kollimerad)

Den här emittern är **inte** trivialt säker som en 100 mA-LED. Att kollimera 1–3 A till
±5° ger hög radians → **du måste beräkna/mäta accessible emission (AE) vid aperturen och
sätta en hårdvaru-strömgräns** (strömsättningsresistorn = vakten, inte firmware).

- En **LED är inkoherent + utsträckt källa** → långt mer förlåtande än en laser, men inte gratis.
- **Sikta 1 A först.** Behöver du mer räckvidd, lös det hellre med bandpassfilter på mottagaren
  än med mer ström.
- **Bänkmät** (eller räkna konservativt per IEC 60825-1) innan du pekar den mot någon.

> *Be om en Class 1-strömbudget-kalkyl (max ström för given strålvinkel + källstorlek) innan bygget.*

## Verktyg

Lödkolv + tenn (**LED-strömvägen ska lödas**, inte breadboardas — 1–3 A), multimeter.
Helst en optisk effektmätare för AE-verifiering.

**Total ~$145** — varav $64 är de två korten du ändå vill ha för projektet.

---

*När korten + komponenterna är hemma skriver jag firmware + adjudikator:*
- *Vapen (P4): **kamera → IR-blob-detektion → solvePnP mot konstellationen → relativ
  bäring (sub-0,1°)**; IMU fyller mellan bildrutor; vid trigger → FireEvent (bäring +
  pose + tid + IR-kod) över WiFi + skjut kodad 56 kHz-stråle. Kamerakalibrering en gång.*
- *Mål (P4): driv IR-konstellationen (blink-ID) + TSOP → IRHit (zon, IR-kod, tid) → ljud.*
- *Adjudikator (laptop): ballistik-bana längs kamerabäringen → geometri mot målets
  hitbox-kapslar → grinda mot IR-LOS → träff/miss/zon. Nivå-3-loopen i smått.*

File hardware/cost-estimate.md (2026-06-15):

# STRILAS — PCB-kostnadsuppskattning (prototyp)

> Grova 2026-priser (JLCPCB/PCBWay-klass, frakt till EU). Varierar med fab/region/datum.
> Tre delar: **bart kort** (billigt) · **komponenter** (mellan) · **montering** (störst för fin-pitch).

## 1. Bart kort (fab, 5 st = minsta order)

| Kort | Storlek | Lager | ~Pris/5 st |
|---|---|---|---|
| Vapen-optikmodul | 42×62 mm | **4** | $20–40 |
| Väst-detektor-patch | 58×42 mm | 2 | $2–5 |
| Hjälm-halo | Ø100 mm | 2 | $10–20 |
| Frakt (EU) | — | — | ~$20 |

**Bara korten (alla tre, 5 st var + frakt): ~$50–85.** Själva kortet är alltså *billigt* —
4-lagret + frakten dominerar.

## 2. Komponenter (per monterat kort)

| Kort | Delar (utöver P4-kit/kamera) | ~Pris |
|---|---|---|
| **Vapen-modul** | 2× 940 nm-LED $4 · 2× Carclo 10195 $6 · ICM-45686 $8 · buck-CC + L1 + caps + FET + diod + skydd $12 · kontakter $4 · passiva $3 | **~$37** |
| **Väst-patch** | 3× TSOP4856 $3 · 2× IR-LED $1 · OR-dioder/driver $1 · 940 nm-filter ×3 $6 · kontakt+passiva $2 | **~$13** |
| **Hjälm-halo** | 8× TSOP $8 · 4× IR-LED $2 · GNSS-patch-antenn $8 · 940 nm-filter ×8 $16 · kontakt+passiva $3 | **~$37** |

*(GNSS-mottagaren ZED-X20 (~$280) sitter på väst-noden, ej på halon, och är full-system — ej v1.)*

## 3. Montering — här är den verkliga frågan

- **Hand-lödning (din tid = gratis):** TSOP, LED, kontakter går fint för hand. **Men**
  ICM-45686 (LGA), buck-driver-IC (QFN) och kamera-FFC är **fin-pitch** → svårt utan
  hetluft/stencil.
- **Fab-montering (JLCPCB SMT):** ~$8 setup + deras delar + ~per-joint → **+$30–60/kort**
  vid små serier. Rekommenderas för IMU + driver.

## 4. Realistiska totaler

| Scenario | Kostnad |
|---|---|
| **v1 skjut-test** (vapen-modul + 1 väst-patch, hand-lödd) | **~$95–150** |
| Full sats (vapen + väst + halo), hand-lödd | ~$130–190 |
| Samma, med fab-montering av fin-pitch | +$50–120 |

*(Utöver de 2× ESP32-P4-WIFI6-kit ~$64 du redan räknat.)*

## Ärliga noter

- **Korten är inte dyra** — fin-pitch-**monteringen** (IMU/driver/kamera) är det som kostar tid/pengar.
- **Frakt dominerar** små order → beställ alla kort i en order.
- **Volym:** vid 16–32 spelare faller kort-pris till ~$1–3/st och montering amorteras; **komponenterna** står still.
- **Full per-spelare-system** (vapen + väst + hjälm + magasin + batteri + ev. GNSS/rekyl/HUD) är en
  större siffra — storleksordning **$200–500/spelare** beroende på tillval. Men *att göra själva
  PCB:n* är den billiga biten.

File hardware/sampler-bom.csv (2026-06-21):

Designator | Quantity | Manufacturer Part Number | Footprint | Comment
D1 | 1 | SFH4715AS | IR_Emitter_OSRAM_OSLON_Black_SFH4725S | OSRAM 860nm OSLON ~780mW/sr (original)
D2 | 1 | SFH4715S | IR_Emitter_OSRAM_OSLON_Black_SFH4725S | OSRAM 850nm OSLON Nanostack
D3 | 1 | SFH4715 | IR_Emitter_OSRAM_OSLON_Black_SFH4725S | OSRAM 850nm OSLON 90°
D4 | 1 | SFH4716AS | IR_Emitter_OSRAM_OSLON_Black_SFH4725S | OSRAM 850nm OSLON 150°
D5 | 1 | SFH4716S | IR_Emitter_OSRAM_OSLON_Black_SFH4725S | OSRAM 850nm OSLON Nanostack 150°
D6 | 1 | VSMY98545 | IR_Emitter_OSRAM_OSLON_Black_SFH4725S | Vishay 850nm ±45° 350mW/sr@1A 1600@5Apuls (PULS=bäst)
D7 | 1 | VSMY2853G | IR_Emitter_OSRAM_OSLON_Black_SFH4725S | Vishay 850nm ±28° (svagare)
D8 | 1 | VSMY3850 | LED_PLCC-2_3.4x3.0mm_AK | Vishay 850nm
D9 | 1 | VSMY1850X01 | LED_PLCC-2_3.4x3.0mm_AK | Vishay 850nm hög-hastighet
D10 | 1 | L1I0-0850050200000 | LED_PLCC-2_3.4x3.0mm_AK | Lumileds LUXEON IR 850nm 50° (HÖG intensitet)
D11 | 1 | L1I0-0850060000000 | LED_PLCC-2_3.4x3.0mm_AK | Lumileds LUXEON IR 850nm 60° (hög intensitet)
D12 | 1 | L1I0-0850090000000 | LED_PLCC-2_3.4x3.0mm_AK | Lumileds LUXEON IR 850nm 90° 750mW/sr (VF 3,2V→1LED/gren)
D13 | 1 | L1I0-0850150000000 | LED_PLCC-2_3.4x3.0mm_AK | Lumileds LUXEON IR 850nm 150° 335mW/sr
D14 | 1 | L1I0-0850955800000 | LED_PLCC-2_3.4x3.0mm_AK | Lumileds LUXEON IR 850nm 95×58° asymmetrisk
D15 | 1 | RS-3535MWAR | LED_PLCC-2_3.4x3.0mm_AK | NationStar 850nm 3535 (verifiera IR ej RGB!)
D16 | 1 | RS-3535MWAM | LED_PLCC-2_3.4x3.0mm_AK | NationStar 850nm 3535
D17 | 1 | 15435385AA350 | LED_PLCC-2_3.4x3.0mm_AK | Würth WL-SIMW 855nm 3535
D18 | 1 | 15435394A3050 | LED_PLCC-2_3.4x3.0mm_AK | Würth 850nm 3535
D19 | 1 | IN-P32ZTIR | LED_PLCC-2_3.4x3.0mm_AK | Inolux 850nm 3535
D20 | 1 | HIR19-21C/L11 | LED_PLCC-2_3.4x3.0mm_AK | Everlight 850nm

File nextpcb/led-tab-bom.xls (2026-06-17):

Designator* | Quantity* | Manufacturer Part Number* | Manufacturer | Package/Footprint | Description | Procurement Type | Customer Note
D1 | 1 | SFH 4715AS | ams OSRAM | OSLON Black SMD | IR-LED 860nm OSLON Black (konstellation, på 90°-tab) | C | NextPCB SMT-PLACERAR; kund levererar LED:n. J1=2-håls fot: kund löder en RIGHT-ANGLE (90°) stiftlist → tab står stelt lodrät (ingen handböjning)
J1 | 1 | 2.54-1x02-RA | generisk | PinHeader_1x02_P2.54mm_Horizontal | Right-angle (90°) stiftlist 1x02 2.54mm — håller LED-tab lodrät utan böjning | DNP | Kund lödder själv (right-angle list; pinnarna ner i moderkortets LED_Tab-sockel)

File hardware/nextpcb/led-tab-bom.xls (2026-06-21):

Designator* | Quantity* | Manufacturer Part Number* | Manufacturer | Package/Footprint | Description | Procurement Type | Customer Note
D1 | 1 | L1I0-0850090200000 | Lumileds | L1I0_IR | IR-LED 850nm LUXEON IR Domed 90° (konstellation, på 90°-tab; ~750mW/sr@1A ≈2× VSMY, 1.5A DC-rating, Vf~3.2V) | C | NextPCB SMT-PLACERAR; 850nm matchar kamera-bandpass (rejekterar 940nm-taggen). Pinout pad1=K verif. SamacSys; vår footprint pad2=K (konsekvent m schema)
J1 | 1 | 2.54-1x02-RA | generisk | PinHeader_1x02_P2.54mm_Horizontal | Right-angle (90°) stiftlist 1x02 2.54mm — håller LED-tab lodrät utan böjning |  | Handlöds av kund hemma (THT right-angle) — med i BOM, ej i centroid

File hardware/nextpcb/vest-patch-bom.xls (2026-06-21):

Designator* | Quantity* | Manufacturer Part Number* | Manufacturer | Package/Footprint | Description | Procurement Type | Customer Note
R7 | 1 |  |  | R_0805_2012Metric | 0R1 DNP=1A/montera=3A | DNP | 3A-override (Rp): DNP = säker 1A fail-safe default; montera för 3A (medvetet labbeslut, kräver förnyad ögonsäkerhetsmätning)
R6 | 1 | WSL1206R2000FEA | Vishay | R_1206_3216Metric | Res 0.2R 1% 0.5W 1206 Kelvin-sense (lågt TCR) — patch-CC-sänka sätter ~1A (Vref/Rs); P=I²R≈0,2W < 0,5W |  | 1206 (kompakt f. tät väst-patch); 1% sense → ström-/ögonsäkerhetsstabilitet
R2 | 1 | RC0805FR-07100RL | Yageo | R_0805_2012Metric | Res 100R 1% 0805
C2,C3,C4,C5,C6 | 5 | CL21B104KBCNNNC | Samsung | C_0805_2012Metric | MLCC 100nF 50V X7R 0805 — IN STOCK
R1 | 1 | RC0805FR-0710KL | Yageo | R_0805_2012Metric | Res 10k 1% 0805
C1 | 1 | CL31A106KBHNNNE | Samsung | C_1206_3216Metric | MLCC 10uF 25V X5R 1206 — IN STOCK
R8 | 1 | RC0805FR-0715KL | Yageo | R_0805_2012Metric | Res 15k 1% 0805 — CC-referensdelare (övre)
R3,R4,R5 | 3 | RC1206FR-071RL | Yageo | R_1206_3216Metric | Res 1R 1% 1/4W 1206 — konstellations-gren-balansering (CC-sänka sätter total ström) |  | Default 1A → 0,33A/gren → 0,11W ≪ 0,25W. OBS 3A-override: 1A/gren → 1W → uppgradera till 1R 1W (2010) + termik-koll vid medvetet 3A-labbeslut
R9 | 1 | RC0805FR-071KL | Yageo | R_0805_2012Metric | Res 1k 1% 0805 — CC-referensdelare (undre)
Q1 | 1 | AO3400A | Alpha & Omega | SOT-23 | N-MOSFET 30V SOT-23 (väst LED-driver 56kHz)
D1,D2,D3,D4 | 4 | BAT54-7-F | Diodes Inc | D_SOD-123 | Schottky SOD-123 (OR av TSOP-utgångar)
J2 | 1 | S2B-PH-K-S(LF)(SN) | JST | JST_PH_S2B-PH-K_1x02_P2.00mm_Horizontal | JST-PH 2-pol header 2.0mm (J2) → ERM coin-motor (Ø10×3mm 3V, t.ex. Vybronics VC1027B028F) PLUGGAS IN. + → 3V3 (EJ VBAT!), − → VIB. Motorn fästs m 3M-tejp i keepout-ringen baksida. | DNP | Kund handlöder själv (THT/ledad) — DNP: NextPCB monterar EJ, ej i centroid. Med i BOM som beställningsreferens.
D5,D6 | 2 | L1I0-0850090200000 | Lumileds | L1I0_IR | IR-LED 850nm LUXEON IR Domed 90° SMD 3.7×3.7mm, ~750 mW/sr@1A (≈2× VSMY), 1.5A DC / 5A puls, Vf~3.2V@1A (konstellation) |  | NextPCB sourcar + SMT-placerar (precision). 850nm matchar kamerans bandpass (rejekterar 940nm-taggen). Pinout pad1=K verif. SamacSys; vår footprint pad2=K (konsekvent m schema, D1 rot180 på led-tab). Starkare → når räckvidd vid LÄGRE ström → eye-safety-marginal ökar (men kräver ommätning, se eye-safety-budget.md)
D7,D8,D9,D10 | 4 |  |  | LED_Tab | LED-tab (L1I0-micro-PCB, ben böjs 40° UT som TSOP) | DNP | Kund handlöder själv (THT/ledad) — DNP: NextPCB monterar EJ, ej i centroid. Med i BOM som beställningsreferens.
U5 | 1 | OPA171AIDBVR | Texas Instruments | SOT-23-5 | Op-amp 36V 3MHz SOT-23-5 — CC-sänkans regulator
U1,U2,U3,U4 | 4 | TSOP4856 | Vishay | Vishay_MOLD-3Pin | IR-mottagare 56 kHz (940 nm), LEDAD MOLD-3 (genomplåt/THT) | DNP | Kund handlöder själv (THT/ledad) — DNP: NextPCB monterar EJ, ej i centroid. Med i BOM som beställningsreferens.
J1 | 1 | S6B-PH-K-S(LF)(SN) | JST | JST_PH_S6B-PH-K_1x06_P2.00mm_Horizontal | JST-PH 6-pol header 2.0mm THT SIDOMONTERAD (S-typ) på patchens BAKSIDA → matchar moderkortets zon-kontakt (pin6=VIB till motorn) | DNP | Kund handlöder själv (THT/ledad) — DNP: NextPCB monterar EJ, ej i centroid. Med i BOM som beställningsreferens.

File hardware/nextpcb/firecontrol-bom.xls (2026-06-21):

Designator* | Quantity* | Manufacturer Part Number* | Manufacturer | Package/Footprint | Description | Procurement Type | Customer Note
C1,C3,C4,C5,C6 | 5 | GRM155R71H104KE14D | Murata | C_0402_1005Metric | MLCC 100nF 50V X7R 0402 — IN STOCK (byt fr Samsung CL05B104KO5NNNC: 4-20 d lead → kapat; samma 50V X7R-spec, billigare). Lager-koll cap-sampler
C2 | 1 | CL05A105KP5NNNC | Samsung | C_0402_1005Metric | MLCC 1uF 10V X5R 0402 — IN STOCK
J10 | 1 | B3B-PH-K-S(LF)(SN) | JST | JST_PH_B3B-PH-K_1x03_P2.00mm_Vertical | JST-PH 3-pol header 2.0mm vertikal THT → 4-läges rotary/mode-väljare |  | MONTERAS av NextPCB (kontakt-test) — sourcas + THT-monteras, ej handlödd
R1,R2,R3,R4 | 4 | RC0805FR-074K7L | Yageo | R_0805_2012Metric | Res 4.7k 1% 1/8W 0805
U1,U2 | 2 | ICM-42688-P | TDK InvenSense | InvenSense_LGA-14_2.5x3mm_ICM-456xx | 6-axlig hög-precisions-IMU LGA-14 2.5×3mm — ultralågt gyro-brus ~2.8 mdps/√Hz, ±2000dps/±16g; pin-kompatibel drop-in mot IIM-42653 |  | Vald för prototyp (i lager hos NextPCB, lägst brus → bäst INS-fusion)
J6 | 1 | B2B-PH-K-S(LF)(SN) | JST | JST_PH_B2B-PH-K_1x02_P2.00mm_Vertical | JST-PH 2-pol header 2.0mm THT |  | MONTERAS av NextPCB (kontakt-test) — sourcas + THT-monteras, ej handlödd
J5 | 1 | B2B-PH-K-S(LF)(SN) | JST | JST_PH_B2B-PH-K_1x02_P2.00mm_Vertical | JST-PH 2-pol header 2.0mm THT |  | MONTERAS av NextPCB (kontakt-test) — sourcas + THT-monteras, ej handlödd
J8 | 1 | B4B-PH-K-S(LF)(SN) | JST | JST_PH_B4B-PH-K_1x04_P2.00mm_Vertical | JST-PH 4-pol header 2.0mm THT |  | MONTERAS av NextPCB (kontakt-test) — sourcas + THT-monteras, ej handlödd
J9 | 1 | B4B-PH-K-S(LF)(SN) | JST | JST_PH_B4B-PH-K_1x04_P2.00mm_Vertical | JST-PH 4-pol header 2.0mm vertikal THT → OLED SSD1306-modul (I²C) |  | MONTERAS av NextPCB (kontakt-test) — sourcas + THT-monteras, ej handlödd
J1 | 1 | DS1023-1X15SF11 | Ckmtw | PinSocket_1x15_P2.54mm_Vertical | Stiftsockel 1x15 2.54mm THT (hona) — P4 edge A | DNP | Kund handlöder själv (THT/ledad) — DNP: NextPCB monterar EJ, ej i centroid. Med i BOM som beställningsreferens.
J4 | 1 | B2B-PH-K-S(LF)(SN) | JST | JST_PH_B2B-PH-K_1x02_P2.00mm_Vertical | JST-PH 2-pol header 2.0mm THT |  | MONTERAS av NextPCB (kontakt-test) — sourcas + THT-monteras, ej handlödd
J3 | 1 | B2B-PH-K-S(LF)(SN) | JST | JST_PH_B2B-PH-K_1x02_P2.00mm_Vertical | JST-PH 2-pol header 2.0mm THT |  | MONTERAS av NextPCB (kontakt-test) — sourcas + THT-monteras, ej handlödd
J2 | 1 | DS1023-1X3SF11 | Ckmtw | PinSocket_1x03_P2.54mm_Vertical | Stiftsockel 1x03 2.54mm THT (hona) — kraft-tapp | DNP | Kund handlöder själv (THT/ledad) — DNP: NextPCB monterar EJ, ej i centroid. Med i BOM som beställningsreferens.
J7 | 1 | B3B-PH-K-S(LF)(SN) | JST | JST_PH_B3B-PH-K_1x03_P2.00mm_Vertical | JST-PH 3-pol header 2.0mm THT |  | MONTERAS av NextPCB (kontakt-test) — sourcas + THT-monteras, ej handlödd

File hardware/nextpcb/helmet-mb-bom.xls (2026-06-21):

Designator* | Quantity* | Manufacturer Part Number* | Manufacturer | Package/Footprint | Description | Procurement Type | Customer Note
R15 | 1 |  |  | R_0805_2012Metric | 0R1 DNP=1A/montera=3A | DNP | 3A-override (Rp): DNP = säker 1A fail-safe default; montera för 3A (medvetet labbeslut, kräver förnyad ögonsäkerhetsmätning)
R14 | 1 | WSL1206R2000FEA | Vishay | R_1206_3216Metric | Res 0.2R 1% 0.5W 1206 Kelvin-sense (lågt TCR) — patch-CC-sänka sätter ~1A (Vref/Rs); P=I²R≈0,2W < 0,5W |  | 1206 (kompakt f. tät väst-patch); 1% sense → ström-/ögonsäkerhetsstabilitet
R4 | 1 | RC0805FR-07100RL | Yageo | R_0805_2012Metric | Res 100R 1% 0805
R11,R13 | 2 | RC0805FR-07100KL | Yageo | R_0805_2012Metric | Res 100k 1% 1/8W 0805
C1,C4,C5,C6,C7,C8,C9,C14,C16,C17 | 10 | GRM155R71H104KE14D | Murata | C_0402_1005Metric | MLCC 100nF 50V X7R 0402 — IN STOCK (byt fr Samsung CL05B104KO5NNNC: 4-20 d lead → kapat; samma 50V X7R-spec, billigare). Lager-koll cap-sampler
C22,C23 | 2 | CL21B104KBCNNNC | Samsung | C_0805_2012Metric | MLCC 100nF 50V X7R 0805 — IN STOCK
R2,R3 | 2 | RC0805FR-0710KL | Yageo | R_0805_2012Metric | Res 10k 1% 0805
C2,C10,C13 | 3 | CL31A106KBHNNNE | Samsung | C_1206_3216Metric | MLCC 10uF 25V X5R 1206 — IN STOCK
R16 | 1 | RC0805FR-0715KL | Yageo | R_0805_2012Metric | Res 15k 1% 0805 — CC-referensdelare (övre)
R5,R6,R7 | 3 | RC2512FK-071RL | Yageo | R_2512_6332Metric | Res 1R 1% 1W 2512 — hjälm-konstellations-gren-balansering (CC-sänka sätter total ström); 1W-paket tål 3A-override (1A/gren → 1W) |  | 2512 (behåller hjälm-mb:s ring-routning vid 10R→1R-byte; 1W-rating klarar 3A-labbeslut utan uppgradering)
R17 | 1 | RC0805FR-071KL | Yageo | R_0805_2012Metric | Res 1k 1% 0805 — CC-referensdelare (undre)
C11,C12,C15,C18,C19,C20,C21 | 7 | CL05A105KP5NNNC | Samsung | C_0402_1005Metric | MLCC 1uF 10V X5R 0402 — IN STOCK
R8 | 1 | RC0805FR-072K2L | Yageo | R_0805_2012Metric | Res 2.2k 1% 0805 — electret-mik-bias
C3 | 1 | CL31A226KAHNNNE | Samsung | C_1206_3216Metric | MLCC 22uF 25V X5R 1206 — buck-utgång
J10 | 1 | S2B-XH-A(LF)(SN) | JST | JST_XH_S2B-XH-A_1x02_P2.50mm_Horizontal | JST-XH 2-pol header 2.5mm THT (2S-batteri) |  | MONTERAS av NextPCB (kontakt-test) — sourcas + THT-monteras, ej handlödd
R1 | 1 | RC0805FR-0731K6L | Yageo | R_0805_2012Metric | Res 31.6k 1% 0805 — buck FB (övre, 3.33V)
L1 | 1 | SWPA5040S4R7MT | Sunlord | L_Changjiang_FNR5040S | Effektinduktor 4.7uH 5x5mm (buck) — IN STOCK (byt fr Changjiang FNR5040320R47M som krävde manuell offert; samma FNR5040-footprint) |  | Isat≈2.8A > 2A buck-topp ✓ (verifierad mot AP63203)
R12 | 1 | RC0805FR-0747KL | Yageo | R_0805_2012Metric | Res 47k 1% 0805 — batteri-sense-delare (undre)
R9,R10 | 2 | RC0805FR-074K7L | Yageo | R_0805_2012Metric | Res 4.7k 1% 1/8W 0805
Q1 | 1 | AO3400A | Alpha & Omega | SOT-23 | N-MOSFET 30V SOT-23 (väst LED-driver 56kHz)
Q2 | 1 | AO3401A | Alpha & Omega | SOT-23 | P-MOSFET -30V SOT-23 (omvändpolaritets-skydd)
U1 | 1 | AP63203WU-7 | Diodes Inc | TSOT-23-6 | Synk-buck 3.8-32Vin 2A TSOT23-6 — 2S→3V3 @1A
D1,D2,D3,D4 | 4 | BAT54-7-F | Diodes Inc | D_SOD-123 | Schottky SOD-123 (OR av TSOP-utgångar)
U7 | 1 | ES8388 | Everest Semiconductor | ES8388_QFN-28_4x4mm_P0.5mm | Stereo audio-codec QFN-28 (analog mik-preamp + I²S DAC/ADC, I²C 0x10) — 3,3V |  | NextPCB SMT-placerar; pinout verifierad mot Everest ES8388-UG
U2 | 1 | ICM-42688-P | TDK InvenSense | InvenSense_LGA-14_2.5x3mm_ICM-456xx | 6-axlig hög-precisions-IMU LGA-14 2.5×3mm — ultralågt gyro-brus ~2.8 mdps/√Hz, ±2000dps/±16g; pin-kompatibel drop-in mot IIM-42653 |  | Vald för prototyp (i lager hos NextPCB, lägst brus → bäst INS-fusion)
D5,D6,D7,D8,D9,D10 | 6 |  |  | LED_Tab | LED-tab (VSMY98545 på micro-PCB med ben → böjs/vinklas; ledad) | DNP | Kund handlöder själv (THT/ledad) — DNP: NextPCB monterar EJ, ej i centroid. Med i BOM som beställningsreferens.
J6 | 1 | S2B-PH-K-S(LF)(SN) | JST | JST_PH_S2B-PH-K_1x02_P2.00mm_Horizontal | JST-PH 2-pol header 2.0mm THT SIDOMONTERAD (S-typ, låg bygghöjd) — analog bom-electret-mik |  | MONTERAS av NextPCB (kontakt-test) — sourcas + THT-monteras, ej handlödd
U9 | 1 | OPA171AIDBVR | Texas Instruments | SOT-23-5 | Op-amp 36V 3MHz SOT-23-5 — CC-sänkans regulator
J9 | 1 | DS1023-1X20SF11 | Ckmtw | PinSocket_1x20_P2.54mm_Vertical | Stiftsockel 1x20 2.54mm THT (hona) — P4-WIFI6 edge A (signaler) |  | MONTERAS av NextPCB (kontakt-test) — sourcas + THT-monteras, ej handlödd
J8 | 1 | DS1023-1X20SF11 | Ckmtw | PinSocket_1x20_P2.54mm_Vertical | Stiftsockel 1x20 2.54mm THT (hona) — P4-WIFI6 edge B (kraft) |  | MONTERAS av NextPCB (kontakt-test) — sourcas + THT-monteras, ej handlödd
U8 | 1 | PAM8302AASCR | Diodes Inc | SOIC-8_3.9x4.9mm_P1.27mm | 2,5W mono klass-D-amp (öronhögtalare) — SO-8 |  | verifiera SO-8-SKU mot footprint
F1 | 1 | MF-MSMF300/16-2 | Bourns | Fuse_1812_4532Metric | PTC resättbar 3A-hold 16V 1812 — matningsskydd |  | OBS 2S 8,4V KRÄVER 16V-märkt (6V-varianter som miniSMDC300F duger EJ). In-stock 16V-variant utvärderas via sampler v2; MF-MSMF300/16 = orderbar referens
J11 | 1 | S2B-PH-K-S(LF)(SN) | JST | JST_PH_S2B-PH-K_1x02_P2.00mm_Horizontal | JST-PH 2-pol header 2.0mm THT SIDOMONTERAD (S-typ) — PTT-knapp |  | MONTERAS av NextPCB (kontakt-test) — sourcas + THT-monteras, ej handlödd
J2,J3,J4,J5 | 4 | S5B-PH-K-S(LF)(SN) | JST | JST_PH_S5B-PH-K_1x05_P2.00mm_Horizontal | JST-PH 5-pol header 2.0mm THT SIDOMONTERAD (S-typ) → dubbel-aim-patch (hjälm-moderkort) |  | MONTERAS av NextPCB (kontakt-test) — sourcas + THT-monteras, ej handlödd
J12 | 1 | SM06B-GHS-TB(LF)(SN) | JST | JST_GH_SM06B-GHS-TB_1x06-1MP_P1.25mm_Horizontal | JST GH 6-pol SMD-sockel → kabel till alt-RTK-puck (UM980/F9P all-in-one) |  | 6-pols-syskon till J1 (SM08B-GHS-TB). ALTERNATIV puck: montera ENDERA J1 (8-pol ZED-F9P) ELLER J12 (6-pol); båda kontakterna placeras, pucken pluggas i en. VERIFIERA kabel-pinout
D11 | 1 | SMBJ12A | Littelfuse | D_SMB | TVS unidir 12V SMB
J7 | 1 | S2B-PH-K-S(LF)(SN) | JST | JST_PH_S2B-PH-K_1x02_P2.00mm_Horizontal | JST-PH 2-pol header 2.0mm THT SIDOMONTERAD (S-typ) — öronhögtalare (mono) |  | MONTERAS av NextPCB (kontakt-test) — sourcas + THT-monteras, ej handlödd
U3,U4,U5,U6 | 4 | TSOP4856 | Vishay | Vishay_MOLD-3Pin | IR-mottagare 56 kHz (940 nm), LEDAD MOLD-3 (genomplåt/THT) | DNP | Kund handlöder själv (THT/ledad) — DNP: NextPCB monterar EJ, ej i centroid. Med i BOM som beställningsreferens.
J1 | 1 | SM08B-GHS-TB(LF)(SN) | JST | JST_GH_SM08B-GHS-TB_1x08-1MP_P1.25mm_Horizontal | JST GH 8-pol SMD-sockel → kabel till ZED-F9P RTK-puck |  | ZED-F9P-puck köps separat (komplett: F9P+antenn+IST8310-kompass, centrum-monterad); VERIFIERA kabel-pinout

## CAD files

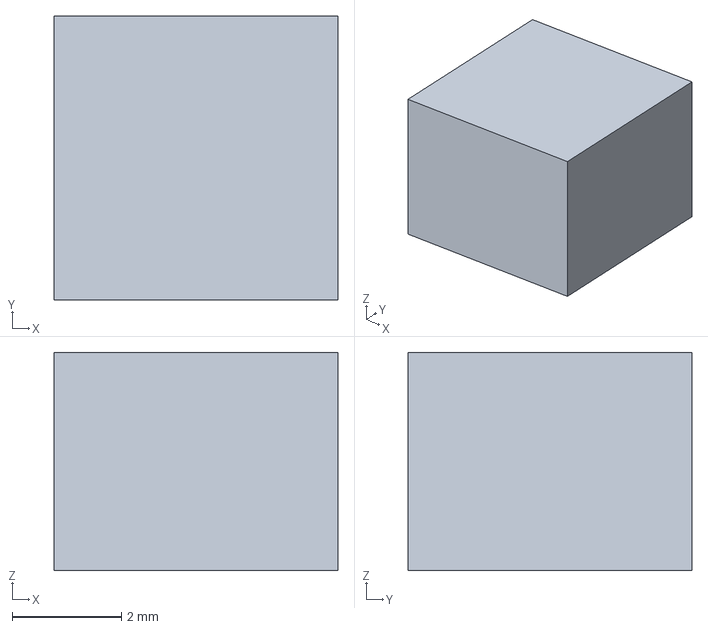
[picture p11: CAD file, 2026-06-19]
hardware/strilas-3d/L_Changjiang_FNR5040S.step
5.20 x 5.20 x 4.00 mm

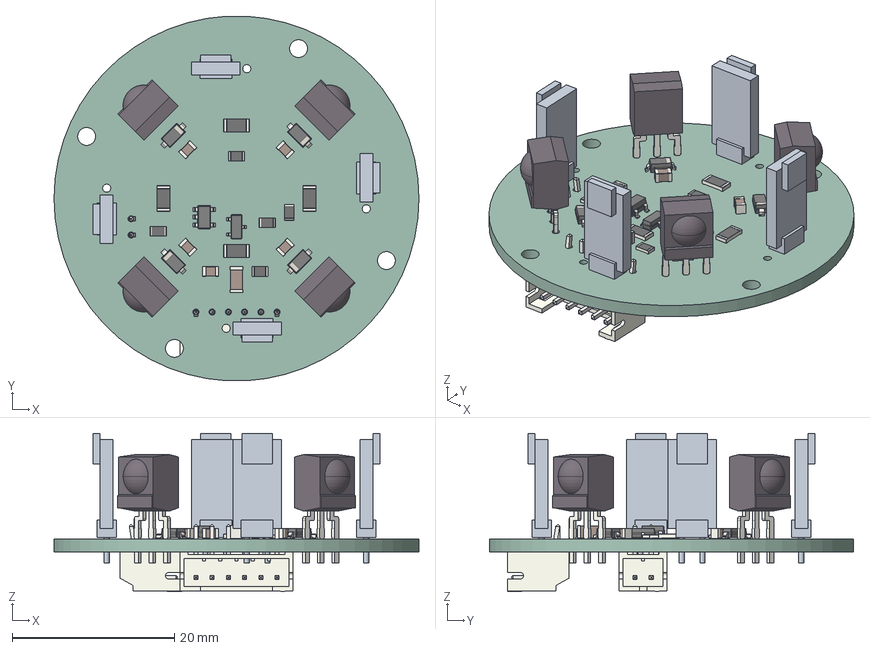
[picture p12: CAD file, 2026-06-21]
hardware/vest-patch.step
45.0 x 44.9 x 19.5 mm
C_0805_2012Metric x 5
D_SOD_123 x 4
R_1206_3216Metric x 4
Vishay_MOLD-3pin x 4
C_1206_3216Metric
R_0805_2012Metric x 5
SOT_23
SOT_23_5
JST_S6B_PH_K
JST_S2B_PH_K
vest-patch PCB

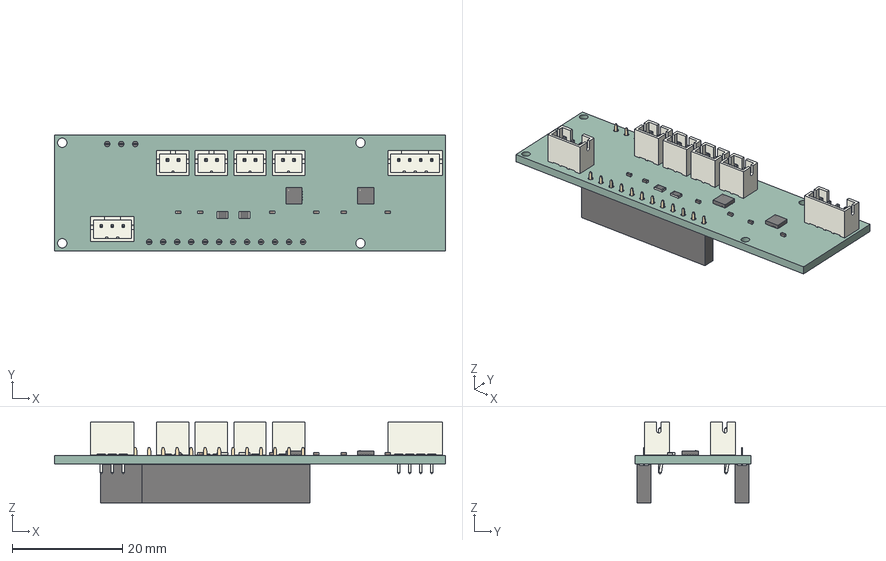
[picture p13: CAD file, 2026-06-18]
leverans/firecontrol/firecontrol.step
71.0 x 21.0 x 14.7 mm
JST_B3B_PH_K
C_0402_1005Metric x 6
QFN-16-1EP_3x3mm_P0.5mm_EP1.7x1.7mm x 2
JST_B2B_PH_K x 4
R_0805_2012Metric x 2
JST_B4B_PH_K
PinSocket_1x03_P254mm_Vertical
PinSocket_1x12_P254mm_Vertical
firecontrol PCB

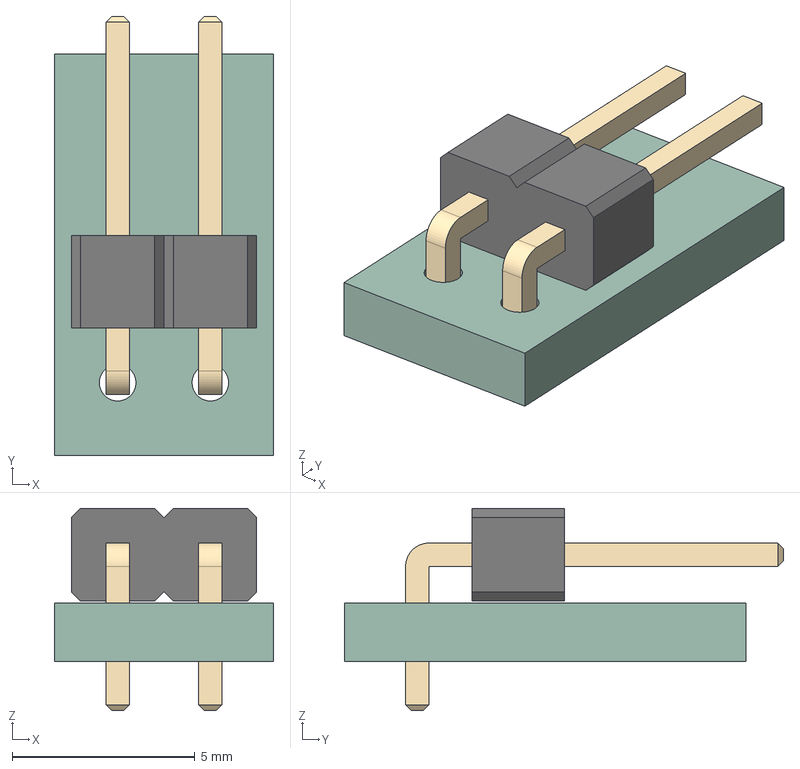
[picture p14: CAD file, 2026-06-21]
leverans/led-tab/led-tab.step
6.00 x 12.0 x 5.54 mm
PinHeader_1x02_P254mm_Horizontal
led-tab PCB

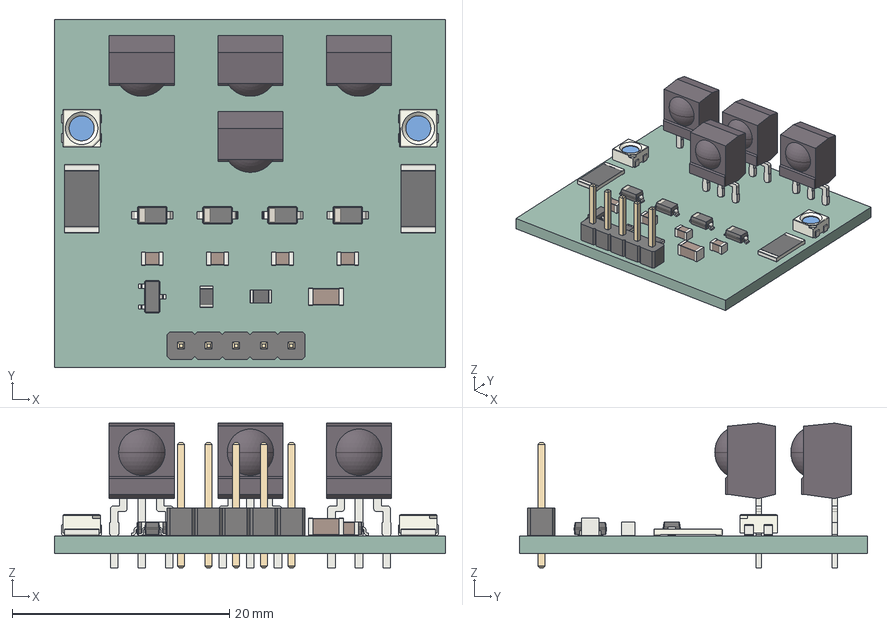
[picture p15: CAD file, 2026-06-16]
vapen-stack/vest-patch.step
36.0 x 32.0 x 13.3 mm
Vishay_MOLD-3pin x 4
R_2512_6332Metric x 2
R_0805_2012Metric x 2
LED_WS2812B-Mini_PLCC4_3.5x3.5mm_P1.8mm x 2
D_SOD_123 x 4
C_0805_2012Metric x 4
SOT_23
C_1206_3216Metric
PinHeader_1x05_P254mm_Vertical
vest-patch PCB

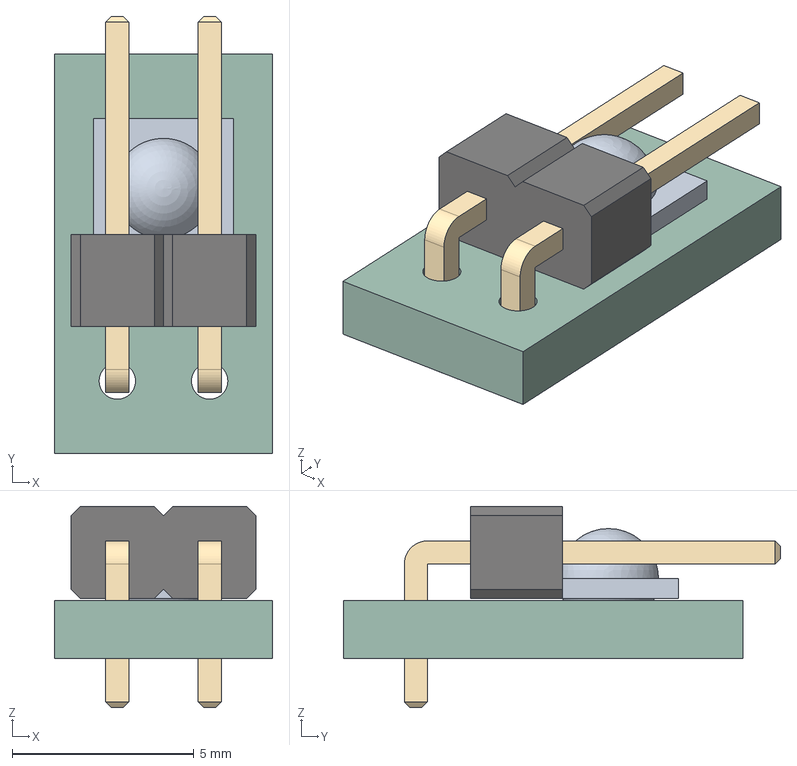
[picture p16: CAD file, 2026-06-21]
hardware/led-tab.step
6.00 x 12.0 x 5.54 mm
PinHeader_1x02_P254mm_Horizontal
led-tab PCB

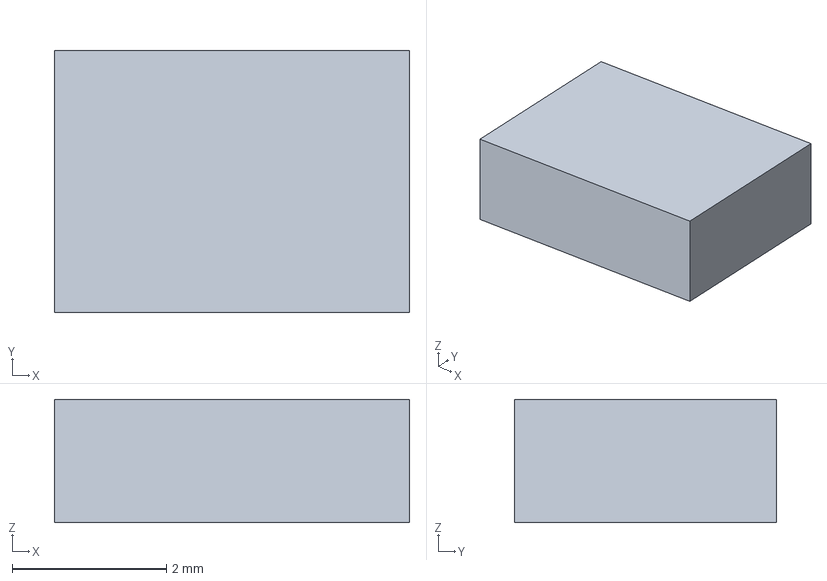
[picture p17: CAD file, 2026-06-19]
hardware/strilas-3d/Fuse_1812_4532Metric.step
4.60 x 3.40 x 1.60 mm

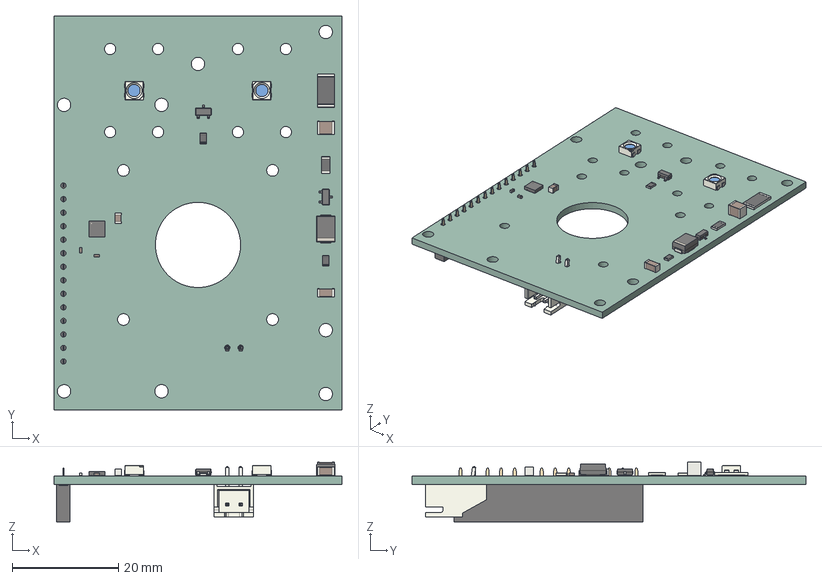
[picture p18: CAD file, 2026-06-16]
vapen-stack/weapon-module.step
54.0 x 74.0 x 11.2 mm
C_0805_2012Metric
C_1206_3216Metric
SOT_23 x 2
R_0805_2012Metric x 2
LED_WS2812B-Mini_PLCC4_3.5x3.5mm_P1.8mm x 2
C_1210_3225Metric
C_0402_1005Metric x 2
R_2512_6332Metric
Fuse_1206_3216Metric
D_SMB
QFN-16-1EP_3x3mm_P0.5mm_EP1.7x1.7mm
PinSocket_1x14_P254mm_Vertical
JST_S2B_XH_A
weapon-module PCB

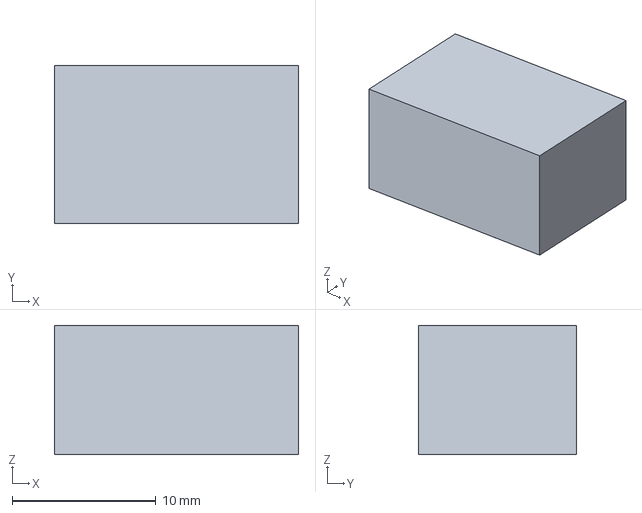
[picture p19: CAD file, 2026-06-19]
hardware/strilas-3d/AMASS_XT30PW-M_1x02_P2.50mm_Horizontal.step
17.0 x 11.0 x 9.00 mm

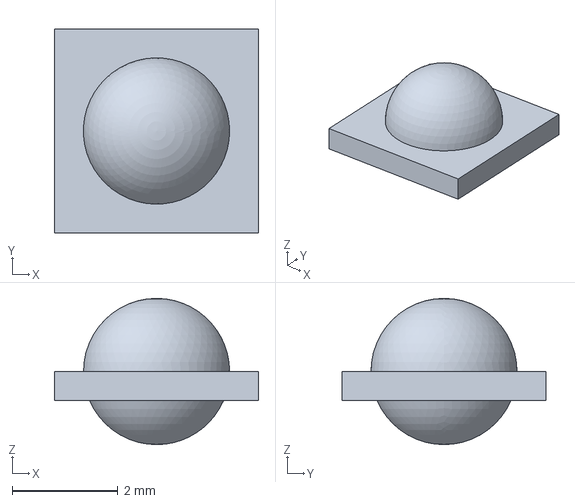
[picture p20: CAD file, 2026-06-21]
hardware/vsmy98545-3d.step
3.85 x 3.85 x 2.76 mm

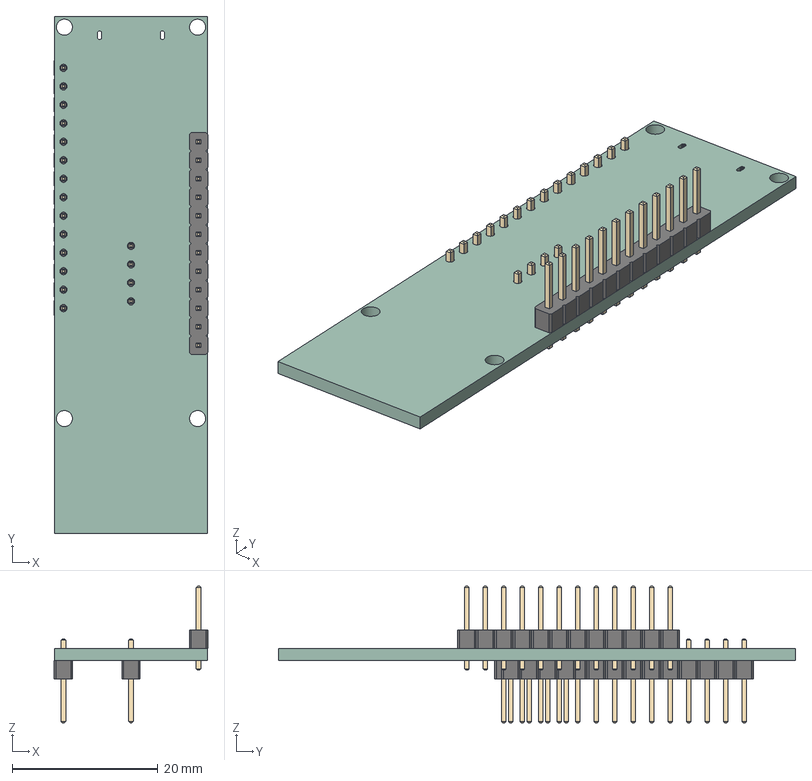
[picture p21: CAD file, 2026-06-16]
vapen-stack/p4-board-stack.step
21.1 x 71.0 x 18.8 mm
PinHeader_1x12_P254mm_Vertical
PinHeader_1x14_P254mm_Vertical
PinHeader_1x04_P254mm_Vertical
p4_stack PCB

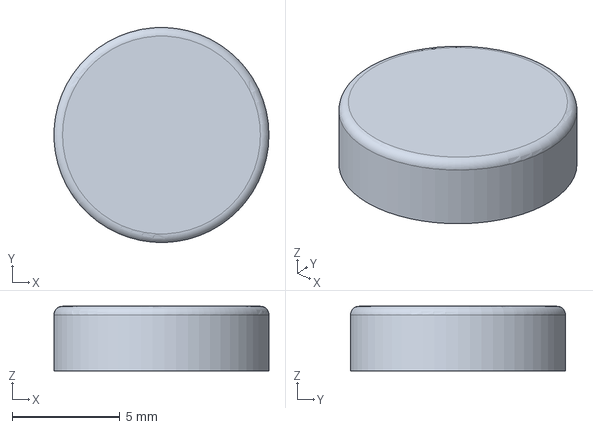
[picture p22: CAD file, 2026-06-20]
hardware/erm-coin-3d.step
10.00 x 10.00 x 3.00 mm

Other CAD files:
vapen-stack/firecontrol.step
hardware/firecontrol-stack.step
vapen-stack/firecontrol-stack.step
hardware/firecontrol.step
vapen-stack/p4-board.step
hardware/led-tab-3d.step
hardware/p4-board-stack.step

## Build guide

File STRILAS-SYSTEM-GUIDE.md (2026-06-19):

# STRILAS — Komplett systemguide

> **Ballistic Laser Tactical-Engagement Simulator.** Force-on-force trä­ning/spel där replika­vapen
> skjuter **kodat infrarött ljus** (inga projektiler), men med **simulerad ballistik** (kulfall +
> flygtid + lead) så att det blir **skicklighet, aldrig pek-och-skjut**. Träffar registreras av
> kropps-/hjälm­detektorer, posen löses optiskt av skyttens kamera, och allt loggas live.

Detta är **master-dokumentet** — den auktoritativa, kompletta referensen. Detaljanalyser ligger i
`vapen-stack/ritningar/` och länkas per avsnitt. Tillverknings­underlag i `vapen-stack/nextpcb/`.

> **Status (2026-06):** Alla 5 tillverkade kort routade rent (0 oanslutna / 0 clearance), system-
> simulering 28/28 PASS, order­paket klart. Se `vapen-stack/nextpcb/FORSTA-BATCH.md`.
> Äldre detaljdokument kan referera tidigare beslut (väst-nod "ESP32-C5", 3 TSOP/patch, 5+5 patchar);
> **gällande arkitektur är denna guide** (P4-WIFI6 överallt, 4-TSOP symmetrisk patch, rund hjälm).

---

## 1. Designfilosofi (varför systemet finns)

Vanlig laser-tag/MILES = pek-och-skjut: strålen träffar direkt, ingen ballistik. STRILAS bryter det:

- **Ljus faller inte → ballistik BERÄKNAS.** 940 nm-strålen går rakt, men firmware räknar kulfall
  och flygtid utifrån **avstånd R** och **vapenattityd**, och avgör i efterhand om "kulan" landat.
- **Kräver både hållover (drop) OCH lead (förhållning).** Spelaren måste själv sikta över och framför.
  Systemet auto-kompenserar **inget** → skicklighetsstyrt.
- **Ärlig adjudikering, inte trösklar.** Träff = den världsfasta, fall-korrigerade skottlinjen skär
  målets *verkliga* läge när kulan anländer (deferred hit). Inga gissningar.

Detaljer: [`ritningar/ballistik-analys.md`](vapen-stack/ritningar/ballistik-analys.md),
[`ritningar/rorligt-mal-analys.md`](vapen-stack/ritningar/rorligt-mal-analys.md).

---

## 2. Systemarkitektur — 3 noder, samma ESP

Allt kör **samma Waveshare ESP32-P4-WIFI6** (P4 SoC + onboard ESP32-C6 WiFi6/BLE) → en source, enkelt
underhåll, WiFi6-mesh genomgående (ESP-NOW/WiFi6). P4 självförsörjer via VSYS=VBAT (onboard MP1658-buck);
varje kort har dessutom en **carrier-buck (AP63203)** som ger 3,3 V till sensorer/last.

| Nod | Kort | Roll | Nyckelfunktioner |
|---|---|---|---|
| **Vapen** | optik + fire-control | "Sikte + domare" | OV9281-kamera (860 nm-pass) → PnP-pose; 940 nm-emitter (eye-safe CC); IMU; recoil; NFC-ammo; avtryck/laddhandtag |
| **Väst** | väst-mb + 10 patchar | Träff-RX torso 360° | 10 patch-DATA (skott-LOS); 20 konstellations-LED (pose); 10 zon-vibratorer (haptik) |
| **Hjälm** | hjälm-mb (rund Ø100) + 4 patchar | Huvud-RX + **RTK-position** + headset | 360° huvud-TSOP; konstellation; **RTK-puck (baksida): ZED-F9P el. alt Ø86** + IMU (cm-position); **ES8388-headset** (mik/högt/PTT) |

Mesh: vapnets P4 löser posen och adjudikerar; väst/hjälm-noderna rapporterar DATA-träffar, RTK-position
och driver haptik/ljud lokalt. Detaljer: [`ritningar/system-struktur.md`](vapen-stack/ritningar/system-struktur.md).

---

## 3. Hur ett skott går till (end-to-end)

> Flödesbild: [`vapen-stack/ritningar/skott-flode.png`](vapen-stack/ritningar/skott-flode.png).
> Konstellations-täckning (LED-riktning vs mottagar-vinkel): [`konstellation-tackning.md`](vapen-stack/ritningar/konstellation-tackning.md).

```
1. AVTRYCK → fire-control (edge A) signalerar P4. NFC-ammo > 0 + laddhandtag racked (make-ready).
2. EMITTER fyrar: 2× 940 nm OSLON i serie, aktiv konstantströms-sänka (OPA171+pass-FET+0R2 sense),
   ~1 A HW-tak (eye-safety), 56 kHz-gatad burst som bär skott-paket (skytte-ID, vapenprofil, dmg).
3. SKOTTLINJE LÅSES i världsram vid avtryck (riktning pipan pekar + ballistiskt fall). IMU håller
   linjen världsfast medan vapnet rör sig (recoil/svaj).
4. KAMERAN (860 nm-pass, global shutter, 120 fps) ser målets aktiva 860 nm-KONSTELLATION → frame-
   differencing → rena blobbar → PnP (≥4 LED i känt 3D-mönster) → mål-pose: avstånd R + bäring + orient.
5. BALLISTIK: R → kulfall (~14 cm @150 m) → hållpunkts-offset. Flygtid (~167 ms @150 m) → kameran
   spårar målet under hela flygtiden.
6. DEFERRED HIT: när kulan når R → träff OM den världsfasta fall-korrigerade linjen skär målets
   VERKLIGA läge då. Träffzon mappas på målets 3D-modell (anatomisk zon).
7. MÅLET: TSOP-patch (940 nm) ger LOS-gate/anti-fusk DATA-puls → väst/hjälm-nod → mesh. Vid
   ADJUDIKERAD träff fyras zon-VIBRATORN (haptik) + ljud/score. (Rå TSOP ≠ poäng; kameran avgör.)
```

---

## 4. Optik & våglängder (måste matcha)

| Funktion | Våglängd | Komponent (ams OSRAM, **samma leverantör**) | Mottagare |
|---|---|---|---|
| **Skott** (LOS/ID/anti-fusk) | **940 nm** | SFH 4725S OSLON Black (980 mW@1A), CC ~1 A, 56 kHz | TSOP4856 (56 kHz, ±45° lob) |
| **Konstellation** (pose) | **860 nm** | SFH 4715AS OSLON Black, Ie 780 mW/sr@1A | Kamera m. 860 nm bandpass |

> **Hjälm-konstellation:** OSLON på **LED-tab micro-PCB** (90°-vinklad right-angle fot) (`led-tab`) — NextPCB placerar OSLON:en,
> kund böjer benen radiellt ut mot horisonten (full effekt, syns i ögonhöjd @150 m). Se `konstellation-tackning.md`.
>
> **Sourcing-status:** 940 nm-emittern **SFH 4725S är utgående/EOL** (databl. 2023) men lagerförs ännu
> (last-time-buy) → OK för första batchen; verifiera aktuell 940 nm OSLON-ersättare inför produktion.
> 860 nm **SFH 4715AS = aktiv/tillgänglig**. **OSLON-emittrarna sitter under Carclo TIR-kollimatorlinser
> + hållare** som köps separat och monteras manuellt (sätter strålvinkeln; eye-safety ommäts med lins).

Kameran ser **860 nm** (konstellation) och **avvisar egna 940 nm-strålen** → ingen självbländning.
TSOP tar emot 940 nm-skottet. **Transparent IR-kupa** över korten: ser svart/mörkröd ut för ögat men
släpper nära-IR (T≈0,88), absorberar solglimt (bättre SNR). Specar: [`ritningar/fonster-spec.md`](vapen-stack/ritningar/fonster-spec.md).

---

## 5. Ballistik & räckvidd

- **Designräckvidd: 150 m.**
- **Mynningshastighet v₀ ≈ 900 m/s** (profil-beroende).
- **Kulfall @150 m:** `½·g·(R/v₀)² ≈ 14 cm` → hållpunkt **~0,9 mrad (~3 MOA)** över målet.
- **Flygtid @150 m:** `R/v₀ ≈ 167 ms` = **~20 frames @120 fps** (deferred-hit-fönstret).
- **Avstånds-okänslighet:** `d(fall)/dR ≈ 1,8 mm/m` → även ±0,9 m R-fel ger bara **±1,6 mm** hållpunktsfel (försumbart).

Hållpunkts-retikel sjunker med avståndet; spelaren lägger konstellationen på den. Bildmitten får peka
**över** målet — det är poängen. [`ritningar/ballistik-analys.md`](vapen-stack/ritningar/ballistik-analys.md).

---

## 6. Rörliga mål — lead (förhållning)

Lead-vinkel = **v_mål / v₀** (oberoende av avstånd). Litet → alltid inom kamerans ±6,85° FOV:

| Målfart | lead-vinkel | lead @150 m |
|---|---|---|
| 3 m/s | 0,19° | 0,50 m |
| 5 m/s | 0,32° | 0,83 m |
| 10 m/s | 0,64° | 1,67 m |
| 15 m/s | 0,95° | 2,50 m |

Sikta **där målet är** (ingen lead) → kulan anländer dit målet **var** → miss på korsande mål. Sikta
**framför** → träff. Mål som tvärbromsar efter avtryck hinner undan (realistiskt). [`rorligt-mal-analys.md`](vapen-stack/ritningar/rorligt-mal-analys.md).

---

## 7. Optik & algoritm (kamera = sikte)

- **Kamera:** Arducam OV9281 (1280×800, 3 µm px, **global shutter** → ingen rörelsesmet), USB till P4.
- **Lins:** 16 mm M12 low-distortion → **~13,7° HFOV**, **0,0107 °/px**, skala **1° = 2 618 mm @150 m**.
- **PnP (Perspective-n-Point)** på ≥4 icke-koplanära konstellations-LED → 6-DOF mål-pose (R + bäring +
  orientering) i ett svep. Robustare än 2-punkts-stadiametri.
- **Frame-differencing + 860 nm-bandpass + modulerade LED** → rena blobbar även i dagsljus; subpixel-
  centroidering (~0,1 px) → ~24 px konstellations-baslinje @150 m.
- **IMU re-ankrar attityden varje frame** (8,3 ms @120 fps) → låg inter-frame-drift.
- **Deferred adjudication:** skottlinje låst i världsram vid avtryck; träff bedöms när kulan når R.
- **Latens-budget** (sensor→beslut ~8–16 ms) måste kompenseras (annars lead-bias) — mjukvaru-jobb.

Algoritm-roller: konstellations-centroider = "beräkningspunkterna" (ger bäring + R). 940 nm = skott-ID/LOS
(ej geometri). Kamera = ser 860 nm, avvisar 940 nm. IMU = stel mot optiska axeln.

---

## 8. Precision (felbudget @150 m)

RSS av oberoende felkällor (ICM-42688-P + 120 fps + low-distortion-lins):

| Felkälla | 1σ @150 m |
|---|---|
| Centroid-brus (0,1 px) | 2,8 mm |
| Intrinsisk kalibrerings-rest | 3,9 mm |
| IMU mellan-frame-brygga (120 fps) | 1,2 mm |
| Avstånd→hållpunkt (±0,9 m) | 1,6 mm |
| **RSS (bäring/träffläge)** | **≈ 5,2 mm 1σ** |
| **Avstånd R (PnP)** | **±0,3–0,9 m** |

Sensorbruset (~5 mm) är **~27× mindre** än hållpunkten (140 mm) → systemet är **inte** begränsningen;
spelarens sikte är det. Svagheter: smalt FOV (mål ur bild vid recoil), dagsljus-SNR (omätt), latens.
[`ritningar/precision-iim42653.md`](vapen-stack/ritningar/precision-iim42653.md), [`precision-analys.md`](vapen-stack/ritningar/precision-analys.md).

---

## 9. Hitbox / zoner

Två zonsystem som gör olika saker:

**A) Kamera/PnP-zoner (fina, mjukvara) — i praktiken obegränsat.** P4 mappar träffpunkten på målets
3D-modell. Gräns = bäringsprecision:

| Avstånd | bäring 1σ | minsta säkra zon (~3σ) |
|---|---|---|
| 25 m | 0,9 mm | ~3 mm |
| 75 m | 2,6 mm | ~8 mm |
| 150 m | 5,2 mm | ~16 mm |

→ **8–16 anatomiska zoner** (huvud, vä/hö bröst, vä/hö mage, armar, ben) glasklart särskiljbara ända till 150 m.

**B) Fysiska TSOP-patch-zoner (LOS-gate + fallback).** Varje patch = 1 DATA-linje. Bekräftar att strålen
*nådde fram* (anti-fusk, ej genom vägg) + grov-zon om kameran tappar konstellationen. [`vest-zonschema.md`](vapen-stack/ritningar/vest-zonschema.md).

---

## 10. Patch-design (täcknings-nod)

Identisk patch på väst och hjälm — **rund Ø45 mm, 4-falds symmetrisk (4× M2-hål)**, lim/kardborre +
ev. rökfärgad polykarbonat-dom (Ø46,5 inner) som skydd över de böjda benen. **Kontakt = JST-PH 5-pol
SIDE-ENTRY (S-typ) på BAKSIDAN** → låg bygghöjd, kabel ut i kant, domen täcker fronten obehindrat.
Fronten = ren optik (4 identiska TSOP-kluster + 4 LED-tabbar i kardinalriktning + 2 fasta LED), driver/kraft i centrum:

- **4× TSOP4856** (ledade) i **diamant**, var och en böjd **~40° utåt** från kortets normal.
  Beräknat optimum: **99,5 % av framåt-hemisfären** täckt, **100 % inom 60° zenit**, ~2,3 mottagare
  ser ett frontalskott (redundans). Full symmetri → funkar i **valfri vridning** på kroppen.
- Varje TSOP: egen OR-diod (BAT54) + avkopplings-C → 4 identiska kluster; alla OR:as till **1 DATA-linje**.
- **Konstellation: 2 fasta 860 nm OSLON + 4 böjbara LED-tabbar = 6 LED**, kopplade i **3 seriepar-grenar**
  (2 LED + 10R 2512/gren); N-FET (AO3400, LED_EN) modulerar. ~0,2–0,28 A/gren → ~0,5–0,8 A/patch på VBAT.
- TSOP matas **3,3 V från moderkortet** (abs-max 6 V → tål ej 2S direkt); LED-konstellationen på **VBAT**.
- Baksida (mot kroppen): **ERM-vibrator** för lokal träff-känsla.
- Beräkning: [`ritningar/patch-sikte.md`](vapen-stack/ritningar/patch-sikte.md).

---

## 11. Haptik (väst)

- **ERM coin-motor bakom varje zon**, mot kroppen → lokal buzz där du träffas.
- Drivs av **2× TPIC6B595** power-shift-register (open-drain 150 mA/kanal, inbyggd flyback), styrt med
  3 GPIO (SER/SRCK/RCK) → 16 kanaler täcker 10 zoner. PWM = intensitet/mönster.
- **Fyras på ADJUDIKERAD träff** (kamera/spellogik bekräftar) ~tiotal ms efter skott = känns direkt —
  inte på rå TSOP (bred kon kan nudda flera patchar på en miss).
- Effekt: ERM ~80 mA @3 V, 200–400 ms/träff → försumbart medel. [`ritningar/vest-haptik.md`](vapen-stack/ritningar/vest-haptik.md).

---

## 12. RTK-positionering & IMU (hjälm)

- **RTK-puck monteras på hjälm-kortets BAKSIDA** (sky-sidan, antennen uppåt mot himlen); fronten med
  P4 + optik vänds mot hjälmskalet. Två puck-alternativ stöds (montera ENDERA):
  - **ZED-F9P-puck** (inbyggd antenn + **IST8310-kompass**) — 8-pol GH-kontakt (1,25 mm). Fästmönster 20,80×33,90 mm.
  - **Alt all-in-one UM980/F9P Ø86 mm, låg profil** (inbyggd antenn + IST8310) — 6-pol GH (VCC·RX·TX·SCL·SDA·GND).
    Fästmönster ~20,0×34,1 mm. Mönster-skillnaden ~0,8 mm → fästhålen satta till medel (±10,2×±17,0), passar båda.
  Båda GH-kontakterna (J1 8-pol, J12 6-pol) sitter på baksidan UNDER pucken (parallella UART/I²C/kraft-nät).
  **cm-noggrann** position, matas VBAT (3–9 V), UART + I²C till hjälm-P4. Pucken sitter UPPHÖJD på standoffs
  → puck-GH J1/J12 ligger inne på baksidan; kant-ringens kontakter (4 patch + headset) sitter i LUCKORNA
  mellan LED-tabbarna. **Ø100** är vald storlek (0/0): routbart minimum är Ø96 (+3V3 som kopparPLAN på In2,
  amp intill högtalaren), men Ø100 ger luft för SYMMETRISKA patch-kontakter (två motstående par 120/183/
  300/3°), 11°-pitch på headset-klustret fritt från tab/optik, och puck-JST + batteri utan trängsel. LED-
  tabbarna är fixa var 60° (28/88/148/208/268/328°); alla kant-kontakter placeras i gluggarna däremellan,
  fria från optiken (41/131/221/311°). (Ø96 fungerar men packar kant-ringen för tätt för ren symmetri.)
- **ICM-42688-P IMU** (I²C, delar F9P-bussen + INT) → **GNSS/INS-fusion**: överbryggar multipath/skugga,
  ger lokal huvud-attityd, förbättrar RTK-fix. Samma IMU som vapnet/fire-control.
- Hjälm-noden skickar cm-position + huvud-pose i meshen → live-spårning + after-action.
- Kompletterar (ute) den optiska posen; ger absolut världsposition som vapnets relativa pose saknar.

IMU används även i vapnet för **recoil→sikte-loopen** (mynningsklättring matas in i nästa skotts bana;
okontrollerade serier vandrar av målet). **ICM-42688-P** (vald, i lager): ±2000 dps, RNSD **0,0028 °/s/√Hz**
(≈2× lägre gyro-brus än ICM-42688-P → stabilare attityd mellan kameraramar), låg ZRO-drift. Pin-kompatibel
drop-in mot ICM-42688-P på samma LGA-14-footprint (±4000 dps/±32 g/IND behövs ej för axelburet bruk).

---

## 13. Korten (5 tillverkade PCB)

| Kort | Storlek | Lager | Innehåll | Routning |
|---|---|---|---|---|
| **Optik/vapen** | 54×74 mm | 4 | P4-stack, OV9281-USB, 940 nm-emitter + CC-driver, IMU, lins-hål Ø16 | 0/0/0 |
| **Fire-control** | 71×21 mm | 2 | Stackas på P4 edge A; avtryck/laddhandtag/mag-switchar, recoil-ctrl, NFC, 2× extra IMU | 0/0/0 |
| **Väst-patch** | **rund Ø45 mm** | 2 | 4 TSOP diamant + 6 LED (2 fasta + 4 tab) i 3 grenar + FET + JST-PH 5-pol side-entry (baksida) | 0/0/0 |
| **Hjälm-mb** | **rund Ø100 mm** | 4 | Front: P4 + optik-ring (4 TSOP + 6 LED-tab jämnt) + ES8388-headset-codec + batteri. Bak: RTK-puck (Ø86, centrum, upphöjd) + puck-GH inne; kant-kontakter i tab-gluggarna (4 patch SYMMETRISKT + mik/högt/PTT-kluster + batteri) | 0/0/0 |
| **Väst-mb** | 100×60 mm | 4 | P4, 10 zon-kontakter JST-PH 6-pol side-entry (patch+vibrator), 2× TPIC6B595, buck, **XT30-batteri** (In2=VBAT-plan) | 0/0/0 |

**Strömplan:** alla 4-lagerskort In1=GND, F/B=GND-fyll. In2 = **VBAT** (väst-mb + hjälm-mb + optik —
bär LED-konstellationsström + patchar). P4-pinout **byte-identisk** över alla kort, verifierad mot Waveshares
dok (I²C SCL=GPIO8/SDA=GPIO7). Carrier-buck matar 3,3 V-last; P4 självförsörjer via VSYS=VBAT.

---

## 14. Kraft & batteritid (uppskattning — bekräfta på bänk)

2S LiPo per nod. Buck-verkningsgrad ~90 %. Recoil-aktuatorn (~20 A-toppar) matas från **separat
magasins-batteri**, ej nodbatteriet. **Konstellations-LED:erna är den dominerande lasten** och därmed
den primära batteritids-drivaren — deras **medel-duty** är designparametern att optimera (synka blink/
ID till lågt duty mot kamerans exponering).

Grov medeleffekt per nod (aktivt spel):

| Last | Vapen | Väst | Hjälm |
|---|---|---|---|
| P4 + WiFi6 (kamera/PnP tyngst på vapen) | ~2,5 W | ~1,5 W | ~1,8 W |
| Sensorer (IMU/F9P/kamera) | ~0,2 W | — | ~0,5 W (F9P) |
| Emitter 940 nm (pulsad, skott-takt) | ~0,1–0,3 W | — | — |
| Konstellation 860 nm (se duty) | — | **se nedan** | ~0,3 W (2 LED) |
| Haptik/ljud (pulsad) | — | ~0,1 W | ~0,3 W |

**Konstellations-LED, väst (10 patchar × 6 LED = 60 LED i 30 seriepar-grenar, drivs på VBAT):**

Topp (alla patchar blinkar synkront) ≈ **0,2–0,28 A/gren × 30 = 5–8 A** på VBAT (8,3 A @ fulladdat 8,4 V).
LED:erna går **direkt på batteriet via In2=VBAT-plan** (INTE bucken) → batteri + **XT30-kontakt (≥15 A)** +
VBAT-plan bär toppen med marginal. Medelströmmen sätts av blink-duty:

| Medel-duty | I_LED medel | Effekt | + P4 ⇒ nod-medel | Drifttid 2S 2200 mAh (16,3 Wh) |
|---|---|---|---|---|
| 2 % (synkad/optimerad) | ~0,15 A | ~1,1 W | ~2,8 W | **~5,8 h** |
| 5 % | ~0,35 A | ~2,7 W | ~4,5 W | **~3,6 h** |
| 10 % | ~0,7 A | ~5,3 W | ~7 W | **~2,3 h** |

→ **Rekommendation:** håll konstellations-duty lågt (≤5 %) via blink-synk → 3–6 h speltid på en 2S
2200 mAh. (Vill man ändå ha hög samtidig ljusstyrka klarar VBAT-planet + XT30 toppen; det är
**batteritiden**, inte kopparen/kontakten, som då blir gränsen.) Vapen-noden (ingen konstellation)
≈ 0,4 A → **~5 h**; hjälm ≈ 0,5–0,7 A → **~3–4 h**. *(Estimat — mät faktisk P4-vision-effekt + vald
LED-duty på bänk; ladd-dock balanserar alla pack.)*

---

## 15. Eye-safety (säkerhet före allt)

- 940 nm är **osynligt** → farligast nära mynningen. **Strömtaket sätts i HÅRDVARA** (CC-sänka:
  I = Vref/Rsense ≈ 1 A, op-amp + sense-resistor), inte bara firmware. Skalning till högre ström kräver
  avsiktligt Rsense-byte **+ IEC 60825-1-ommätning**. Mål: **Klass 1 (eye-safe)**; vid tvekan, använd
  divergerad IR-LED (det vi gör — OSLON-emitter, ej kollimerad laserdiod).
- **LiPo-laddning** (dock) = projektets största brandrisk: per-cell-balansering, riktig BMS, termik, brandsäker plats.
- **Recoil-skena** ~20 A: kontakter >25 A, gör/bryt **kallt** (skenan av vid mag-byte, make-ready-statemaskin).
- Skyddsglasögon för alla; definierade spelgränser; "weapons safe"-procedur. (Se root-`README.md`.)

---

## 16. Comms / mesh

Alla noder = ESP32-P4-WIFI6 (P4 + C6) → **WiFi6/ESP-NOW-mesh**, gemensam tidsstämpling. Vapnets P4
adjudikerar; väst/hjälm rapporterar DATA-träffar + RTK-position; allt loggas för live-spårning + AAR.

---

## 17. Tillverkning & beställning

Order­paket: **`vapen-stack/nextpcb/`** — per kort `<kort>-gerbers.zip` + `-bom.xls` + `-centroid.csv/.xls`.
3D: `hardware/<kort>.step`. Beredskaps­rapport: **`nextpcb/FORSTA-BATCH.md`**.

- **NextPCB monterar endast SMT.** P4-socklar samt alla JST-PH-kontakter (patch/zon/headset, nu **side-entry**)
  + batteri-JST/XT30 **kund-löds** — markerade **DNP i BOM** (NextPCB monterar EJ) men kvar som beställnings-
  rader, ute ur centroid. ZED-F9P GH (SMD) monteras av NextPCB. FC:s 2 extra IMU = **prototyp-DNP** (breakout först).
- **OSLON-emittrar/LED (ams OSRAM) sourcas + placeras nu av NextPCB** (ej längre consignment "C" — verifiera
  lager/EOL inför produktion, t.ex. 940 nm SFH4725AS bin13). Matcha kamerans 860/940 nm IR-pass.
- **Köps separat:** 3× ESP32-P4-WIFI6, RTK-puck (ZED-F9P 8-pol GH **eller** alt all-in-one UM980/F9P Ø86 6-pol GH),
  OV9281 + IR-pass-filter, headset (mik/högtalare/PTT), 10× ERM-vibrator, 2S-batterier, IR-kupa (mörk-IR-akryl).
- **Optik-linser + hållare (köps separat, MONTERAS MANUELLT):** Carclo TIR-kollimatorlins för OSLON Black
  (Carclo 10003-serien — välj spridning för räckvidd) + Carclo-lenshållare per emitter, klistras/snäpps
  över emittrarna efter SMT (fästben finns på optikkortet). NextPCB SMT-placerar OSLON-emittrarna med
  precision; linsen monteras sen manuellt ovanpå.
- FR-4 1,6 mm, HASL/ENIG. Alla MPN ifyllda (passiva = representativa, verifiera mot NextPCB-bibliotek).

---

## 18. Verifiering (maskinkontrollerat)

- **Per kort** (`hardware/verify_board.py`): footprints matchar netlist, alla net-noder har pad,
  **0 oanslutna + 0 clearance@0,2 mm** på alla 5 kort. 0 courtyard-krockar; rund hjälm radiellt OK.
- **P4-pinout:** byte-identisk över alla möte-kort; I²C bekräftad mot Waveshares dok.
- **System-simulering** (`hardware/sim_system.py`): korten "uppkopplade" via kabel-bryggor →
  **28/28 PASS** (skott-RX, konstellation, kraft, I²C, GNSS-UART, vibrator, ljud, vapen-CC-emitter,
  IC-kraftintegritet) — allt flödar end-to-end.

**Bänk-bekräftas (ej fångbart i layout):** dagsljus-SNR @150 m (störst), kontinuerlig spårning +
latenskompensation i 167 ms, recoil-hantering, TSOP-räckvidd @150 m, buck-3,3 V, IMU LGA-pad mot ICM-42688-P.

---

## 19. Repo-karta (för framtida referens / minne)

```
hardware/
  *_netlist.py / receiver_netlists.py   — SKiDL kretsdefinitioner → .net
  make_p4_board.py                      — KANONISK P4-WIFI6 mekanik/pinout (källa)
  receiver_place.py                     — placering (vest_pos/helmet_mb_pos/vest_mb_pos) + outline
  route_*.py                            — DSN→freerouting(loop, timeout-skydd)→ses_apply→kopparplan→DRC→gerber/STEP
  dsn_power_class.py / ses_apply.py     — power-net-breddning / SES-import
  verify_board.py                       — pad/footprint/anslutnings-verifiering
  sim_system.py                         — system-signalflödes-simulering (kabel-bryggor)
  strilas.pretty/                       — custom footprints (OSLON, InvenSense LGA-14, Vishay)
  <kort>.kicad_pcb / .net / .step / -gerbers.zip
vapen-stack/
  gen_nextpcb.py                        — BOM + centroid (MPN-dict, grupperar på värde+footprint)
  ritningar/*.md + *.png                — alla analyser (ballistik, precision, SNR, zoner, haptik, sikte…)
  nextpcb/                              — ORDERPAKET: gerbers/bom/centroid per kort + FORSTA-BATCH.md
README.md                               — högnivå-intro + säkerhet
STRILAS-SYSTEM-GUIDE.md                 — DETTA dokument (master-referens)
```

**Verktygskedja:** KiCad 7 (kicad-cli 7.0.11) + pcbnew Python API · SKiDL (netlistor) · freerouting v1.9.0
(java, körs headless via xvfb-run; analytics av + spår-rensning före DSN-export = undvik dialog-hängning).

**Centrala designval (låsta):** P4-WIFI6 överallt · 940 nm skott / 860 nm konstellation (ams OSRAM OSLON) ·
kamera = sikte (PnP, ej stadiametri) · 16 mm-lins · deferred hit · eye-safety i HW · 4-TSOP-diamant 40° patch ·
rund hjälm (Ø100) med RTK-puck på baksidan · haptik på adjudikerad träff.

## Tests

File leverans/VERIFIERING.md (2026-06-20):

# STRILAS — FULL KORT-VERIFIERING (alla 6 kort)

Föranledd av XT30-polaritetsbuggen på vest-mb. Verktyg: `hardware/audit_board.py` (ETT kort/process).
Kör om när som helst: `python3 hardware/audit_board.py <kort>`.

## Sammanfattning

| Kort | Lager | DRC clr/uncon | PCB↔.net | Kontakt-pol | Diod/LED-pol | P4-pinout |
|---|---|---|---|---|---|---|
| weapon-module | 4 | **0 / 0** ✓ | 0 mismatch ✓ | — | ✓ | VSYS→VBAT, 3V3, GND ✓ |
| firecontrol | 2 | **0 / 0** ✓ | 0 mismatch ✓ | — | — | GND ✓, inga konflikter |
| helmet-mb | 4 | **0 / 0** ✓ | 0 mismatch ✓ | — | ✓ | VSYS→VBAT, GND ✓ |
| vest-mb | 4 | **0 / 0** ✓ | 0 mismatch ✓ | **XT30 ✓ (fixad)** | — | VSYS→VBAT, GND ✓ |
| vest-patch | 2 | **0 / 0** ✓ | 0 mismatch ✓ | — | ✓ | (ej P4-kort) |
| led-tab | 2 | **0 / 0** ✓ | — | — | — | (mikro-PCB) |

**Resultat: alla kort rena.** Den enda funna felet (XT30 omvänd polaritet på vest-mb) är åtgärdat
och omverifierat. Inga ytterligare fel.

## Vad som verifierades (per kort)

1. **DRC** — clearance@0.2 mm + unconnected (samma kontroll som route-skripten). Alla 0/0.
2. **PCB↔.net-konsistens** — varje pad-nät i `.kicad_pcb` jämförs mot `.net`. **0 mismatch på alla
   kort** → PCB och netlista är överens (just den klass av bugg där de glider isär). Detta är den
   starkaste garanten mot "tyst" felkoppling.
3. **Kontakt-polaritet** — inneboende-polariserade (keyade) kontakter mot footprint-silk:
   - **vest-mb J13 XT30PW-M**: pin1=GND(−), pin2=VBAT(+) ✓ — matchar footprintens silk (pin1=−,
     pin2=+). *(Var pin1=VBAT/pin2=GND → batteri bakvänt; fixat i `vest_mb_netlist.py` + omroutat.)*
   - JST-XH/PH/GH är **ej** inneboende-polariserade (symmetrisk husning, polaritet via kabel) → ingen
     XT30-liknande risk. XH-batterikontakter ändå konsistens-kollade: weapon J2 + helmet J10 båda
     **pin1=VBAT, pin2=GND** → samma batterikabel funkar på båda.
4. **Diod/LED/emitter-polaritet** — rätt anod/katod per footprint (källa: SKiDL-part-templates +
   `make_footprints.py` land E062.3010.91-06):
   - **IR-emitter SFH4725S/4715AS** (pad1=anod): anod→VBAT högsida, katod→sänka. Serie-sträng
     VBAT→emitter→emitter→LED_CATH→CC-sänka→GND ✓
   - **LED_Tab konstellation** (pad1=anod): VBAT→10R→anod→LED→LED→katod→N-FET→GND ✓
   - **BAT54 diod-OR** (D_SOD-123, pad1=katod): aktiv-låg OR, DATA-pullup→3V3; TSOP drar katod låg
     → diod leder → DATA låg ✓
   - **TVS SMBJ12A** (D_SMB, pad1=katod): katod→VBAT, anod→GND, unidirektionell matningsklamp ✓
5. **P4-pinout** (mot `p4_pinmap.py` + ESP32-P4-databladsregler):
   - Kraftstift rätt: **VSYS→VBAT, 3V3→+3V3, GND→GND** på alla P4-kort.
   - **Inga GPIO-konflikter** (samma kant-stift med >1 nät) på något kort.
   - **Inga ogiltiga GPIO-nummer** (alla inom GPIO0–54).
   - **Inga strapping-pinnar** (34–38) belastade.
   - INFO: USB-Serial-JTAG-pinnar (GPIO24/25) används som vanlig GPIO — firecontrol (MODE_A/B),
     helmet (I²S_DIN/AMP_SD). Medvetet val → man tappar USB-JTAG-debug men kan flasha via OTG-USB/UART.
     Inget fel, men noterat.

## Not
`audit_board.py` är nu det stående verifierings-verktyget. Kör det efter VARJE board-ändring
(placering/routning/netlist) som komplement till route-skriptens egna DRC-grind.

---

## TILLÄGG (v5): ingångsskydd · batterimätning · testpunkter · fiducials

Efter funktionsgenomgång tillkom (alla kort omverifierade, DRC 0/0):

| Kort | Omvändpol-skydd | Surge (TVS) | Batteri-sense | Testpunkter | Fiducials |
|---|---|---|---|---|---|
| weapon-module (optik) | ✓ (PTC+P-FET gate→GND, fanns) | ✓ (fanns) | **✓ ny** → J1[6]/GPIO21 | — (kontakter/IMU-header) | **✓ 3 nya** |
| vest-mb | **✓ ny** (P-FET gate→GND) | **✓ ny** | **✓ ny** → J11[6]/GPIO20 | **✓ 4 nya** | **✓ 3 nya** |
| helmet-mb | — (keyad JST-XH, se nedan) | **✓ ny** | **✓ ny** → J8[7]/GPIO21 | — (patch/F9P/ljud-kontakter) | **✓ 3 nya** |
| firecontrol | — (matas via 3V3-tapp, ej batteri) | — | — | — (JST-headers/nät) | **✓ 3 nya** |
| vest-patch | — | — | — | — | **✓ 3 nya** |
| led-tab | — | — | — | — | — (mikro 2-pad-PCB) |

### Kraftarkitektur-beslut (omvändpolaritets-skydd + PÅ/AV)
- **En enda P-FET kan INTE vara både omvändpol-skydd OCH gate-styrd strömbrytare** — kraven är
  motsatta (skydd kräver gate→GND så vänt batteri stänger FETen; gate-brytare kräver gate→batteri).
  Tidigt "FET-som-även-strömbrytare"-förslag var elektriskt felaktigt (kroppsdiod ledde vid AV +
  vänt batteri drog gate negativ → FET PÅ) och förkastades.
- **Vald lösning:** P-FET enbart som omvändpol-skydd (gate→GND, alltid på — samma beprövade krets
  som vapnet). **PÅ/AV = seriebrytare i BATTERIKABELN** (klarar full ström; inget litet
  kontaktdon på kortet).
- **vest-mb (XT30, ej keyad → kan vändas):** full omvändpol-FET (Q1 AOD4185A) + TVS.
- **helmet-mb (keyad JST-XH → omvänd isättning fysiskt omöjlig):** ingen omvändpol-FET (skulle
  kräva splits i den verifierade VBAT-kraftvägen); TVS räcker som ingångsskydd.
- **weapon (optik):** hade redan PTC+P-FET+TVS; ingen serie-last-switch tillagd (skulle äta
  IR-drivarens eye-safety-spänningsmarginal ~6,9 V).

### Batterimätning
100k/47k-delare (8,4 V → 2,69 V) + 100nF-filter → ledig ADC1-GPIO (GPIO20/21 via P4-kant).
Firmware läser cellspänning → lågbatterivarning.

### Routnings-metod för tilläggen
Optik + helmet routades **inkrementellt** (`hardware/incr_route.py`): BEVARAR all befintlig
verifierad koppar och drar bara de nya anslutningarna deterministiskt (via→plan, cluster-medvetna
spår) — ingen freeroute-omroutning som nollställer layouten. vest-mb omplacerades + freeroutades
rent (seed 1). Fiducials läggs efter routning (`hardware/add_fiducials.py`, kopparplan omfylls).

---

## TILLÄGG (v6): KOMPLETT ingångsskydd på ALLA batterikort (full paritet, best practice)

Efter krav på "bygg för perfektion" har alla tre batterikort nu **identisk** ingångsskyddskedja:

| Kort | PTC-säkring | Omvändpol-FET (gate→GND) | TVS | Batteri-sense | DRC |
|---|---|---|---|---|---|
| weapon-module (optik) | F1 (MF-MSMF300/16, 3A) | Q1 (AO3401) | D1 (SMBJ12A) | →GPIO21 | 0/0 (308 spår) |
| vest-mb | F1 (MF-MSMF300/16, 3A) | Q1 (AOD4185A, DPAK) | D1 (SMBJ12A) | →GPIO20 | 0/0 (595 spår) |
| helmet-mb | F1 (MF-MSMF300/16, 3A) | Q2 (AO3401) | D11 (SMBJ12A) | →GPIO21 | 0/0 (1264 spår) |

**Kedja (alla):** `BATT+ → PTC-säkring (överström/kortslutning) → omvändpol-P-FET (gate→GND,
alltid på; vänt batteri → Vgs=0 → AV + kroppsdiod spärrar) → VBAT-rail med TVS-clamp + bulk`.
PÅ/AV = seriebrytare i batterikabeln (full ström, inget litet kontaktdon på kortet).

### Spänningsreglering 2S (7,4–8,4 V) → 3,3 V
- **P4-modulens onboard-buck MP1658** (3A, **16 V**-tålig; bekräftat mot Waveshares schema) tar
  VSYS=VBAT → P4:ans 3,3 V. Alla P4-kort matar P4 via VSYS=VBAT (8,4 V « 16 V → säker marginal).
- **Carrier-buck AP63203** (vest-mb + helmet-mb): VBAT → 3,3 V @2A för kort-laster (FB 31,6k/10k →
  3,328 V). Optik + firecontrol tar 3,3 V från P4:ans 3V3-utgång (ingen egen buck).
- Batteri-sense: 100k/47k + 100nF → ledig ADC1-GPIO (8,4 V→2,69 V, < 3,3 V-ref ✓).

### Routnings-metod (inga genvägar, bevarad verifierad layout)
Skydden lades till **inkrementellt** (`hardware/incr_route.py`) som BEVARAR all befintlig
verifierad koppar (inkl. ES8388-codecens känsliga QFN-28-fanout på hjälmen) och drar bara de nya
anslutningarna deterministiskt. För hjälmens långa kraftbanor genom trängseln byggdes en
**rutnäts-maze-router** (BFS, 2 lager + via-säkra lager-byten) + `connect_islands` (garanterar att
VBAT förblir ETT sammanhängande nät efter in-splitsningen). Ingen freeroute-omroutning som
nollställer verifierade kort. Alla kort omverifierade: DRC 0/0, PCB↔.net 0, polariteter OK.

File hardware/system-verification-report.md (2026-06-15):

# STRILAS — Fysik-verifiering @ 150 m (rapport)

Numerisk end-to-end-verifiering av hela kedjan med **exakta komponenter och datablad-
värden**, inga genvägar. Körs av [`system_physics_verification.py`](system_physics_verification.py)
(Monte Carlo + radiometri + länkbudget + ballistik). Konstellation på kroppsfigur **150 m** bort.

## Antaganden (explicita)

Kamera **Arducam B0332 — OV9281 mono global shutter, USB-UVC** (px 3,0 µm, 1280×800,
QE@860≈0,25, FW 8000 e⁻, läsbrus 3 e⁻) · **16 mm M12-lins**/F2 (13,7° H — se nedan) ·
850/860 nm IR-pass-filter (τ 0,7) ·
konstellation 5× 860 nm @ 0,30 W/sr i kroppsgeometri · sol 0,9 W/m²/nm, scen ρ 0,3 ·
ICM-45686 gyro 3,8 m°/s/√Hz · skott **2× Vishay VSMA1094750X02 (940 nm)** + TIR-kollimator
(räknat konservativt 1,08 W/A; verkligt ≈1,68) · TSOP-tröskel 0,35 mW/m² ×30 sol ÷4 bandpass ·
5.56 v0 880 m/s.

## Resultat

| # | Steg | Utfall | Nyckeltal |
|---|---|---|---|
| 1 | Framing / FOV | ✅ | konstellation 0,12°×0,26° i FOV; vertikal baslinje **24 px** |
| 2 | Kamera-detektion (dagsljus) | ✅ | **SNR ≫** (mättar redan @30 µs → kör ~10 µs exp; 8 mm-apertur) |
| 3 | Bäringsprecision (MC) | ✅ | **σ = 0,0007°** ≪ krav 0,076° (huvud) / 0,191° (torso) |
| 4 | PnP-range | ✅ | **σ = 0,76 m** (0,50 %) @ 150 m |
| 5 | IMU inter-frame | ✅ | drift **~0,0005°** @ 60 fps → **1 IMU räcker** (array = ren reserv) |
| 6 | IR-skott → TSOP @ 150 m | ✅* | **VALT: medium TIR @ ~2 A → 153 m** (kompakt 42×62-kort) |
| 7 | Ögonsäkerhet | ⚠️ mätpunkt | pt-källa 18× över; **extended-source täcker** → måste mätas |
| 8 | Ballistik | ✅ | flygtid 188 ms, drop **16 cm**, lead (3 m/s) 56 cm — modelleras |
| 9 | End-to-end träff (MC) | ✅ | **100 % torso**, sidled-RMS **0,2 cm** @ 150 m |

## ⚠️ Linsval: 16 mm krävs för 150 m (inte 6 mm) — brännvidds-svep

Fysiken avslöjar en hård gräns: **OV9281 är 1 MP (1280×800).** Konstellationens upplösning
i bilden sätts av brännvidden:

| Lins | FOV | vert. baslinje @150 m | närmaste LED-par | scen-bredd @150 m | omdöme |
|---|---|---|---|---|---|
| 6 mm | 35,5° | 9 px | 5,5 px | 96 m | **för få px** (LED smälter ihop) |
| 8 mm | 27,0° | 12 px | 7,2 px | 72 m | för få px |
| 12 mm | 18,2° | 18 px | 10,8 px | 48 m | OK (knapp marginal) |
| **16 mm** | **13,7°** | **24 px** | **14,3 px** | **36 m** | **ROBUST ✅ (vald)** |
| 25 mm | 8,8° | 38 px | 22 px | 23 m | robust men smal FOV |

Med 6 mm hamnar LED:erna 2–4 px isär och **smälter ihop till en blob** → blob-detektionen
hittar 1 i st.f. 5 och range-baslinjen kollapsar (informationsbrist, inte mjukvarubugg).
**Vald: 16 mm** → 14 px LED-separation + 24 px baslinje = ren detektion och robust PnP med
marginal, och 36 m scenbredd @150 m räcker gott för att hitta/följa mål. (PCB:t påverkas inte —
kameran är mekanisk/USB bakom Ø16-hålet, oberoende av brännvidd.)

## Tolkning

**Precisionskedjan håller med stor marginal (16 mm-linsen).** Sensorn (**Arducam B0332,
OV9281 mono global shutter, USB-UVC**) ser konstellationen vid 150 m i dagsljus med så hög SNR
att den **mättar redan vid 30 µs** → man kör ~10 µs exponering; mono utan Bayer + 3 µm-pixlar +
8 mm-apertur (16 mm/F2) ger gott om signal, och global shutter eliminerar pan-smet direkt.
Bäringen blir ~**0,0007°**, ~110× bättre än vad som krävs för att upplösa ett huvud (0,076°).
Ballistiken (drop/lead) modelleras exakt, och Monte Carlo ger **100 % torso-träff** med ~0,2 cm
sidled-RMS. IMU-driften mellan bildrutor är försumbar → bekräftar att **1 IMU räcker**.

**Emitter/optik-val: 2× Vishay VSMA1094750X02 (940 nm) + medium TIR-kollimator (≤±7,5°),
~2 A pulsat, kompakt 42×62-kort.** Viktig insikt: **ögonexponeringen sätts av räckviddskravet,
inte av linsen.** För 150 m krävs ~Ie 59 W/sr oavsett lins/ström-kombo; medium @ 2 A ger
Ie ≈ 61 → **nära minsta möjliga exponering**. (Narrow @ 1 A ger Ie 72 = mer marginal men
*högre* exponering.) Den valda Vishay-emittern är 940 nm (TSOP-topp + kamerans 860 nm-bandpass
avvisar egen stråle → ingen självbländning) och tål 1,5 A DC / 5 A pulsat → 2 A pulsat ligger
väl inom rating.

**Enda kvarvarande villkoret:** **ögonsäkerhet** — 18× över *punktkälle*-MPE, men **extended-
source-relaxationen (~67×) täcker** → **måste mätas** (skenbar källa/AE per IEC 60825-1).

## Slutsats

Systemet är **fysikaliskt sunt @ 150 m**. Allt som rör *precision* (det som gör det till mer
än laser tag) verifieras med stor marginal med de exakta, låsta komponenterna. Det enda som
inte kan *avgöras* i simulering är **ögonsäkerheten** — den kräver en bänkmätning (utpekad
mätpunkt). Driftpunkt (vald): **OV9281 + 16 mm-lins + ~10 µs exp; 2× Vishay 940 nm + medium TIR + ~2 A**,
kompakt 42×62-kort.

> Detta är en simulering med trogna modeller — inte ett substitut för bänkmätning av AE,
> dagsljus-SNR och räckvidd. Men varje länk är räknad ur fysik/datablad, inte antagen.

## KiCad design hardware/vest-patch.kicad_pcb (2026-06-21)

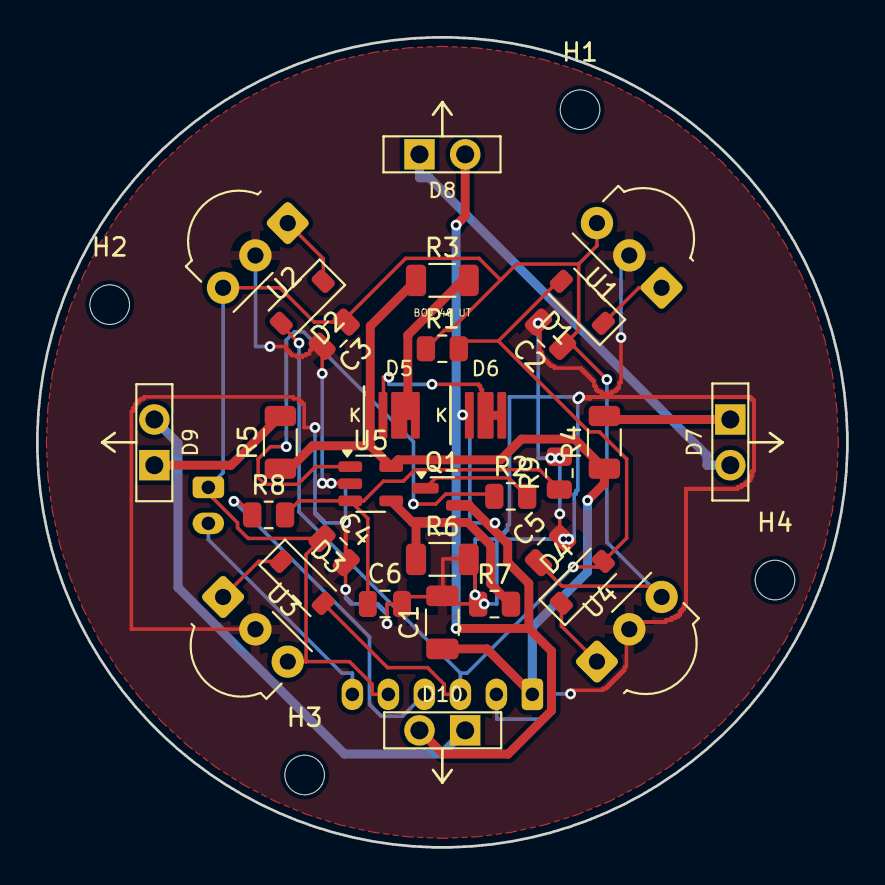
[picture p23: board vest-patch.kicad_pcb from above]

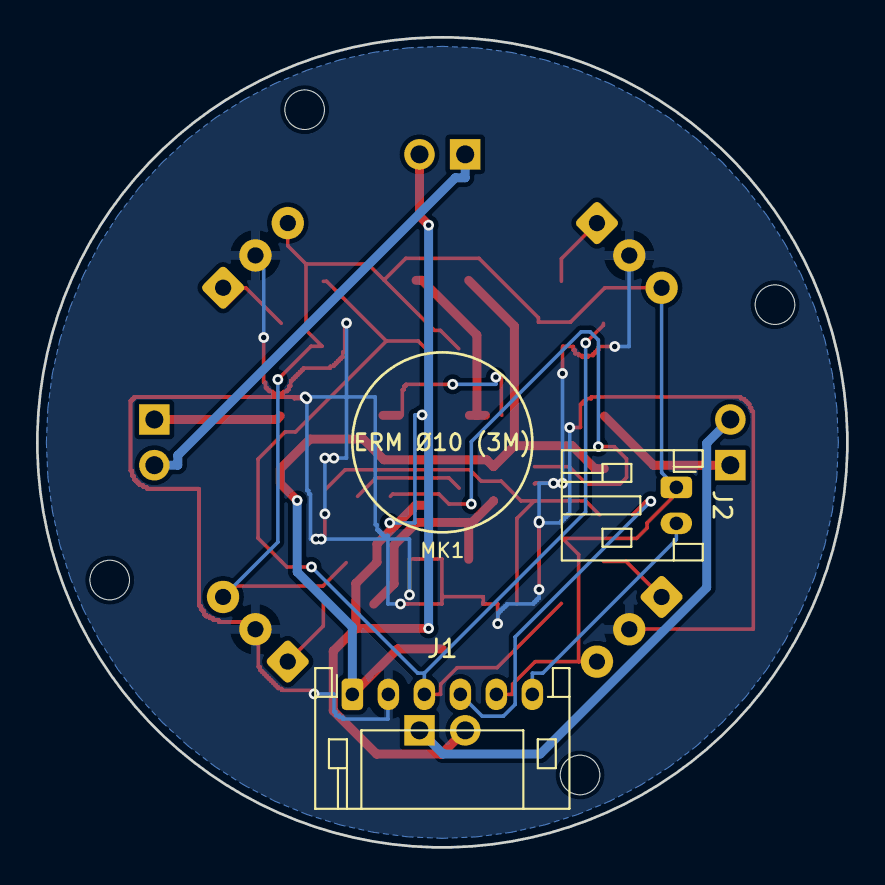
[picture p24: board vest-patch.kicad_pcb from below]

Board: 2 copper layers, 45.0 x 45.0 mm, 38 parts (3 on the bottom side), 21 nets.

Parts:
C1: C_1206_3216Metric
C2, C3, C4, C5, C6: C_0805_2012Metric
D1, D2, D3, D4: D_SOD-123
D5, D6: L1I0_IR
D7, D8, D9, D10: LED_Tab
H1, H2, H3, H4: MountingHole_2.2mm_M2
J1: JST_PH_S6B-PH-K_1x06_P2.00mm_Horizontal
J2: JST_PH_S2B-PH-K_1x02_P2.00mm_Horizontal
MK1: ERM_Coin_Keepout_10mm
Q1: SOT-23
R1, R2, R7, R8, R9: R_0805_2012Metric
R3, R4, R5, R6: R_1206_3216Metric
U1, U2, U3, U4: Vishay_MOLD-3Pin
U5: SOT-23-5

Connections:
+3V3: C2.1, C3.1, C4.1, C5.1, J1.5, J2.1, R1.1, U1.3, U2.3, U3.3, U4.3
DATA: D1.2, D2.2, D3.2, D4.2, J1.3, R1.2
GND: C1.2, C2.2, C3.2, C4.2, C5.2, C6.2, J1.2, R6.2, R7.1, R9.2, U1.2, U2.2, U3.2, U4.2, U5.2
IDRV_REF: C6.1, R8.2, R9.1, U5.3
IDRV_SENSE: Q1.2, R6.1, R7.2, U5.4
LED_A1: D5.1, R3.2
LED_A2: D7.1, R4.2
LED_A3: D9.1, R5.2
LED_CATH: D6.2, D8.2, D10.2, Q1.3
LED_EN: J1.4, R8.1
LED_GATE: Q1.1, R2.2
LED_M1: D5.2, D6.1
LED_M2: D7.2, D8.1
LED_M3: D9.2, D10.1
unnamed: R2.1, U5.1
OUT1: D1.1, U1.1
OUT2: D2.1, U2.1
OUT3: D3.1, U3.1
OUT4: D4.1, U4.1
VBAT: C1.1, J1.1, R3.1, R4.1, R5.1, U5.5
VIB: J1.6, J2.2

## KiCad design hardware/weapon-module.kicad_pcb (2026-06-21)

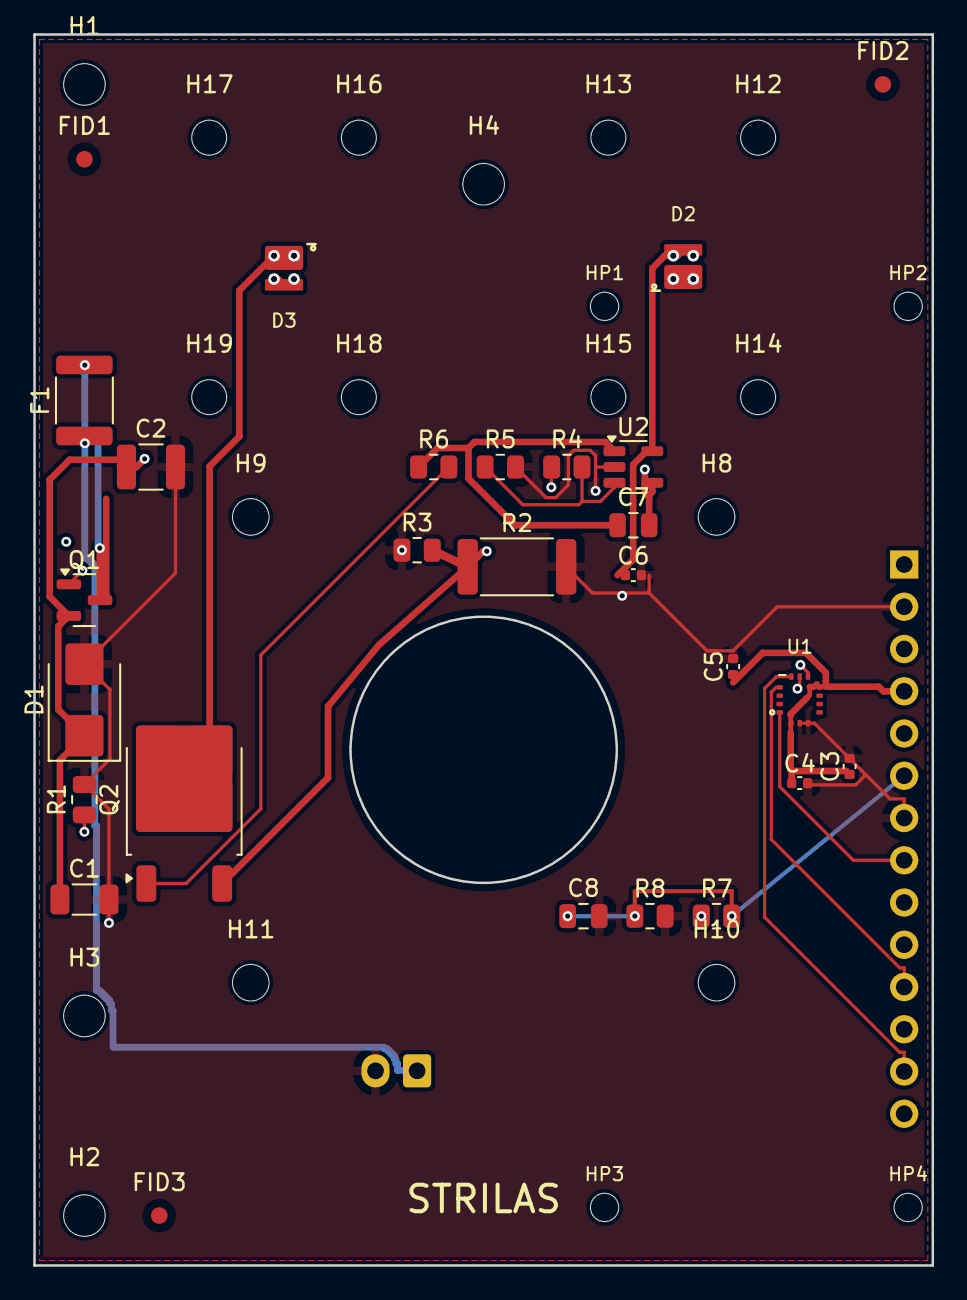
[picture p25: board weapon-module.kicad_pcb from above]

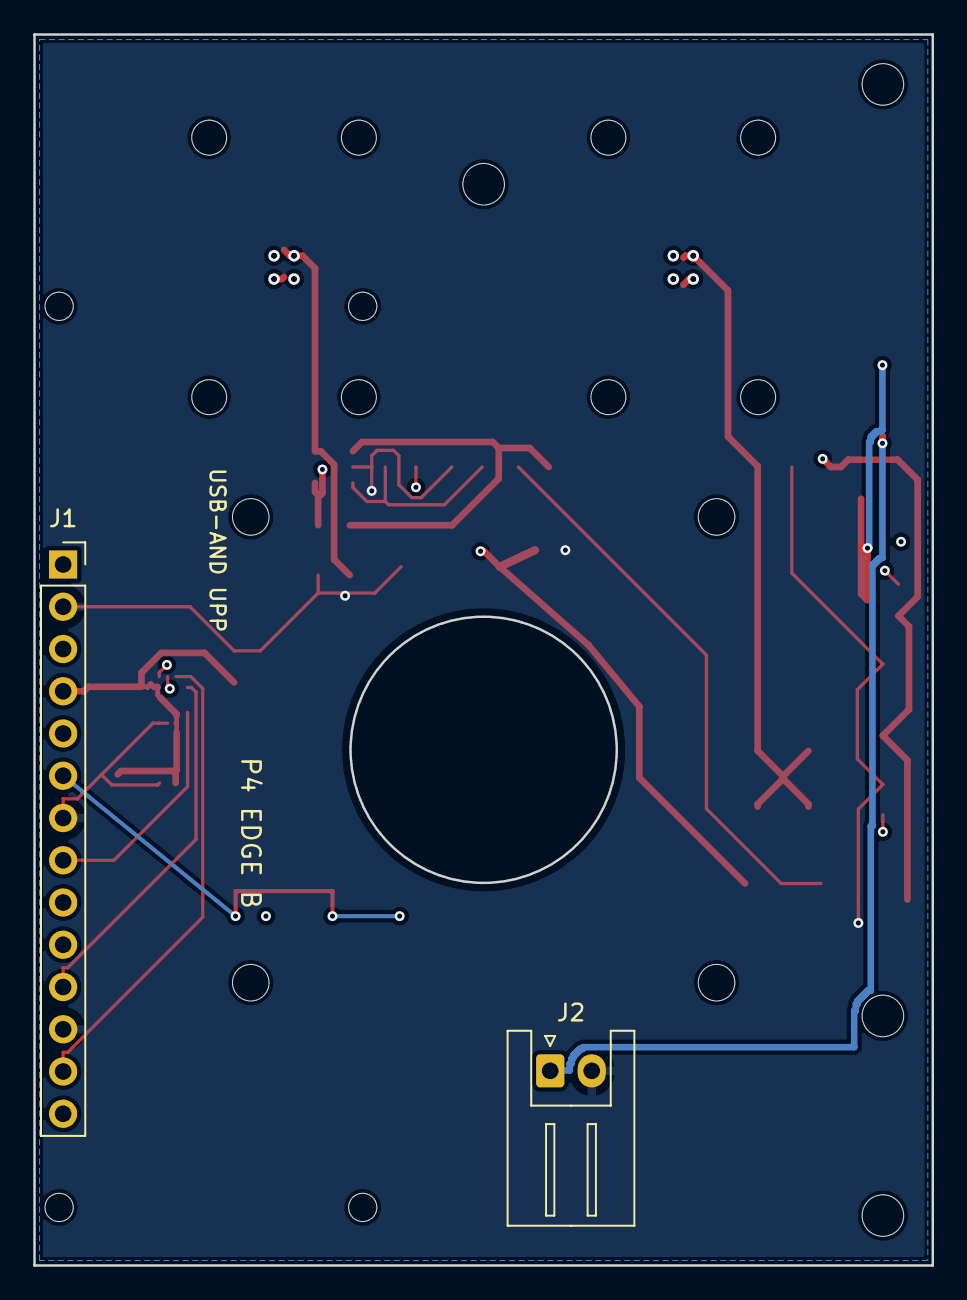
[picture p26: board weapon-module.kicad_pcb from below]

Board: 4 copper layers, 54.0 x 74.0 mm, 49 parts (2 on the bottom side), 19 nets.

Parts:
C1: C_1206_3216Metric
C2: C_1210_3225Metric
C3, C4: C_0402_1005Metric
C5: 1uF; C_0402_1005Metric
C6: 100nF; C_0402_1005Metric
C7, C8: C_0805_2012Metric
D1: D_SMB
D2, D3: SFH4725AS_940nm_bin13; IR_Emitter_OSRAM_OSLON_Black_SFH4725S
F1: PTC_3A; Fuse_1812_4532Metric
FID1, FID2, FID3: Fiducial_1mm_Mask2mm
H1, H2, H3, H4: MountingHole_2.5mm
H8, H9, H10, H11: MountingHole_2.2mm_M2
H12, H13, H14, H15, H16, H17, H18, H19: MountingHole_2.1mm
HP1, HP2, HP3, HP4: MountingHole_1.7mm
J1: PinSocket_1x14_P2.54mm_Vertical
J2: JST_XH_S2B-XH-A_1x02_P2.50mm_Horizontal
Q1: SOT-23
Q2: TO-252-2
R1, R4, R5, R6, R7, R8: R_0805_2012Metric
R2: R_2512_6332Metric
R3: 0R1 DNP=1A/montera=3A; R_0805_2012Metric
U1: InvenSense_LGA-14_2.5x3mm_ICM-456xx
U2: SOT-23-5

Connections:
+3V3: C3.1, C4.1, C5.1, J1.4, U1.5, U1.8
DRV_GATE: Q2.1, R6.2
GND: C1.2, C2.2, C3.2, C4.2, C5.2, C6.2, C8.2, D1.2, J1.2, J1.7, J1.12, J2.2, R1.2, R2.2, R3.1, R5.2, R8.2, U1.6, U1.7, U2.2
IDRV_REF: R4.2, R5.1, U2.3
IDRV_SENSE: C7.2, Q2.3, R2.1, R3.2, U2.4
IMU_INT: J1.11, U1.4
IR_MOD: J1.5, R4.1
LED_CATH: D3.2, Q2.2
LED_MID: D2.2, D3.1
MISO: J1.8, U1.1
MOSI: J1.13, U1.14
unnamed: Q1.1, R1.1
unnamed: C7.1, R6.1, U2.1
SCK: J1.9, U1.13
VBAT: C1.1, C2.1, C6.1, D1.1, D2.1, J1.1, Q1.2, R7.1, U2.5
VBAT_F: F1.2, Q1.3
VBAT_IN: F1.1, J2.1
VBAT_SENSE: C8.1, J1.6, R7.2, R8.1
nCS: J1.14, U1.12

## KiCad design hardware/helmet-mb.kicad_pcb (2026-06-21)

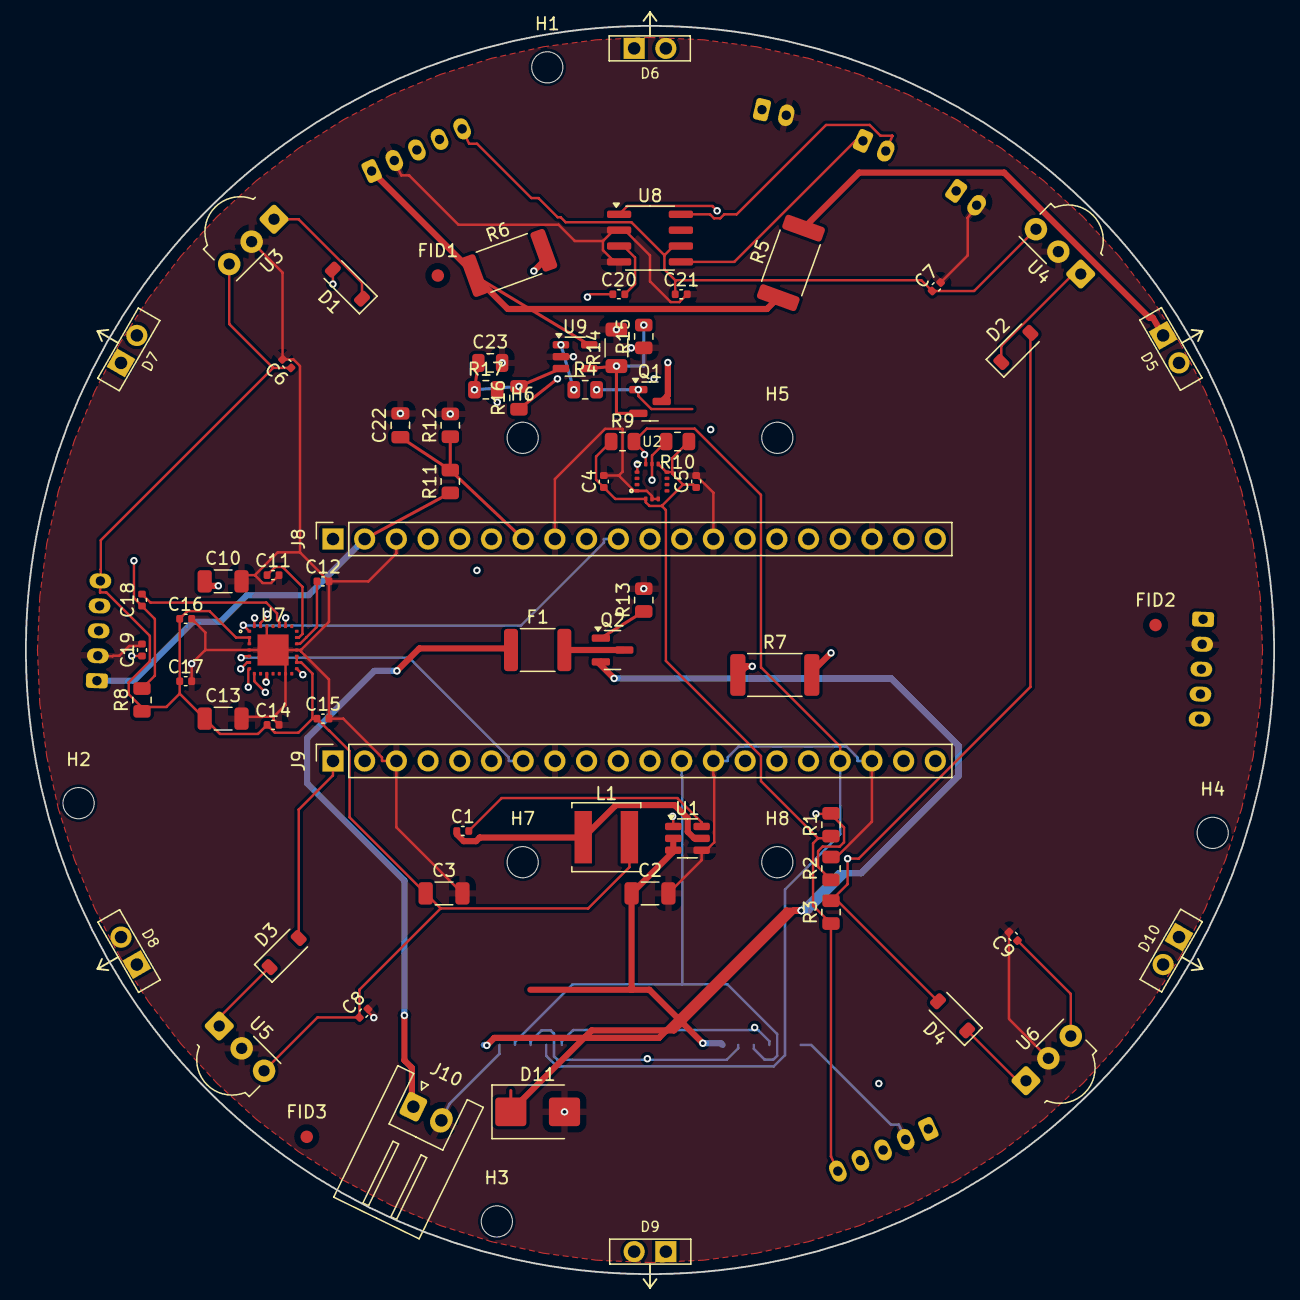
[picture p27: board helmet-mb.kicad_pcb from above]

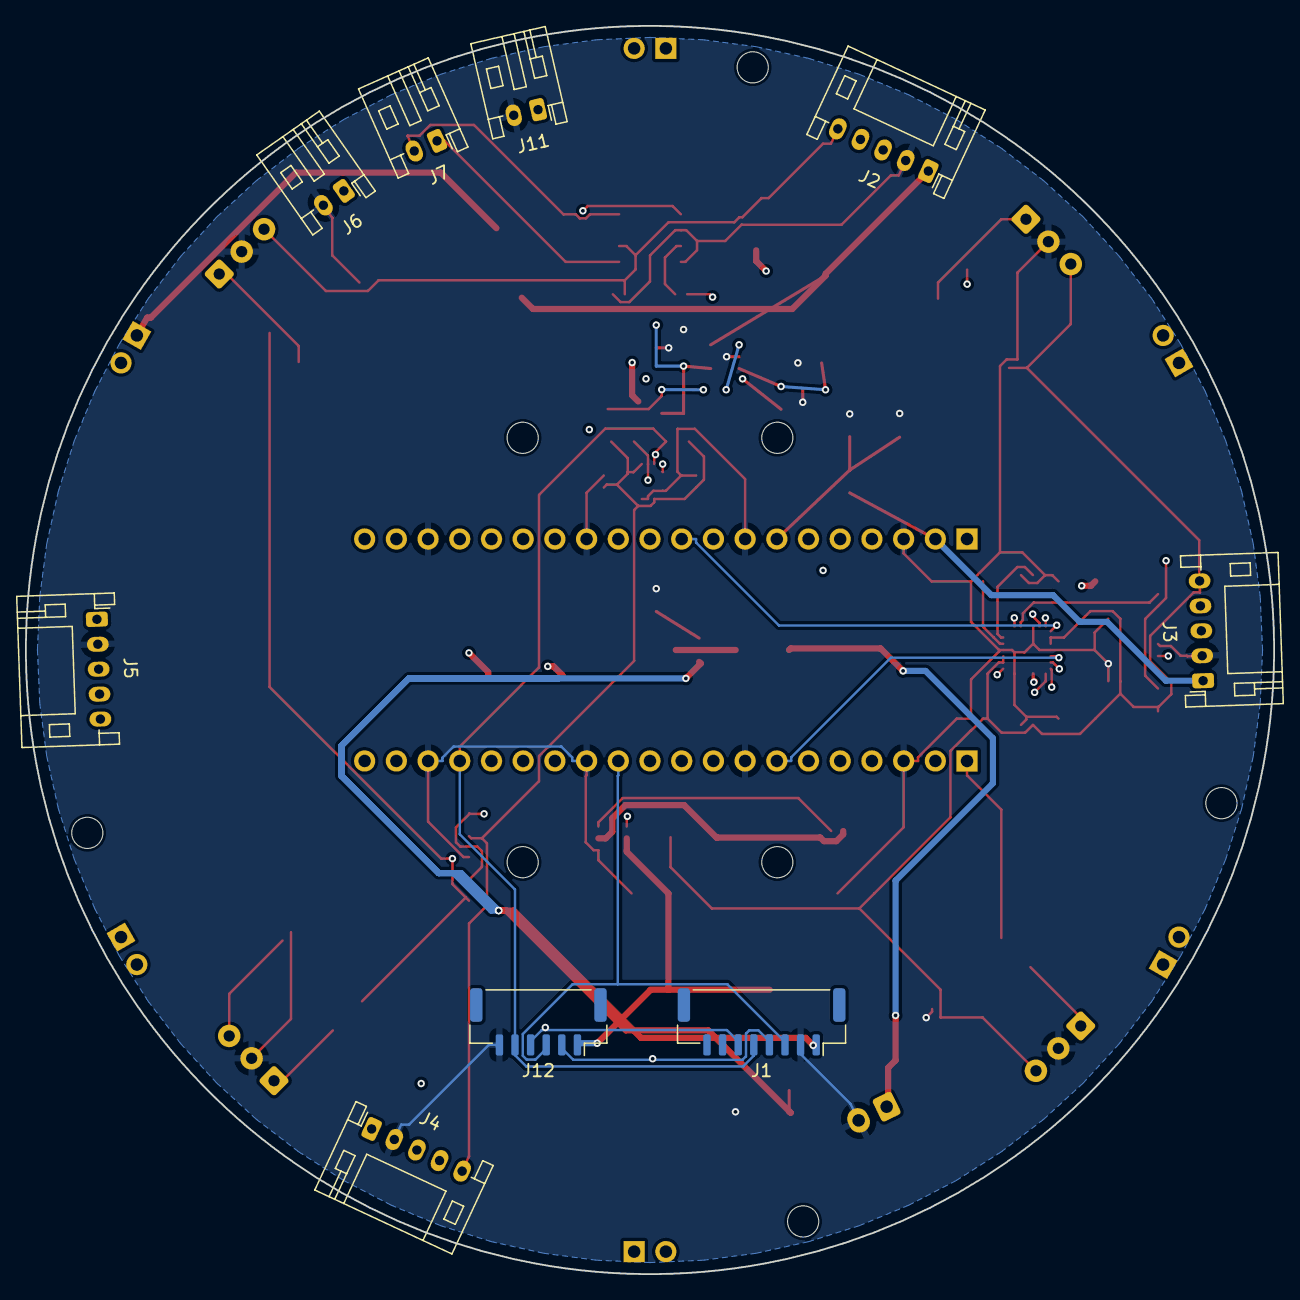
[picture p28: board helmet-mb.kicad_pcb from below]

Board: 4 copper layers, 100.0 x 100.0 mm, 87 parts (9 on the bottom side), 53 nets.

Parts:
C1, C4, C5, C6, C7, C8, C9, C11, C12, C14, C15, C16, C17, C18, C19, C20, C21: C_0402_1005Metric
C2, C3, C10, C13: C_1206_3216Metric
C22: C_0805_2012Metric
C23: 100nF; C_0805_2012Metric
D1, D2, D3, D4: D_SOD-123
D5, D6, D7, D8, D9, D10: LED-tab (VSMY98545 på micro-PCB med ben → böjs/vi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; LED_Tab
D11: D_SMB
F1: Fuse_1812_4532Metric
FID1, FID2, FID3: Fiducial_1mm_Mask2mm
H1, H2, H3, H4, H5, H6, H7, H8: MountingHole_2.5mm
J1: JST_GH_SM08B-GHS-TB_1x08-1MP_P1.25mm_Horizontal
J2, J3, J4, J5: JST_PH_S5B-PH-K_1x05_P2.00mm_Horizontal
J6, J7, J11: JST_PH_S2B-PH-K_1x02_P2.00mm_Horizontal
J8, J9: PinSocket_1x20_P2.54mm_Vertical
J10: JST_XH_S2B-XH-A_1x02_P2.50mm_Horizontal
J12: JST_GH_SM06B-GHS-TB_1x06-1MP_P1.25mm_Horizontal
L1: L_Changjiang_FNR5040S
Q1, Q2: SOT-23
R1, R2, R3, R8, R9, R10, R11, R12, R13: R_0805_2012Metric
R4: 100R; R_0805_2012Metric
R5, R6, R7: 1R; R_2512_6332Metric
R14: 0R2; R_1206_3216Metric
R15: 0R1 DNP=1A/montera=3A; R_0805_2012Metric
R16: 15k; R_0805_2012Metric
R17: 1k; R_0805_2012Metric
U1: TSOT-23-6
U2: InvenSense_LGA-14_2.5x3mm_ICM-456xx
U3, U4, U5, U6: Vishay_MOLD-3Pin
U7: ES8388; ES8388_QFN-28_4x4mm_P0.5mm
U8: SOIC-8_3.9x4.9mm_P1.27mm
U9: OPA171; SOT-23-5

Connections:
+3V3: C3.1, C4.1, C5.1, C6.1, C7.1, C8.1, C9.1, C13.1, C14.1, C15.1, C16.1, C17.1, C21.1, J2.5, J3.5, J4.5, J5.5, L1.2, R1.1, R3.1, R8.1, R9.1, R10.1, U2.5, U2.8, U2.12, U3.3, U4.3, U5.3, U6.3, U7.2, U7.3, U7.16, U7.17, U8.6
AMP_SD: J9.20, U8.1
BST: C1.2, U1.6
DATA_OB: D1.2, D2.2, D3.2, D4.2, J9.1, R3.2
DATA_P1: J2.3, J9.2
DATA_P2: J3.3, J9.4
DATA_P3: J4.3, J9.5
DATA_P4: J5.3, J9.6
FB: R1.2, R2.1, U1.1
GND: C2.2, C3.2, C4.2, C5.2, C6.2, C7.2, C8.2, C9.2, C10.2, C11.2, C12.2, C13.2, C14.2, C15.2, C16.2, C17.2, C19.2, C21.2, C22.2, C23.2, D11.2, J1.2, J2.2, J3.2, J4.2, J5.2, J6.2, J8.3, J8.8, J8.13, J8.18, J9.3, J9.8, J9.13, J9.18, J10.2, J11.2, J12.6, R2.2, R12.2, R13.2, R14.2, R15.1, R17.2, U1.4, U2.1, U2.6, U2.7, U3.2, U4.2, U5.2, U6.2, U7.4, U7.13, U7.18, U7.26, U7.29, U8.2, U8.4, U9.2
GNSS_RX: J1.4, J9.11, J12.2
GNSS_TX: J1.3, J9.12, J12.3
I2C_SCL: J1.6, J9.16, J12.4, R10.2, U2.13, U7.28
I2C_SDA: J1.5, J9.17, J12.5, R9.2, U2.14, U7.27
I2S_BCLK: J9.7, U7.5
I2S_DIN: J9.19, U7.8
I2S_DOUT: J9.10, U7.6
I2S_LRCK: J9.9, U7.7
I2S_MCLK: J8.10, U7.1
IDRV_GATE: R4.1, U9.1
IDRV_REF: C23.1, R16.2, R17.1, U9.3
IDRV_SENSE: Q1.2, R14.1, R15.2, U9.4
IMU_INT: J9.14, U2.4
LED_A1: D5.1, R5.2
LED_A2: D7.1, R6.2
LED_A3: D9.1, R7.2
LED_CATH: D6.2, D8.2, D10.2, Q1.3
LED_EN: J2.4, J3.4, J4.4, J5.4, J9.15, R16.1
LED_M1: D5.2, D6.1
LED_M2: D7.2, D8.1
LED_M3: D9.2, D10.1
LINE_OUT: C20.2, U8.3
MIC_HOT: C18.1, J6.1, R8.2
unnamed: Q1.1, R4.2
unnamed: C10.1, U7.10
unnamed: C11.1, U7.20
unnamed: C12.1, U7.19
unnamed: C18.2, U7.24
unnamed: C19.1, U7.23
unnamed: C20.1, U7.15
unnamed: Q2.1, R13.1
OB_OUT1: D1.1, U3.1
OB_OUT2: D2.1, U4.1
OB_OUT3: D3.1, U5.1
OB_OUT4: D4.1, U6.1
PTT: J8.6, J11.1
SPK_N: J7.2, U8.8
SPK_P: J7.1, U8.5
SW: C1.1, L1.1, U1.5
VBAT: C2.1, D11.1, J1.1, J2.1, J3.1, J4.1, J5.1, J8.2, J12.1, Q2.2, R5.1, R6.1, R7.1, R11.1, U1.2, U1.3, U9.5
VBAT_IN: F1.1, J10.1
VBAT_RAW: F1.2, Q2.3
VBAT_SENSE: C22.1, J8.7, R11.2, R12.1

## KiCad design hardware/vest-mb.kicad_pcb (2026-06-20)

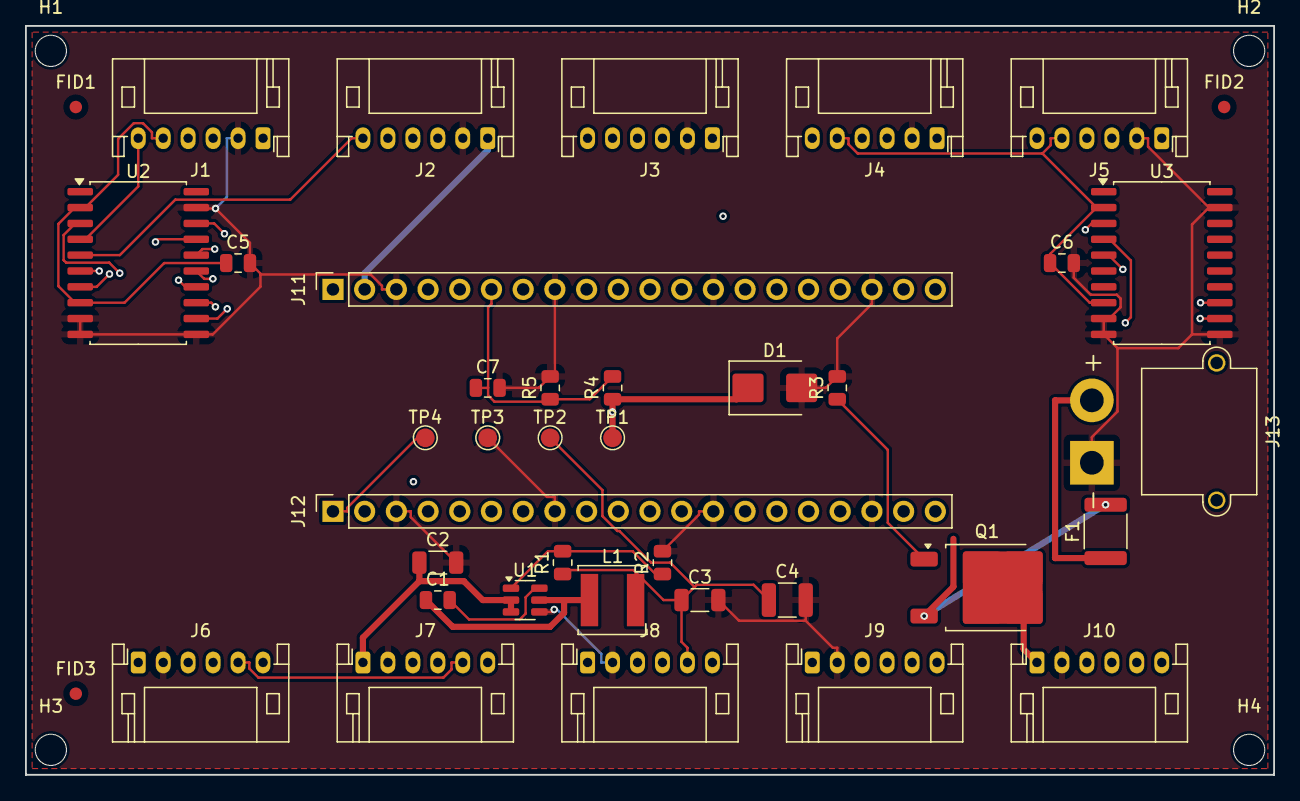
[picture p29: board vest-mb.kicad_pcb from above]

Board: 4 copper layers, 100.0 x 60.0 mm, 43 parts (0 on the bottom side), 35 nets.

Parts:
C1, C5, C6, C7: C_0805_2012Metric
C2, C3: C_1206_3216Metric
C4: C_1210_3225Metric
D1: D_SMB
F1: Fuse_1812_4532Metric
FID1, FID2, FID3: Fiducial_1mm_Mask2mm
H1, H2, H3, H4: MountingHole_2.5mm
J1, J2, J3, J4, J5, J6, J7, J8, J9, J10: JST_PH_S6B-PH-K_1x06_P2.00mm_Horizontal
J11, J12: PinSocket_1x20_P2.54mm_Vertical
J13: AMASS_XT30PW-M_1x02_P2.50mm_Horizontal
L1: L_Changjiang_FNR5040S
Q1: TO-252-2
R1, R2, R3, R4, R5: R_0805_2012Metric
TP1, TP2, TP3, TP4: TestPoint_Pad_D1.5mm
U1: TSOT-23-6
U2, U3: SOIC-20W_7.5x12.8mm_P1.27mm

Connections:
+3V3: C3.1, C4.1, C5.1, C6.1, J1.5, J2.5, J3.5, J4.5, J5.5, J6.5, J7.5, J8.5, J9.5, J10.5, L1.2, R1.1, TP2.1, U2.2, U2.8, U3.2, U3.8
BST: C1.2, U1.6
DATA1: J1.3, J12.1, TP4.1
DATA2: J2.3, J12.2
DATA3: J3.3, J12.4
DATA4: J4.3, J12.5
DATA5: J5.3, J12.6
DATA6: J6.3, J12.7
DATA7: J7.3, J12.9
DATA8: J8.3, J12.10
DATA9: J9.3, J12.11
DATA10: J10.3, J12.12
FB: R1.2, R2.1, U1.1
GND: C2.2, C3.2, C4.2, C5.2, C6.2, C7.2, D1.2, J1.2, J2.2, J3.2, J4.2, J5.2, J6.2, J7.2, J8.2, J9.2, J10.2, J11.3, J11.8, J11.13, J11.18, J12.3, J12.8, J12.13, J12.18, J13.1, R2.2, R3.2, R5.2, TP3.1, U1.4, U2.9, U2.10, U2.11, U2.19, U3.9, U3.10, U3.11, U3.19
LED_EN: J1.4, J2.4, J3.4, J4.4, J5.4, J6.4, J7.4, J8.4, J9.4, J10.4, J12.17
unnamed: Q1.1, R3.1
SW: C1.1, L1.1, U1.5
TPIC_CHAIN: U2.18, U3.3
TPIC_RCK: J12.16, U2.12, U3.12
TPIC_SER: J12.14, U2.3
TPIC_SRCK: J12.15, U2.13, U3.13
VBAT: C2.1, D1.1, J1.1, J2.1, J3.1, J4.1, J5.1, J6.1, J7.1, J8.1, J9.1, J10.1, J11.2, Q1.2, R4.1, TP1.1, U1.2, U1.3
VBAT_IN: F1.1, J13.2
VBAT_RAW: F1.2, Q1.3
VBAT_SENSE: C7.1, J11.6, R4.2, R5.1
VIB1: J1.6, U2.4
VIB2: J2.6, U2.5
VIB3: J3.6, U2.6
VIB4: J4.6, U2.7
VIB5: J5.6, U2.14
VIB6: J6.6, U2.15
VIB7: J7.6, U2.16
VIB8: J8.6, U2.17
VIB9: J9.6, U3.4
VIB10: J10.6, U3.5

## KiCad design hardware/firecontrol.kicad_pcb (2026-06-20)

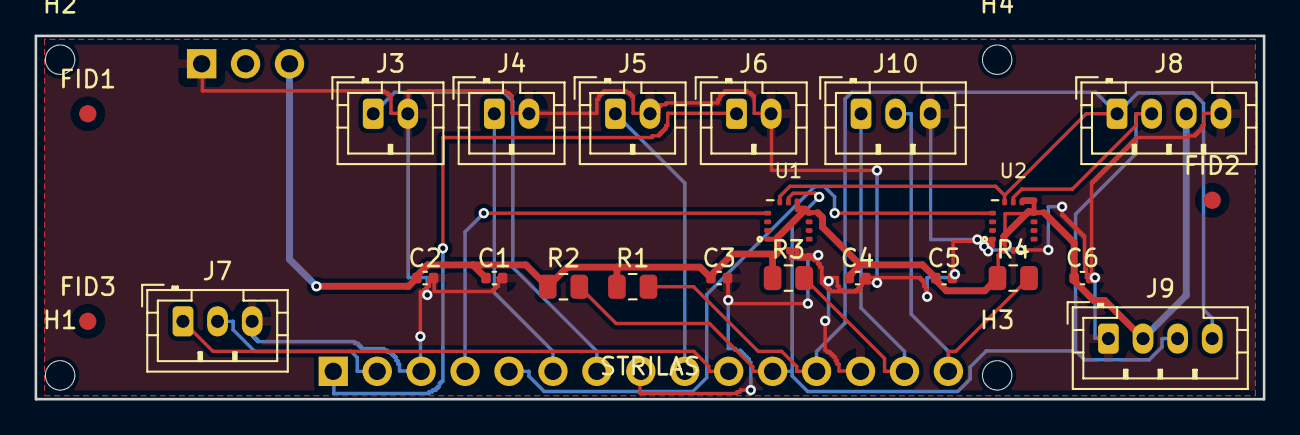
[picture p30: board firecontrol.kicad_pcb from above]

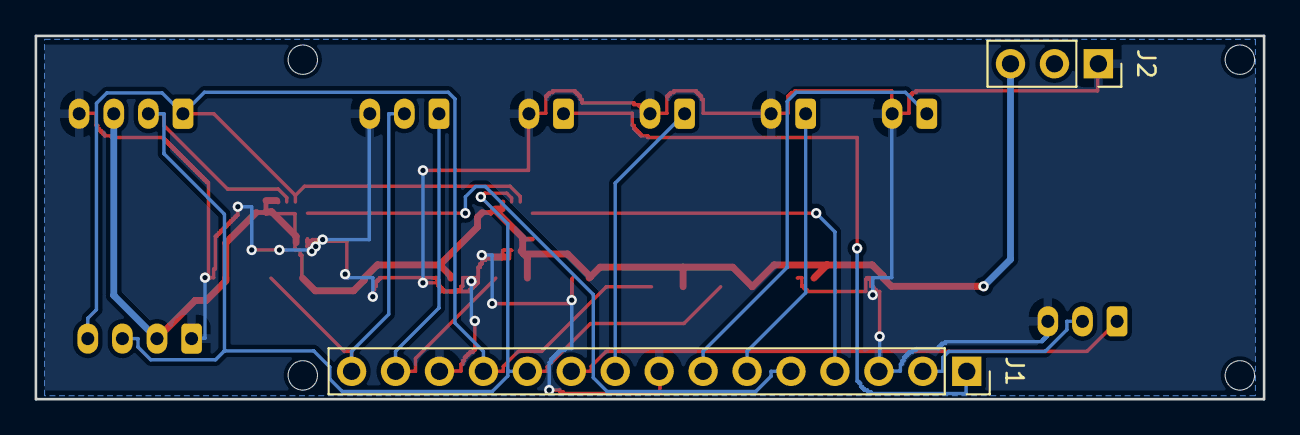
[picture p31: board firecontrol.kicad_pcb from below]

Board: 2 copper layers, 71.0 x 21.0 mm, 29 parts (2 on the bottom side), 14 nets.

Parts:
C1, C2, C3, C4, C5, C6: C_0402_1005Metric
FID1, FID2, FID3: Fiducial_1mm_Mask2mm
H1, H2, H3, H4: MountingHole_1.7mm
J1: P4-socket edge A pin6-20; PinSocket_1x15_P2.54mm_Vertical
J2: PinSocket_1x03_P2.54mm_Vertical
J3, J4, J5, J6: JST_PH_B2B-PH-K_1x02_P2.00mm_Vertical
J7: JST_PH_B3B-PH-K_1x03_P2.00mm_Vertical
J8: JST_PH_B4B-PH-K_1x04_P2.00mm_Vertical
J9: OLED SSD1306 I2C; JST_PH_B4B-PH-K_1x04_P2.00mm_Vertical
J10: 4-laedes rotarykopplare; JST_PH_B3B-PH-K_1x03_P2.00mm_Vertical
R1, R2: R_0805_2012Metric
R3, R4: 4k7; R_0805_2012Metric
U1, U2: InvenSense_LGA-14_2.5x3mm_ICM-456xx

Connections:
+3V3: C1.1, C2.1, C3.1, C4.1, C5.1, C6.1, J2.3, J8.3, J9.2, R1.1, R2.1, R3.1, R4.1, U1.1, U1.5, U1.8, U1.12, U2.5, U2.8, U2.12
GND: C1.2, C2.2, C3.2, C4.2, C5.2, C6.2, J1.3, J1.8, J1.13, J2.1, J3.2, J4.2, J5.2, J6.2, J7.3, J8.4, J9.1, J10.3, U1.6, U1.7, U2.1, U2.6, U2.7
IMU2_INT: J1.4, U1.4
IMU3_INT: J1.5, U2.4
MAGWELL: J1.1, J6.1
MAG_REL: J1.9, J5.1
MODE_A: J1.14, J10.1, R3.2
MODE_B: J1.15, J10.2, R4.2
NFC_SCL: J1.11, J8.2, J9.3, R2.2, U1.13, U2.13
NFC_SDA: J1.12, J8.1, J9.4, R1.2, U1.14, U2.14
RACK: J1.6, J4.1
RECOIL_FAULT: J1.2, J7.2
RECOIL_PWM: J1.10, J7.1
TRIG: J1.7, J3.1

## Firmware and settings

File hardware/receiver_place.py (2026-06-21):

#!/usr/bin/env python3
"""STRILAS — placera + nät-tilldela receiver-korten (väst + hjälm) ur netlistan (pcbnew).
Nyckeldelar placeras enligt receiver_boards_layout; smådelar grid-placeras i fri zon.
Ritar outline (+ hjälm-centrumhål). Sparar .kicad_pcb. (Routas sedan av freerouting.)
"""
import re, math, os, sys, pcbnew

FPDIR = "/usr/share/kicad/footprints"
LOCAL = os.path.join(os.path.dirname(os.path.abspath(__file__)), "strilas.pretty")
MM = pcbnew.FromMM


def fp_load(lib, fp):
    """Ladda footprint; 'strilas' = lokalt projektbibliotek, annars KiCad-standard."""
    path = LOCAL if lib == "strilas" else f"{FPDIR}/{lib}.pretty"
    return pcbnew.FootprintLoad(path, fp)


def parse_net(path):
    t = open(path).read()
    comps = {}
    for m in re.finditer(r'\(comp\s*\(ref "([^"]+)"\).*?\(footprint "([^"]+)"\)', t, re.S):
        comps[m.group(1)] = m.group(2)
    nets = {}
    ns = t[t.index("(nets"):]
    for blk in re.split(r'\(net\s*\(code', ns)[1:]:
        nm = re.search(r'\(name "([^"]+)"\)', blk)
        nodes = re.findall(r'\(ref "([^"]+)"\)\s*\(pin "([^"]+)"', blk)
        if nm and nodes:
            nets[nm.group(1)] = nodes
    return comps, nets


def place(netfile, pcbfile, positions, outline, layers=2, center_hole=None, free=(-20, 20, -15, 15), cutout=None, labels=None):
    comps, nets = parse_net(netfile)
    board = pcbnew.CreateEmptyBoard()
    board.SetCopperLayerCount(layers)
    OX, OY = 150.0, 120.0
    def V(x, y): return pcbnew.VECTOR2I(MM(OX + x), MM(OY - y))
    fps = {}
    # grid-positioner för delar utan explicit position
    gx0, gx1, gy0, gy1 = free
    ylo, yhi = sorted([int(gy0), int(gy1)]); xlo, xhi = sorted([int(gx0), int(gx1)])
    grid = [(x, y) for y in range(yhi, ylo-1, -4) for x in range(xlo, xhi+1, 5)]
    gi = 0
    for ref, fpname in comps.items():
        lib, fp = fpname.split(":")
        f = fp_load(lib, fp)
        if f is None:
            print(f"  !! KAN EJ LADDA {fpname} ({ref})"); continue
        f.SetReference(ref)
        flip = False
        if ref in positions:
            p = positions[ref]; x, y, rot = p[0], p[1], p[2]; flip = len(p) > 3 and p[3] == "B"
        else:
            x, y = grid[gi % len(grid)]; rot = 0; gi += 1
        f.SetPosition(V(x, y))
        if rot: f.SetOrientationDegrees(rot)
        board.Add(f); fps[ref] = f
        if flip:
            try: f.Flip(f.GetPosition(), False)
            except Exception as e: print(f"  flip {ref} fail: {e}")
    # nät
    for name, nodes in nets.items():
        net = pcbnew.NETINFO_ITEM(board, name); board.Add(net)
        for ref, pad in nodes:
            f = fps.get(ref)
            if not f: continue
            for p in f.Pads():
                if p.GetName() == pad: p.SetNet(net)
    # outline
    if outline[0] == "rect":
        _, hw, hh = outline
        pts = [(-hw, -hh), (hw, -hh), (hw, hh), (-hw, hh)]
        for i in range(4):
            s = pcbnew.PCB_SHAPE(board, pcbnew.SHAPE_T_SEGMENT)
            s.SetStart(V(*pts[i])); s.SetEnd(V(*pts[(i+1) % 4]))
            s.SetLayer(pcbnew.Edge_Cuts); s.SetWidth(MM(0.15)); board.Add(s)
    else:  # circle
        _, r = outline
        c = pcbnew.PCB_SHAPE(board, pcbnew.SHAPE_T_CIRCLE)
        c.SetCenter(V(0, 0)); c.SetEnd(V(r, 0))
        c.SetLayer(pcbnew.Edge_Cuts); c.SetWidth(MM(0.15)); board.Add(c)
    if center_hole:
        ch = pcbnew.PCB_SHAPE(board, pcbnew.SHAPE_T_CIRCLE)
        ch.SetCenter(V(0, 0)); ch.SetEnd(V(center_hole, 0))
        ch.SetLayer(pcbnew.Edge_Cuts); ch.SetWidth(MM(0.15)); board.Add(ch)
    if cutout:                              # lins-hål (kamera bakom kortet)
        cx, cy, cr = cutout
        co = pcbnew.PCB_SHAPE(board, pcbnew.SHAPE_T_CIRCLE)
        co.SetCenter(V(cx, cy)); co.SetEnd(V(cx+cr, cy))
        co.SetLayer(pcbnew.Edge_Cuts); co.SetWidth(MM(0.15)); board.Add(co)
    # silkscreen-etiketter (t.ex. sikt-pilar för TSOP-böjning): (x, y, text, [size_mm])
    for lab in (labels or []):
        lx, ly, txt = lab[0], lab[1], lab[2]
        sz = lab[3] if len(lab) > 3 else 1.2
        t = pcbnew.PCB_TEXT(board); t.SetText(txt)
        t.SetPosition(V(lx, ly)); t.SetLayer(pcbnew.F_SilkS)
        t.SetTextSize(pcbnew.VECTOR2I(MM(sz), MM(sz))); t.SetTextThickness(MM(sz * 0.15))
        t.SetHorizJustify(pcbnew.GR_TEXT_H_ALIGN_CENTER)
        board.Add(t)
    pcbnew.SaveBoard(pcbfile, board)
    print(f"  {pcbfile}: {len(fps)} komponenter, {len(nets)} nät")


# ---- väst-patch (täcknings-NOD 37×37, FYRFALDIGT SYMMETRISK, 4 monteringshål) — 4 ledade TSOP4856, kardborre/lim ----
# SIKTE (beräknat optimum, se vapen-stack/ritningar/patch-sikte.md): 4 mottagare jämnt 90° isär i
# DIAMANT (NÖ/NV/SV/SÖ), var och en böjd ~40° UTÅT från kortets normal (ben böjs; silk-pil visar).
# → 99,5 % av framåt-hemisfären, 100 % inom 60° zenit, ~2,3 mottagare ser ett frontalskott (redundans).
# Full 4-falds symmetri → patchen kan placeras i VALFRI vridning på västen och funkar lika bra.
# Dom-aim vs footprint-rot (verif.): rot0=NED rot90=HÖGER rot180=UPP rot270=VÄNSTER → aim_az=(rot+270)%360.
# Refs: U1-4=TSOP · varje TSOP har egen OR-diod (D1-4) + avkoppl-C (C2-5) BREDVID sig (4 identiska kluster).
#       D5,D6=OSLON 860nm konstellation (N/S, symmetriskt) · R3,R4=10R 2512 · delat: J1=1x5, Q1=FET,
#       R1=DATA-pull, R2=gate, C1=bulk — centrerat. (konstellations-LED ≠ per-TSOP; de är kamera-markörer.)
import math as _math
def _ring2(r, deg): return (round(r*_math.cos(_math.radians(deg)), 2), round(r*_math.sin(_math.radians(deg)), 2))
# RUND väst-patch (kompakt, för skydds-/dom-kåpa). Optiken på kanten, aim radiellt UT (TSOP-ben +
# LED-tabbar böjs 40° ut → ingen platt frontruta skuggar synvinkeln, funkar i valfri vridning).
# Centrum = driver + kontakt + 2 fasta OSLON. Speglar hjälm-halons verifierade ring-mönster, nedskalat
# till minsta Ø utan courtyard-krock (de 4 LEDADE TSOP-benens svep sätter undre gränsen).
# courtyard-mittpunkt ≠ origo för TSOP (2.54,1.31) & 1x5-header (0,5.07) → kompensera så att KROPPEN
# (ej origo) hamnar centrerad på ringen/positionen. _comp = origo som ger önskad courtyard-mitt.
def _comp(cx, cy, rot, off):
    # origo som ger courtyard-CENTRUM på (cx,cy) efter SetOrientationDegrees(rot). off = courtyard-mitt-
    # offset frå origo @rot0 i KiCad-footprint-koord (Y-ned). Board-offset (Y-upp) = standardrot(rot)·(ox,-oy).
    # (KALIBRERAT mot faktisk placerad board — tidigare formel hade Y-teckenfel → asymmetriska TSOP.)
    rad = _math.radians(rot); ox, oy = off
    dx = ox*_math.cos(rad) + oy*_math.sin(rad)
    dy = ox*_math.sin(rad) - oy*_math.cos(rad)
    return (round(cx - dx, 2), round(cy - dy, 2))
def _se(theta, r_pad, npin, opening="out", flip=False):
    """Side-entry JST (S-typ): pad-rad TANGENTIELLT centrerad @ (r_pad, theta), kropp/kabel-öppning
    RADIELLT. opening='out' → kabel ut mot kanten; 'in' → mot centrum. Kalibrerat: front opening=(rot+270)%360,
    flip opening=(90-rot)%360; padrow front=rot, flip=(-rot). Returnerar (origin_x, origin_y, rot[, 'B'])."""
    th = _math.radians(theta)
    pcx, pcy = r_pad*_math.cos(th), r_pad*_math.sin(th)     # pad-rad-centrum (board y-up)
    odir = theta % 360 if opening == "out" else (theta + 180) % 360
    rot = ((90 - odir) % 360) if flip else ((odir + 90) % 360)
    prang = (-rot) % 360 if flip else rot                  # pad-rad-riktning
    half = (npin - 1) * 2 / 2.0
    ox = pcx - half*_math.cos(_math.radians(prang)); oy = pcy - half*_math.sin(_math.radians(prang))
    return (round(ox, 2), round(oy, 2), rot) + (("B",) if flip else ())
_OFF_TSOP = (2.54, 1.31)                 # TSOP-courtyard-mitt-offset (courtyard centreras på ringen)
_PT, _PD, _PC = 16.0, 11.0, 8.5          # TSOP-courtyard / OR-diod / avkoppling — ALLA på TSOP-ekern (radiellt)
_PL, _PH = 16.0, 20.0                    # LED-tab-ring (kardinal) / monteringshål (yttre annulus, i luckorna)
_VEST_R = 22.5                            # kort-radie (Ø45) — rund, ryms i Ø46,5-dom (ren symmetri kräver annulus)
vest_pos = {}
# 4 TSOP @ DIAGONALER (45/135/225/315) — OR-diod (D1-4) + avkoppling (C2-5) RADIELLT INÅT på SAMMA
# eker (4 IDENTISKA kluster → full symmetri; ingen +11°-lutning längre).
for i, a in enumerate((45, 135, 225, 315)):
    rot = (a + 90) % 360
    cx, cy = _ring2(_PT, a)
    vest_pos[f"U{i+1}"] = (*_comp(cx, cy, rot, _OFF_TSOP), rot)   # TSOP-kropp centrerad på ringen
    vest_pos[f"D{i+1}"] = (*_ring2(_PD, a), rot)                  # OR-diod på ekern (radiellt inåt)
    vest_pos[f"C{i+2}"] = (*_ring2(_PC, a), rot)                  # avkoppling stackad innanför OR
# 4 LED-tabbar @ KARDINALER (0/90/180/270) — pad-rad TANGENTIELL (precis som TSOP) så tabben viks
# radiellt UT (böjs 40°, LED mot horisonten). rot=(a+180) → pad-axel tangentiell (a+90).
# _comp m. off=(0,1.27): centrera pad-MITTPUNKTEN (mellan de 2 hålen) + 3D-modellen på ring-punkten
# (footprint-origo=pad1 → annars hamnar de 2 hålen osymmetriskt utåt). → hål straddlar kardinalen symmetriskt.
for i, a in enumerate((0, 90, 180, 270)):
    rot = a % 360                  # FIX: +X-emission RADIELLT UT (var a+180=inåt)
    cx, cy = _ring2(_PL, a)
    vest_pos[f"D{i+7}"] = (*_comp(cx, cy, rot, (0.0, 1.27)), rot)
# 4 monteringshål MITT i TSOP→tab-luckorna (67.5/157.5/247.5/337.5) → symmetriskt, EJ snett mot tab/TSOP
for i, a in enumerate((67.5, 157.5, 247.5, 337.5)):
    vest_pos[f"H{i+1}"] = (*_ring2(_PH, a), 0)
# CENTRUM: 2 fasta VSMY-LED (topp) + FIRMWARE-TRIMBAR CC-SÄNKA (U5 op-amp + Q1 pass-FET + R6 sense +
# R7 DNP-3A-override + R8/R9 tak-delare + C6 RC-filter) i nedre halvan + 3× balans-R (R3-R5) radiellt.
# J1 (6-pol JST-PH) SIDOMONTERAD på BAKSIDAN. Branch-R krympta 2512→1206 (CC sätter ström → frigör yta).
vest_pos.update({
    "D5": (-2.4, 1.5, 0), "D6": (2.4, 1.5, 0),       # 2 fasta VSMY-konstellation (aim upp), center-par
    "R1": (0.0, 5.2, 0),                             # DATA-pull 10k (övre center, mellan LED-par o R3)
    "Q1": (0.0, -3.5, 0),                            # pass-FET (CC-sänka), center
    "U5": (-3.98, -2.3, 0),                          # OPA171 CC-op-amp (vänster om FET)
    "R2": (3.8, -3.0, 0),                            # gate-R 100R (op-amp OUT → Q1.G), höger om FET
    "R6": (0.0, -6.5, 0),                            # sense 0R2 (Q1.S → GND), under FET
    "C6": (-3.19, -8.98, 0),                         # RC-filter 100nF (PWM→Vref)
    "R7": (2.9, -8.99, 0),                           # 3A-override DNP 0R1 (parallellt R6)
    "R8": (-9.65, -4.03, 0),                         # tak-delare 15k (LED_EN→Vref) — clear av J1 TH-pad
    "R9": (6.5, -1.71, 90),                          # tak-delare 1k (Vref→GND) — clear av J1 TH-pad
    "C1": (0.0, -10.0, 90),                          # 10µF bulk (VBAT) — nedre center
    "R3": (0.0, 9.0, 0),                             # balans-R gren-1 (radiellt, mellan center o tab)
    "R4": (9.0, 0.0, 90), "R5": (-9.0, 0.0, 90),     # balans-R gren-2/3 (spegel)
    "J1": _se(270, 14.0, 6, "out", flip=True),       # 6-pol JST-PH SIDOMONT. på BAKSIDAN (VBAT·GND·DATA·LED_EN·3V3·VIB)
    "J2": (-13.0, -2.5, 90, "B"),                   # 2-pol JST → ERM-motor (BAKSIDA). Flyttad in i ben-gapet (-17,-6→-13,-2.5): kroppen klarar alla genomstuckna TSOP/tab-ben (kvar @kant krockade m U3-benet), kabel pekar mot center-motorn
})
vest_labels = [(0.0, 7.2, "BOJ 40 UT", 0.4)]         # böj-instruktion (kort, övre center-fri yta)

# ---- hjälm-NOD (Ø100, komplett: buck+XIAO-S3+8TSOP+4LED+GNSS+I2S-audio) ----
# Ring (r=42) = 8× TSOP utåtriktade (360° huvud) + diod-OR + avkoppling strax innanför.
# 4× LED-konstellation (r=45) mellan TSOP-paren. Centrum = stackad XIAO + buck + modul-headers.
def _ring(r, deg): return (round(r*math.cos(math.radians(deg)), 1), round(r*math.sin(math.radians(deg)), 1))
helmet_pos = {}
for i in range(8):                                   # U2..U9 TSOP, D1..D8 BAT54, C4..C11 avkoppl (yttre ring)
    a = i*45
    helmet_pos[f"U{i+2}"] = (*_ring(41, a), (a+90) % 360)
    helmet_pos[f"D{i+1}"] = (*_ring(34, a), (a+90) % 360)
    helmet_pos[f"C{i+4}"] = (*_ring(26, a), (a+90) % 360)
for i in range(4):                                   # D9..D12 LED, R5..R8 10R-serieR (mellan TSOP-paren)
    a = 22.5 + i*90
    helmet_pos[f"D{i+9}"] = (*_ring(45, a), (a+90) % 360)
    helmet_pos[f"R{i+5}"] = (*_ring(36, a), (a+90) % 360)
helmet_pos.update({                                  # centrum-disk (r<27, innanför avkopplings-ringen)
    "J1": (-7.6, 0, 0), "J2": (7.6, 0, 0),           # XIAO ESP32-S3 (2× 1x7 sockel, lodräta rader)
    "U1": (-4, 17, 0), "L1": (4, 17, 0),             # buck + induktor (ovan XIAO)
    "C1": (-10, 14, 0), "C2": (-10, 20, 0), "C3": (12, 19, 0),  # Cbst / Cin / Cout
    "R1": (-1, 22, 90), "R2": (-1, 13, 90),          # FB-delare
    "R3": (-12, 9, 0),                               # DATA-pullup (nära XIAO D0)
    "J3": (0, -21.5, 0),                             # ZED-F9P 8-pol JST GH (nedan XIAO; puck i centrum, kabel)
    "J4": (21, 2, 0), "J5": (-22, 0, 0),             # amp 1x7 (höger) / mik 1x6 (vänster)
    "Q1": (13, 13, 0), "R4": (17, 12, 90),           # LED-driver + gate
    "J6": (35, -7, 0),                               # 2S-batteri JST (tom yttre-ring-lucka, mellan U9/U2)
    "H1": _ring(47, 45) + (0,), "H2": _ring(47, 135) + (0,),
    "H3": _ring(47, 225) + (0,), "H4": _ring(47, 315) + (0,),
})

# ---- vapen-optikmodul (42×62, P4-carrier) ----
# Lins-hål Ø16 i mitten (kamera bakom kortet): keepout x[-8,8] y[-12,4].
# Pulsloop hålls kort: C2(reservoar)→D2→D3→Q2(CC pass-FET)→R2(sense)→GND uppe.
# IMU + avkoppling i höger remsa; inmatningsskydd nere till vänster; headers nederst.
# Kamerafäste (B0332 38×38): 4× M2-hål i 28×28-mönster runt linsaxeln (0,-4).
#   H4(-14,10) H5(14,10) H6(-14,-18) H7(14,-18). Komponenter flyttade ut till kanterna
#   så dessa hål + standoffs är fria. Kameran skruvas fast bakom kortet, lins genom Ø16.
# P4-VÄNSTERLÄGE (enligt användarens Fusion-modell): P4 (71×21) ligger bakom kortet,
# huggande VÄNSTERKANTEN (centrum x≈-16, längd längs y, USB-C-änden UPP/ESP-änden ned).
# Edge B (VBUS/VSYS/3V3-sidan) ytterst (vänster) → optik-J1. Edge A (GPIO-sidan) inåt → FC-stack.
# Kamerans B4B-ZR-kontakt riktad +x (höger) → fri från P4. J1 (P4-kantkontakt) flyttad
# till vänsterkanten (P4:ans yttre signalrad). Kraft/skydd-remsa flyttad till HÖGERkanten;
# AKTIV KONSTANTSTRÖMS-SÄNKA (ersätter Rset): op-amp U2 + DPAK pass-FET Q2 + sense R2 +
# referensdelare R3/R4 + gate-R R5 + komp C7 + op-amp-avkoppl C6. Klustret i fria zonen
# x[-10,10] y[4,13] (mellan kamerahål H8/H9 @±14, under Carclo-ben @y15.2, ovan lins-keepout @y2).
# Funktioner (skidl-ref): U2=OPA171, Q2=AOD4184A(DPAK), R2=0R2 sense, R3=15k, R4=1k, R5=100R gate,
#   C2=Cbulk 100µF, C6=op-amp-avkoppl, C7=komp 100pF, F1=PTC, Q1=PFET(rev-pol), D1=TVS,
#   R1=100k-pulldown, C1=Cin 10µF, U1=IMU, C3/C4/C5=IMU-avkoppl.
weapon_box = {   # 54×74 mm: 2× Ø20-lins+kamera fram; P4 (15mm-standoff) bakom VÄNSTER; centrum-kort-hål
    "D2": (-12, 23, 0), "D3": (12, 23, 180),
    # 8 Carclo-ben (H12-H19): D2 H12-H15, D3 H16-H19 — 9.0×15.60 rektangel/lins, Ø2.1
    "H12": (-16.5, 30.8, 0), "H13": (-7.5, 30.8, 0), "H14": (-16.5, 15.2, 0), "H15": (-7.5, 15.2, 0),
    "H16": (7.5, 30.8, 0), "H17": (16.5, 30.8, 0), "H18": (7.5, 15.2, 0), "H19": (16.5, 15.2, 0),
    # konstantströms-sänka i centrum-fria zonen (kort LED_CATH→Q2 + gate-loop)
    "Q2": (8.5, 9, 90), "R2": (-2, 5, 0),                # DPAK pass-FET (höger) + 0R2 sense (källa→GND)
    "U2": (-9, 11, 0), "C7": (-9, 7.5, 0), "C6": (-9, 4.5, 0),  # op-amp + komp + avkoppl (vänsterkolumn)
    "R3": (-5, 11, 0), "R4": (-1, 11, 0), "R5": (3, 11, 0),  # delare 15k/1k + gate-R (toppraden)
    "C2": (18, 18, 0),                                   # bulk 100µF nära LED-anod/VBAT (topp-höger)
    # inmatningsskydd på HÖGERkanten (frigör vänsterkanten för P4 + J1)
    "F1": (24, 9, 90), "Q1": (24, 3, 0), "D1": (24, -3, 90), "R1": (24, -9, 90), "C1": (24, -15, 0),
    # batteri-in (JST-XH) längs NEDERKANTEN. OBS: flip_j1_back speglar kroppen topp-botten,
    # så för att kabelöppningen ska peka NEDÅT (mot nederkanten) EFTER flippen placeras den
    # rot180 (öppning uppåt FÖRE flip → nedåt EFTER). y=-25.3 ger ~2 mm marginal till kanten.
    # (trigger m.fl. fire-control-I/O ligger på separat kort mot P4 edge A — ej här.)
    "J2": (8, -25.3, 180),
    # J1 = 1x14 P4-kantkontakt på VÄNSTERKANTEN (P4 vänd så signalkanten edge B ligger ytterst).
    # P4-pin (make_p4_board-index) m @ optikkort-y = -31 + (m-1)*2.54. Edge B (ESP→USB):
    #   VSYS=P4-pin19 (y=+14.71) ... GPIO32=P4-pin6 (y=-18.31). Origo=J1-pin1 (VSYS), går nedåt.
    "J1": (-25.28, 5.14, 0),   # FLYTTAD -9.57mm i Y: J1 möter P4 edge B när standoff-hålen linjeras
    # kamerafäste H8-H11 (B0332 28×28 om lins (0,-6)); B4B-ZR-kontakt riktad +x (höger)
    "H8": (-14, 8, 0), "H9": (14, 8, 0), "H10": (-14, -20, 0), "H11": (14, -20, 0),
    # IMU + avkoppling vänster-centrum (under P4, NÄRA J1) → korta SPI-escapes till J1
    "U1": (-19, -3, 0), "C3": (-22, -7, 90), "C4": (-19, -8, 0), "C5": (-15, -1, 90),  # IMU tätt intill J1; C3 upp till matn.-sidan → fri nCS-escape ned-vänster
    # kort-monteringshål: alla x>-5.5 (ej under P4) — H1 topp-höger, H2 botten-höger,
    # H3 höger-kant (mellan kraftremsan och H2), H4 centrum-topp (mellan linserna)
    "H1": (24, 34, 0), "H2": (24, -34, 0), "H3": (24, -22, 0),
    "H4": (0, 28, 0),
    # 4 P4-standoff: synkade mot P4:ans hål, sammanfaller i stacken. RÖRS EJ (korrekta).
    "H5": (-25.15, -33.48, 0), "H6": (-6.85, -33.48, 0),
    "H7": (-6.85, 20.31, 0), "H20": (-25.15, 20.31, 0),
}

weapon_pos = {
    # topp: emittrar + pulsreservoar + Rset (caps ut i hörnen, fria från H4/H5)
    "D2": (-9, 22, 0),  "D3": (9, 22, 0),          # 940 nm emittrar (skottstråle)
    "C2": (-8, 15, 0), "R2": (0, 15, 90), "C1": (8, 15, 0),    # 100µF MLCC / Rset / 10µF
    # höger: driver längst ut (x≈19, fritt från H5/H7) + IMU i mittkolumnen (x≈10-14)
    "Q1": (19, 9, 0),   "R3": (19, 3, 90),         # N-FET + gate-R (far-right)
    "U1": (14, -3, 0),                             # IMU (mellan H5/H7, fri från lins)
    "C3": (14, -9, 0), "C4": (10, -8, 0), "C5": (10, 1, 0),  # IMU-avkoppling
    # vänster remsa: inmatningsskydd (x≈-18, fritt från H4/H6)
    "F1": (-18, 8, 90), "Q2": (-18, 1, 0), "D1": (-18, -6, 90), "R1": (-18, -12, 90),
    # kamerafäste (M2, 28×28 om lins (0,-4))
    "H4": (-14, 10, 0), "H5": (14, 10, 0), "H6": (-14, -18, 0), "H7": (14, -18, 0),
    # nederkant: kontakter + kort-monteringshål
    "J2": (-15, -27, 90), "J1": (-1, -27, 90), "H3": (18, -27, 0),
    "H1": (-18, 28, 0), "H2": (18, 28, 0),
}

# ---- fire-control-kort (71×21, STACKAS ovanpå P4, samma format) ----
# FC-frame = P4-frame (lång axel = x). J1 = FEMALE socket mot P4 edge A pin6..20 (15-pin)
# @ (x=-18.3..+17.25, y=+8.89) — samma fysiska läge som P4-stiften (rak stack).
# Stående JST (kabel upp) längs undervaktsiden; extra IMU + I²C-pullups i mittbandet;
# 4 monteringshål i linje med P4-standoffsen (-34.10/+20.07, ±9.125, Ø1.7) → genomgående stack.
# OBS: pinrader ±8.89 (DXF-exakt, spann 17.78=7×2.54) — INTE 9.28.
# OBS: koordinater är PRE-MIRROR (receiver_place.py-frame). Verkliga board-koords efter spegling:
#   board_x = 150 + x_pm,  board_y = 120 + y_pm
# Speglingen utförs separat (fc_add_ports_v2.py / fc_mirror.py) efter placering + flip.
firecontrol_pos = {
    "J1": (-18.31, 8.89, 90),                                  # socket mot edge A (pin6..20, 15-pin) — EXAKT på P4 J_A pad1
    "J2": (-25.92, -8.89, 90),                                 # edge-B kraft-tapp (3V3+GND), bortre långsida
    "J3": (-16, -6, 0), "J4": (-9, -6, 0), "J5": (-2, -6, 0), "J6": (5, -6, 0),  # switchar (botten), -1mm v. för J10-luckan
    "J7": (-27, 6, 0), "J8": (27, -6, 0),                      # J7 recoil (övre vänster), J8 NFC (höger om H4)
    "J9": (26.5, 7, 0),                                        # OLED I²C JST-PH 4-pin [GND/3V3/SCL/SDA] — nedre h. hörnet
    "J10": (12.2, -6, 0),                                      # lägesväljare JST-PH 3-pin [MODE_A/MODE_B/GND] — luckan J6→H4
    "U1": (8, 0.5, 0), "U2": (21, 0.5, 0),                     # 2× extra IMU (I²C 0x69/0x68)
    "C3": (4, 3.5, 0), "C4": (12, 3.5, 0),                     # U1-avkoppling
    "C5": (17, 3.5, 0), "C6": (25, 3.5, 0),                    # U2-avkoppling
    "R1": (-1, 4, 0), "R2": (-5, 4, 0),                        # I²C-pullups (SDA/SCL)
    "R3": (8, 3.5, 0), "R4": (21, 3.5, 0),                     # MODE_A/MODE_B pull-ups 4k7 (cap-radens luckor C3-C4 / C5-C6)
    "C1": (-9, 3.5, 0), "C2": (-13, 3.5, 0),                   # 3V3-rail/NFC-avkoppling
    "H1": (-34.10, 9.125, 0), "H2": (-34.10, -9.125, 0),
    "H3": (20.07, 9.125, 0), "H4": (20.07, -9.125, 0),
}
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

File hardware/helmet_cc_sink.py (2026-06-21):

#!/usr/bin/env python3
"""STRILAS — konvertera hjälm-mb:s konstellations-driver till FIRMWARE-TRIMBAR CC-sänka,
INKREMENTELLT (bevarar all 886-spårs routning — freerouting hänger på detta kort). Lägger
op-amp (U9) + sense (R14) + 3A-override (R15) + tak-delare (R16/R17) + RC (C23) i ett KOMPAKT
kluster intill Q1 (clear-pocket-scannat → korta länkar, ren trace_between), flyttar R4(gate)
dit, ändrar R4/R5-R7-värden, ompekar Q1.S→sense + R4.1→op-amp-OUT, och routar BARA klustret.
R5-R7 behåller 2512-footprint → ring-routningen rörs ej. Mönster = helmet_protection.py (2-fas).
  python3 hardware/helmet_cc_sink.py         # fas 1 (delar + nät + stub-borttagning + R4-flytt)
  python3 hardware/helmet_cc_sink.py route   # fas 2 (route klustret + verifiera + spara)
"""
import sys, math, pcbnew
sys.path.insert(0, "hardware")
from incr_route import Router

PCB = "hardware/helmet-mb.kicad_pcb"; NET = "hardware/helmet-mb.net"
FPDIR = "/usr/share/kicad/footprints"; OX, OY = 150.0, 120.0
MM = pcbnew.FromMM
def V(x, y): return pcbnew.VECTOR2I(MM(OX + x), MM(OY - y))
ALL_CU = [pcbnew.F_Cu, pcbnew.In1_Cu, pcbnew.In2_Cu, pcbnew.B_Cu]

NEW = {   # kompakt kluster, clear av F_Cu-koppar (scannat) — korta länkar (≤4,2 mm)
    "U9":  ("Package_TO_SOT_SMD", "SOT-23-5", -6.0, 23.5, 0),
    "R14": ("Resistor_SMD", "R_1206_3216Metric", -2.69, 24.21, 90),
    "R15": ("Resistor_SMD", "R_0805_2012Metric", -0.5, 25.12, 90),
    "R16": ("Resistor_SMD", "R_0805_2012Metric", -10.5, 20.2, 90),   # pin1 (LED_EN) på In1-spårets clear-punkt → direkt via
    "R17": ("Resistor_SMD", "R_0805_2012Metric", -13.15, 20.85, 0),
    "C23": ("Capacitor_SMD", "C_0805_2012Metric", -12.8, 23.0, 0),
}
R4MOVE = (-5.19, 20.85, 0)   # flytta gate-R R4 in i klustret (gamla läget 5,20 → gate-spåret över center)
NEWVAL = {"U9": "OPA171", "R14": "0R2", "R15": "0R1 DNP=1A/montera=3A", "R16": "15k", "R17": "1k", "C23": "100nF"}
VALUE_CHANGE = {"R4": "100R", "R5": "1R", "R6": "1R", "R7": "1R"}

# KIRURGISK nät-tilldelning (BARA paddar vars konnektivitet ändras — rör EJ codec/P4/ljud-nät).
# Gaten (Q1.1+R4.2) BEHÅLLER befintligt board-nät. IDRV_GATE = op-amp OUT → R4.1.
ASSIGN = {
    ("Q1", "2"): "IDRV_SENSE", ("R14", "1"): "IDRV_SENSE", ("R15", "2"): "IDRV_SENSE", ("U9", "4"): "IDRV_SENSE",
    ("U9", "3"): "IDRV_REF",   ("R16", "2"): "IDRV_REF",   ("R17", "1"): "IDRV_REF",   ("C23", "1"): "IDRV_REF",
    ("R4", "1"): "IDRV_GATE",  ("U9", "1"): "IDRV_GATE",
    ("U9", "2"): "GND", ("R14", "2"): "GND", ("R15", "1"): "GND", ("R17", "2"): "GND", ("C23", "2"): "GND",
    ("U9", "5"): "VBAT", ("R16", "1"): "LED_EN",
}


def main():
    b = pcbnew.LoadBoard(PCB)
    have = {f.GetReference() for f in b.GetFootprints()}
    for ref, (lib, fp, x, y, rot) in NEW.items():
        if ref in have:
            print(f"  {ref} finns redan"); continue
        f = pcbnew.FootprintLoad(f"{FPDIR}/{lib}.pretty", fp)
        f.SetReference(ref); f.SetValue(NEWVAL.get(ref, "")); f.SetPosition(V(x, y))
        if rot: f.SetOrientationDegrees(rot)
        b.Add(f); print(f"  + {ref} ({NEWVAL.get(ref,'')}) @({x},{y})")
    fps = {f.GetReference(): f for f in b.GetFootprints()}
    for ref, val in VALUE_CHANGE.items():
        fps[ref].SetValue(val)
    pad_of = {(f.GetReference(), pd.GetName()): pd for f in b.GetFootprints() for pd in f.Pads()}
    # pad-overlap-koll
    for nr in NEW:
        npads = [pad_of[k] for k in pad_of if k[0] == nr]
        for of in b.GetFootprints():
            if of.GetReference() in (nr,) or of.GetReference() not in {k[0] for k in pad_of}: continue
            opads = [pad_of[k] for k in pad_of if k[0] == of.GetReference()]
            if any(p1.GetEffectiveShape().Collide(p2.GetEffectiveShape(), int(0.15e6)) for p1 in npads for p2 in opads):
                print(f"  !! PAD-OVERLAP {nr} <-> {of.GetReference()}")
    def gn(nm):
        ni = b.FindNet(nm)
        if ni is None: ni = pcbnew.NETINFO_ITEM(b, nm); b.Add(ni)
        return ni
    changed = []
    for (ref, pin), newnet in ASSIGN.items():
        pd = pad_of[(ref, pin)]; old = pd.GetNetname()
        if old != newnet:
            changed.append((ref, pin, old, newnet)); pd.SetNet(gn(newnet))
    print(f"  re-synkade {len(changed)} pad-nät kirurgiskt")
    # riv gamla stubbar vid ändrade paddar (R4.1 LED_EN, Q1.2 GND) + R4.2 gate-spår (R4 flyttas)
    rem = 0
    def rip(pad, oldnet):
        nonlocal rem
        sh = pad.GetEffectiveShape(); pl = {L for L in ALL_CU if pad.IsOnLayer(L)}
        for t in list(b.GetTracks()):
            tl = set(ALL_CU) if t.Type() == pcbnew.PCB_VIA_T else {t.GetLayer()}
            if (pl & tl) and t.GetNetname() == oldnet and t.GetEffectiveShape().Collide(sh, int(0.2e6)):
                b.Remove(t); rem += 1
    for ref, pin, old, newnet in changed:
        if old: rip(pad_of[(ref, pin)], old)
    r4p2 = pad_of[("R4", "2")]; rip(r4p2, r4p2.GetNetname())
    fps["R4"].SetPosition(V(*R4MOVE[:2])); fps["R4"].SetOrientationDegrees(R4MOVE[2])
    print(f"  rev {rem} gamla stubbar; flyttade R4 → {R4MOVE[:2]}")
    pcbnew.SaveBoard(PCB, b)
    print("  fas 1 klar — kör 'route'")


def led_en_via(R, b):
    """R16.1 (F_Cu) → närmaste LED_EN-koppar på INNER-lager (In1/In2): ren F-stub + GENOMGÅENDE via
    (träffar inner-spåret; zon-omfyllning ger plan-clearance runt vian)."""
    led = R._net("LED_EN")
    r16 = None
    for pd in R.fps["R16"].Pads():
        if pd.GetName() == "1": p = pd.GetPosition(); r16 = (p.x/1e6-OX, OY-p.y/1e6)
    inner = {pcbnew.In1_Cu, pcbnew.In2_Cu}; cand = []
    for t in b.GetTracks():
        if t.GetNetname() != "LED_EN" or t.Type() == pcbnew.PCB_VIA_T or t.GetLayer() not in inner: continue
        s = (t.GetStart().x/1e6-OX, OY-t.GetStart().y/1e6); e = (t.GetEnd().x/1e6-OX, OY-t.GetEnd().y/1e6)
        for f in [i/10.0 for i in range(0, 11)]:        # sampla LÄNGS spåret (var pkt = möjlig via)
            cand.append((s[0]+(e[0]-s[0])*f, s[1]+(e[1]-s[1])*f))
    cand.sort(key=lambda q: math.hypot(q[0]-r16[0], q[1]-r16[1]))
    obs = R._obstacles("LED_EN")
    for tgt in cand:
        if math.hypot(tgt[0]-r16[0], tgt[1]-r16[1]) < 0.4: continue
        if not R._via_clear(tgt, obs): continue
        segs = None
        if R._seg_clear(r16, tgt, pcbnew.F_Cu, obs):
            segs = [(r16, tgt)]
        else:
            for cor in ((tgt[0], r16[1]), (r16[0], tgt[1])):
                if R._seg_clear(r16, cor, pcbnew.F_Cu, obs) and R._seg_clear(cor, tgt, pcbnew.F_Cu, obs):
                    segs = [(r16, cor), (cor, tgt)]; break
        if not segs: continue
        for a, c in segs: R._add_track(a, c, pcbnew.F_Cu, led)
        v = pcbnew.PCB_VIA(b); v.SetPosition(V(*tgt)); v.SetDrill(MM(0.3)); v.SetWidth(MM(0.6))
        v.SetNet(led); v.SetViaType(pcbnew.VIATYPE_THROUGH); b.Add(v)
        return f"via@{tuple(round(x,1) for x in tgt)}"
    return "ingen reachable via-punkt"
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

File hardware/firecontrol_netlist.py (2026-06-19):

#!/usr/bin/env python3
"""STRILAS — FIRE-CONTROL-KORT (vapen): kretsdefinition i kod (SKiDL → KiCad-netlista).
Genererar 'hardware/firecontrol.net'.

STACKAS rakt ovanpå P4 (samma 71×21-format) och tar P4:ans SIGNALKANT edge A via en
FEMALE socket (P4 bär male-stiften). Fan-out till greppets I/O via STÅENDE JST-PH
(kabel rakt upp). Optikmodulen (edge B, under) förblir ren optik.

ORIENTERING: USB-upp (verifierad). FC-frame = P4-frame (lång axel = x), FC ligger rakt
ovanför P4 i samma orientering → socket-paddar i samma (x,y) som P4 edge-A-stiften.

EDGE A, pin n castellation: P4-x = -31 + (n-1)*2.54, y = +9.28. Använda pin 6..20:
  6 GPIO29  7 GPIO28  8 GND  9 GPIO50  10 GPIO49  11 GPIO5  12 GPIO4
  13 GND  14 GPIO3  15 GPIO2  16 GPIO8(SCL)  17 GPIO7(SDA)
  18 GND  19 GPIO24(MODE_A)  20 GPIO25(MODE_B)
Edge A saknar kraftskena → 3V3 matas via edge-B kraft-tapp (J2) från P4 edge B.
GPIO50 (tidigare reserv) driver IMU2:ns INT (I²C, delar NFC-bussen).
GPIO24/25 driver 4-läges rotarykopplare (MODE_A/MODE_B, binärt kodad).
"""
from skidl import Part, Pin, Net, generate_netlist, SKIDL, TEMPLATE


def mk(name, ref, pins, fp, value=""):
    p = Part(tool=SKIDL, name=name, ref_prefix=ref, dest=TEMPLATE)
    p.add_pins(*[Pin(num=str(n), name=str(nm)) for n, nm in pins])
    p.footprint = fp
    if value:
        p.value = value
    return p


# ---------- parttyper ----------
# FEMALE socket mot P4 edge A (15 stift, pos 6..20). P4 bär male-stiften.
P4A = mk("P4_EDGE_A", "J", [(i, i) for i in range(1, 16)],
         "Connector_PinSocket_2.54mm:PinSocket_1x15_P2.54mm_Vertical", "P4-socket (edge A)")
# FEMALE socket mot P4 EDGE B (kraft-tapp): FC:s bortre långsida sitter över edge B,
# tar 3V3+GND DIREKT därifrån (edge B pin 3=GND, 4=EN(nc), 5=3V3). Ingen kabel/bygel —
# edge B blir en genomgående stackande stiftlist: optik under, FC ovan.
PWRB = mk("PWR_EDGEB", "J", [(1, "GND"), (2, "ENnc"), (3, "P3V3")],
          "Connector_PinSocket_2.54mm:PinSocket_1x03_P2.54mm_Vertical", "edge-B kraft-tapp 3V3+GND")
SW2 = lambda nm: mk(nm, "J", [(1, "SIG"), (2, "GND")],
                    "Connector_JST:JST_PH_B2B-PH-K_1x02_P2.00mm_Vertical", nm)
REC = mk("RECOIL_CTRL", "J", [(1, "PWM"), (2, "FAULT"), (3, "GND")],
         "Connector_JST:JST_PH_B3B-PH-K_1x03_P2.00mm_Vertical", "recoil-styrning")
NFC = mk("NFC_PN532", "J", [(1, "SDA"), (2, "SCL"), (3, "3V3"), (4, "GND")],
         "Connector_JST:JST_PH_B4B-PH-K_1x04_P2.00mm_Vertical", "NFC PN532 (I²C)")
OLED = mk("OLED_I2C", "J", [(1, "GND"), (2, "3V3"), (3, "SCL"), (4, "SDA")],
          "Connector_JST:JST_PH_B4B-PH-K_1x04_P2.00mm_Vertical", "OLED SSD1306 (I²C, GND/3V3/SCL/SDA)")
MODE = mk("MODE_SEL", "J", [(1, "MODE_A"), (2, "MODE_B"), (3, "GND")],
          "Connector_JST:JST_PH_B3B-PH-K_1x03_P2.00mm_Vertical", "4-läges rotarykopplare (MODE_A/MODE_B/GND)")
# EXTRA IMU — TDK IIM-42653 (LGA-14), samma som optiken men I²C. Pin-nr per DS-000529:
#   8=VDD 5=VDDIO 6=GND 7=RESV(→GND) 13=SCLK(SCL) 14=SDI(SDA) 1=SDO(AD0) 12=CS(→VDDIO=I²C) 4=INT1
# (drop-in: 8 signalstift identiska med 426xx; AUX1 2/3/10/11 = NC. I²C 0x68/0x69 via AD0.)
IMU = mk("ICM-42688-P", "U", [(i, i) for i in range(1, 15)],
         "strilas:InvenSense_LGA-14_2.5x3mm_ICM-456xx", "ICM-42688-P")
RES_T = mk("R", "R", [(1, "~"), (2, "~")], "Resistor_SMD:R_0805_2012Metric")
CAP_T = mk("C", "C", [(1, "~"), (2, "~")], "Capacitor_SMD:C_0402_1005Metric")
RES = lambda v: RES_T(value=v)
CAP = lambda v: CAP_T(value=v)
MH = lambda n: mk(f"MH{n}", "H", [(1, "1")], "strilas:MountingHole_1.7mm", "Ø1.7_P4_standoff")

# ---------- nät ----------
GND, P3V3 = Net("GND"), Net("+3V3")
TRIG, RACK, MAG_REL, MAGWELL = Net("TRIG"), Net("RACK"), Net("MAG_REL"), Net("MAGWELL")
REC_PWM, REC_FLT = Net("RECOIL_PWM"), Net("RECOIL_FAULT")
SDA, SCL = Net("NFC_SDA"), Net("NFC_SCL")
IMU2_INT, IMU3_INT = Net("IMU2_INT"), Net("IMU3_INT")
MODE_A, MODE_B = Net("MODE_A"), Net("MODE_B")
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

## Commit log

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2026-06-15 Autoroute weapon module in KiCad+Freerouting -> routed PCB + Gerbers
    Ran the full EDA chain autonomously in-container (KiCad 7 + Freerouting via xvfb):
    netlist -> placed board (pcbnew) -> Specctra DSN -> autoroute -> SES applied back as
    tracks/vias + GND planes (In1+B.Cu) -> Gerbers/drill. Deliverables: weapon-module.kicad_pcb
    (4-layer routed), weapon-module-gerbers.zip (upload to fab), routed render PNG, and the
    place/ses_import scripts. 80 track segments + 3 vias; all power + most signals routed.
    6 connections unrouted = SPI escape to the 0.5mm-pitch IMU placeholder, which resolves
    when the real ICM-45686 footprint replaces it (normal fanout step). weapon-module-routed.md
    documents status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
    [weapon-module.kicad_pcb]
2026-06-15 Kit camera is OV5647 (RPi Cam Model B), not OV5640 - and needs NoIR
    User confirmed the exact kit camera: Raspberry Pi Camera Model B = OV5647 (5MP
    1/4in, M12 6mm/F2.0/60.6deg diag), 'IR night vision: nonsupport'. Two design
    impacts captured across docs/firmware/verification:
    - Sensor renamed OV5640 -> OV5647 everywhere (both are P4-supported; OV5647 has
    its own ISP). Firmware FOV updated 18 -> 33.4deg (stock 6mm lens, swappable M12).
    - CRITICAL: the stock camera has an IR-cut filter -> it does NOT see 860nm. The
    precision path needs to see the 860nm constellation, so the camera MUST be NoIR
    (filter removed or RPi NoIR camera). Flagged in hardware README + design-resolution.
    - Re-ran ph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
    [config.py]
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2026-06-15 Fix vest-patch routing (was wiped by place-rebuild in batch loop)
    The background route loop re-ran receiver_place.py per iteration, so the helmet
    iteration re-placed (wiped) the vest board's tracks after its gerbers were made
    -> committed vest .kicad_pcb had 0 tracks while its zip was routed (inconsistent).
    Re-routed vest-patch cleanly: 113 tracks + 1 via, 2 unrouted; regenerated gerbers
    + render so board and Gerbers match.
    [vest-patch.kicad_pcb]
2026-06-15 Weapon PCB: complete + DRC-clean (real footprints, full route, planes, gerbers)
    Root-cause fix: the 2 emitter LEDs and the IMU were silently dropped from the
    board because their footprint names did not exist in the KiCad libs. Built
    datasheet-traced custom footprints in hardware/strilas.pretty:
    - IR_Emitter_Vishay_VSMA1094750 (940nm, Vishay DocNo 80365 land)
    - InvenSense_LGA-14_2.5x3mm_ICM-456xx (pinout per TDK AN-000483 Fig.2)
    Shot emitter corrected to Vishay VSMA1094750X02 (genuine 940nm, 945nm peak,
    1.5A DC/5A pulse) — resolves the OSLON "SFH 4715AS 940nm" mislabel (OSLON AS =
    850/860nm). IMU SPI wired to verified pins (SCLK13/SDI14/SDO1/CS12/INT1 4),
    RESV pins NC.
    Routing pipeline (a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
    [weapon-module.kicad_pcb]
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2026-06-15 Add camera mount (H4-H7, B0332 28x28) + resolve P4 connection (J1 cable)
    - 4x M2 camera-mount holes matching Arducam B0332 (38x38, 28x28 pattern) around
    the lens axis; camera bolts behind board, lens through Ø16. Repositioned parts
    to clear the holes; C2 220uF electrolytic -> 100uF 1210 MLCC (lower ESR, fits).
    - Re-routed: 24 comps, 176 tracks + 25 vias, 0 unrouted, 0 clearance viol @0.2mm.
    - P4 (ESP32-P4-WIFI6 = 71x21mm Pico-style) cannot stack behind the rear camera;
    J1 (2x6) carries VSYS/3V3/GND/IR/SPI/INT to P4 GPIO via short cable.
    - Regenerated gerbers, STEP (3.0MB, all bodies), renders + mount-analysis.
    - Docs updated (fab BOM 24, routed status, camera/P4 mounting).
    https://cl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
    [weapon-module.kicad_pcb, weapon-module.step]
2026-06-15 Redesign as 52x80 stacked box: 2x Ø20 collimator mounts + P4 stacked behind
    - Board grown 42x62 -> 52x80mm. Front: 2x Ø20 IR-collimators (H8-H13, 3 holder
    legs/lens) over emitters + Ø16 camera + B0332 mount (H4-H7).
    - P4 (ESP32-P4-WIFI6, 71x21) stacked BEHIND on 4 standoffs (H14-H17); connected
    via J1(2x6)+short flex to P4 right edge row (all signals VSYS/3V3/GND/GPIO20-32
    there, per Waveshare pinout). Flex chosen: camera is 13mm deep -> rigid B2B impractical.
    - Added trigger-in (J3) + battery (J2) connectors for external cables via barrel.
    - C2 220uF -> 100uF 1210 MLCC. 35 comps, 166 tracks + 22 vias, 0 unrouted,
    0 clearance viol @0.2mm. Regenerated gerbers, STEP (3.1MB), renders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
    [weapon-module.kicad_pcb, weapon-module.step]
2026-06-15 WIP: OSLON SFH4725S + Carclo 10003 + rigid 1x13 P4 edge header, 54x68
    Parts LOCKED: OSLON Black SFH 4725S (940nm) + Carclo 10003 Ø20 narrow TIR (both 3D).
    Rigid 1x13 P4 edge connector (no flex); P4 standoffs dropped; board minimized 54x68.
    KNOWN ISSUE (being fixed next): 2 emitter-anode nets (N$2, LED_MID) not yet cleanly
    routed - OSLON anodes boxed by lens cutout+camera holes+legs. NOT fab-ready.
    Verified clean 52x80 board remains at commit 10a1535.
    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
    [weapon-module.kicad_pcb]
2026-06-15 LOCKED: weapon module 54x68 - OSLON SFH4725S + Carclo 10003 + rigid P4 edge, 0 errors
    Root cause of the 2 stubborn unrouted emitter nets found+fixed: OSLON footprint pads
    were only 0.2mm apart (< clearance), blocking the autorouter from escaping D2. Widened
    anode/cathode gap to 0.45mm -> freerouting routes 100% natively (real optimization pass).
    Final locked board:
    - 2x OSRAM OSLON Black SFH 4725S (940nm, 980mW/A) + 2x Carclo 10003 Ø20 narrow TIR
    (officially SFH4725S-matched, STEP+holder available); 2 holder legs/lens.
    - Rigid 1x13 P4 edge connector (no flex) to ESP32-P4-WIFI6 right row; P4 stands off behind.
    - Arducam B0332 (OV9281) behind Ø16, 16mm lens; camera mount M2 28x28; ICM-456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
    [weapon-module.kicad_pcb, weapon-module.step]
2026-06-15 Fix 3D-review issues: symmetric collimator legs + camera standoffs (3D)
    - Collimator legs: 2 symmetric per lens (D2 H8/H9, D3 H10/H11). Earlier sed missed
    the 54x68 block -> D2 had 3 legs + a stray at (-4.6,18.2), D3 only 1. Fixed.
    - Camera mount H4-H7 (M2, 28x28 about lens): added Würth WA-SMSI 10mm standoff 3D
    models -> visible in STEP (B0332 bolts behind on these).
    - P4 edge header J1 kept vertical THT (KiCad flip-to-back segfaults headless;
    populate as back/right-angle in GUI - routing identical).
    - Re-routed: 29 comps, 162 tracks + 21 vias, 0 unrouted, 0 clearance viol @0.2mm.
    Regenerated gerbers, STEP (3.3MB, with standoffs), render.
    https://claude.ai/code/session_01EQ2JhMHoL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
    [weapon-module.kicad_pcb, weapon-module.step]
2026-06-15 Fix 3D-review round 2: 3 legs/lens, clear lens area, P4 along 68mm edge
    - 3 collimator legs per lens (Carclo 10003 holder): D2 H8/H9/H10, D3 H11/H12/H13.
    - Nothing under the Ø20 lens circles: Rset moved to left edge, NFET+gate-R into the
    center gap between lenses -> collimators can actually mount.
    - P4 edge connector (J1) moved to the RIGHT 68mm edge so the P4's 71mm length aligns
    with the board's 68mm (3mm overhang vs 17mm on the 54mm edge). User's point.
    - Camera standoffs (Würth M2 10mm 3D) on H4-H7.
    - 31 comps, 153 tracks + 24 vias, 0 unrouted, 0 clearance viol @0.2mm. Gerbers+STEP+render.
    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
    [weapon-module.kicad_pcb, weapon-module.step]
2026-06-15 Collimator holder: exact Carclo 60475 4-leg pattern (per user's holder drawing)
    User supplied the Carclo 60475 holder drawing. Corrected from my wrong assumption:
    - 4 legs PER LENS (not 3), in a 9.5 x 16.45mm rectangle, Ø3.2mm (R1.6) holes,
    R2.4 leg-clearance, LED centered. 8 holes total (H8-H15), MountingHole_3.2mm_M3.
    - Optic = Carclo 10003 (20mm narrow, OSLON SFH4725S); holder = Carclo 4-leg 0.8mm-foot.
    - Board grown to 54x70 to fit the 16.45mm leg rectangle above the emitters.
    - Nothing under the Ø20 lenses (Rset on left edge, NFET+gateR in center gap),
    camera standoffs (Würth M2), P4 edge connector on the 68/70mm long edge.
    - 33 comps, 160 tracks + 24 vias, 0 unrouted, 0 clearanc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
    [weapon-module.kicad_pcb, weapon-module.step]
2026-06-15 Collimator holder corrected: Carclo 10734 4-leg (drawing 60575, 20mm) per user
    User supplied the correct drawing 60575 '20mm DIA OPTIC 4 LEG HOLDER'. The 10734
    (in that table, DIM A 10.8 / black / 0.8mm foot) IS a 4-leg holder (LEDsupply's
    'adhesive' note was misleading). Corrected pattern (was using 26.5mm 60475):
    - 4 PCB holes Ø2.1mm per lens in a 9.0 x 15.60mm rectangle, Ø3.5 leg-clearance,
    LED centered. 8 holes (H8-H15), MountingHole_2.1mm.
    - Optic Carclo 10003 (20mm narrow) + holder 10734 (4-leg). OSLON SFH4725S emitter.
    - 33 comps, 166 tracks + 25 vias, 0 unrouted, 0 clearance viol @0.2mm. Gerbers+STEP+render.
    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
    [weapon-module.kicad_pcb, weapon-module.step]
2026-06-15 P4 header (J1) onto BACK side + remove camera standoffs
    - J1 (P4 edge connector) now on B.Cu (shooter side): route with J1 on front
    (freerouting can't DSN a back-side fp), then flip left-right post-route -> single
    -column THT pads stay in place -> 0 unrouted preserved. Fixes 'header on wrong side'.
    - Removed Würth standoff 3D from camera holes H4-H7 (now plain M2 holes; user fits own).
    - 33 comps, 159 tracks + 24 vias, 0 unrouted, 0 clearance viol @0.2mm. Gerbers+STEP+render.
    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
    [weapon-module.kicad_pcb, weapon-module.step]
2026-06-15 All connectors (J1/J2/J3) on BACK side
    J2 (battery) + J3 (trigger) also flipped to B.Cu like J1 (external cables come from
    the body/back). Per-connector flip axis to keep pads in place: J1 (vertical pads)
    left-right, J2/J3 (rot90, horizontal pads) top-bottom -> 0 unrouted preserved.
    33 comps, 173 tracks + 26 vias, 0 unrouted, 0 clearance viol @0.2mm. Gerbers+STEP.
    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
    [weapon-module.kicad_pcb, weapon-module.step]
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2026-06-15 Add center mount hole + 3 P4 standoff holes (15mm); board 54x74
    Per user: 15mm P4 standoffs clear the 13mm-deep camera; sync 3 of P4's 4 holes to the
    optic board + a center board-mount hole between the lenses. H4=center(0,28),
    H5/H6/H7=3 P4 standoffs (12.5,32.5)/(-2.5,-32.5)/(12.5,-32.5) matching P4 hole pattern.
    Board grown to 54x74 so the P4's 65mm hole span fits with margin. Bottom cluster moved
    up to y-26 to clear the P4 standoffs. Connectors J1/J2/J3 on back. 37 comps, 170 tracks
    + 25 vias, 0 unrouted, 0 clearance viol @0.2mm. Gerbers+STEP.
    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
    [weapon-module.kicad_pcb, weapon-module.step]
2026-06-15 P4 board model: accurate Waveshare geometry from dimension drawing
    No STEP exists for the ESP32-P4-WIFI6, so geometry is measured from
    Waveshare's dimension image (verified against its callouts):
    - 71.05 x 21.00 mm, 2x 1x20 castellated rows, pin-1 @ 4.52mm, pitch 2.54
    - 4 mounting holes: left pair (-34.06, +-9.15) at USB corner; right pair
    (+19.73, +-9.15) at the ESP-module boundary (18.27mm = module zone)
    - pin rows / holes at y=+-9.15..9.28 from board center
    Adds reproducible build_weapon.sh (full EDA chain + clearance/connectivity
    self-check gate) and a P4 mounting analysis showing the P4 hugging the
    LEFT edge (camera cable connector sits on the back-right, so P4 must
    clear it) with 3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
    [p4-board.kicad_pcb, p4-board.step]
2026-06-15 Weapon board: P4 to left edge per Fusion model (placement, pre-route)
    Per user's assembly images, the camera's B4B-ZR (USB cable) connector
    protrudes on the back-centre, so the P4 must hug the LEFT edge to clear
    it. New placement:
    - P4 footprint left (centre x=-16), J1 edge header moved to left edge
    - camera oriented with B4B-ZR facing right (clear of P4)
    - power/protection strip relocated to the right edge; Rset(R2)+bulk(C2)
    kept near the emitters for a short 56 kHz pulse loop
    - 3 synced P4 standoffs H5(-25.15,-34.06) H6(-6.85,-34.06) H7(-6.85,19.73)
    + centre board hole H4(0,28)
    Adds render_weapon_placement.py + proposal figure for review. Verified:
    no off-board pads, all hole clearanc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
    [receiver_place.py]
2026-06-15 Weapon board: route P4-left layout fully clean (0 unrouted, 0 clearance)
    Routed the P4-left placement end to end:
    - IMU + decoupling moved next to J1 (left-centre, under P4) so all 5 SPI
    escapes are short — this resolved the MISO routing bottleneck that
    Freerouting hit with the IMU at the bottom.
    - power/protection strip on the right edge; Rset+bulk kept by the emitters.
    - connectors J1/J2/J3 flipped to back; 4-layer copper pours
    (In1=GND, In2=VBAT, B=GND, F=GND-fill).
    - Freerouting routes every signal net (verified 0 signal-unrouted,
    0 clearance @0.2mm). Gerbers/STEP/render regenerated.
    build_weapon.sh now retries Freerouting until all signal nets route
    (drops the obsolete emitte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
    [weapon-module.kicad_pcb, weapon-module.step]
2026-06-15 Fix P4 board header placement: pin rows were bunched off-centre
    The PinHeader_1x20 footprint origin is pin-1 (not the row centre), so
    placing it at the computed centre ran each row from x=-6.9 to +41.4
    (off the right edge) instead of spanning the pin field. Place the
    origin at pin-1 (x=-31.0) so both rows run pin1@4.52mm → pin20@+17.25,
    flush along the two long edges. Regenerated p4-board.step.
    [p4-board.kicad_pcb, p4-board.step]
2026-06-15 Weapon board: align J1 to P4 pin grid + add 4th P4 standoff
    Two assembly-correctness fixes from the Fusion review:
    - J1's 13 pins were on an arbitrary y (off the P4 grid by ~1.9mm) so the
    header didn't mate. Snap J1 pin-1 onto the P4 grid (y=-31+k*2.54);
    its 13 pins now land exactly on P4 edge pins k4..k16 at x=-25.28.
    - Add the 4th P4 standoff (H20 @ -25.15,+19.73). The power strip moved to
    the right freed that spot, so all 4 P4 holes are now synced (was 3).
    HP4 instantiated last in the netlist -> ref H20, no ref reshuffle.
    Re-routed clean (0 signal-unrouted, 0 clearance @0.2mm); connectors on
    back; Gerbers/STEP/renders regenerated.
    [weapon-module.kicad_pcb, weapon-module.step]
2026-06-15 J1: map every pin to the OFFICIAL ESP32-P4-WIFI6 pinout (no guessing)
    Pulled the official Waveshare schematic+silk. The real signal edge (edge B,
    ESP->USB) is: VBUS,VSYS,GND,EN,3V3,GPIO20,GPIO21,GND,GPIO22,GPIO23,RUN,
    GPIO26,GND,GPIO27,GPIO32,... The previous J1 (1x13) used an invented order
    (omitted EN & RUN, wrong GND slots) - it would have mismatched every pin
    below 3V3.
    J1 is now 1x14 spanning edge-B pos2..15 (VSYS..GPIO32), each pin matched to
    the real P4 function and verified to land on the P4 pin grid:
    VSYS->VBAT, GND, EN->NC, 3V3, GPIO20->IR_MOD, GPIO21->TRIG, GND,
    GPIO22->SCK, GPIO23->MOSI, RUN->NC, GPIO26->MISO, GND, GPIO27->nCS,
    GPIO32->IMU_INT. (EN & RUN left NC - P4 has p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
    [weapon-module.kicad_pcb, weapon-module.step]
2026-06-15 J2/J3: pin headers -> JST cable connectors (battery XH, trigger PH)
    Both 2-pin connectors carry cables through the barrel, so they should be
    latching JST, not bare headers:
    - J2 battery (2S, ~1.3A pulse peak) -> JST-XH 2.50mm, horizontal
    - J3 trigger (signal) -> JST-PH 2.00mm, horizontal
    Different bodies = cables can't be swapped. Placed along the bottom edge,
    cable opening facing down (toward the barrel); H3 mount moved to the right
    edge to make room. Re-routed clean (0 unrouted, 0 clearance @0.2mm);
    Gerbers/STEP/renders regenerated.
    [weapon-module.kicad_pcb, weapon-module.step]
2026-06-15 Optikmodul: flytta trigger till separat fire-control-kort
    Triggern (rack/mag-release/recoil/NFC) hör till vapnets fire-control-I/O,
    som ligger på P4:ans edge A — inte på den pip-monterade optikmodulen
    (edge B: ström + IR + IMU-SPI). J1 var dessutom full; triggern la beslag
    på den sista dugliga GPIO:n.
    - Tar bort J3 (trigger-JST) från optikmodulen.
    - Frigör J1[6]=GPIO21 (NC, reserv-hook).
    - Recoil-KÄNNING sker via IMU:n ombord; recoil-EFFEKT + magasin-NFC
    ligger off-board enligt arkitekturen (Del 4/7/8).
    Re-routat rent (0 oroutade, 0 clearance @0.2mm); 37 komponenter, 16 nät.
    [weapon-module.kicad_pcb, weapon-module.step]
2026-06-15 Nytt fire-control-kort (matar P4 edge A stelt)
    Separat 50x42 breakout som fanar ut vapnets fire-control-I/O till greppet,
    så optikmodulen (edge B) förblir ren optik. Edge-A-pinouten verifierad mot
    Waveshares officiella ESP32-P4-WIFI6-diagram (Pico-format):
    - J1 = stel 1x12 mot edge A pos 6-17 (GPIO29..GPIO7).
    - Brytare (trigger/rack/mag-release/magwell) på interna pull-ups → JST-PH.
    - NFC PN532 på default-I²C (SCL/GPIO8, SDA/GPIO7) + 4k7-pullups, 3V3-mata
    via egen kontakt (edge A saknar kraftskena).
    - Recoil-styrning (PWM-ut + FAULT-in) → separat recoil-effektkort vid
    magasinet; recoil-känning via IMU på optikmodulen.
    Routat rent: 0 oroutade (inkl GND-plan), 0 clearance @0.2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
    [firecontrol.kicad_pcb, firecontrol.step]
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2026-06-15 Fixa batteri-JST: kabelöppning pekade in i kortet efter back-flip
    flip_j1_back speglar kontaktkroppen topp-botten, vilket vände J2:s
    kabelöppning från nederkanten till INÅT kortet (kabeln hade fått dras
    tvärs över PCB:n). Placerar nu J2 rot180 (öppning uppåt före flip →
    nedåt efter) vid y=-25.3 → öppningen pekar mot nederkanten med ~2 mm
    marginal, hela kroppen på kortet, inga paddar utanför kant.
    Re-routat rent (0 oroutade, 0 clearance @0.2mm).
    [weapon-module.kicad_pcb, weapon-module.step]
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2026-06-15 FC-kort ombyggt: stackas på P4 (71×21), female socket, stående JST, extra IMU
    - Ny form 71×21 = P4-format, stackas rakt ovanpå och möter edge A via FEMALE
    socket (P4 bär male-stiften). Mate-overlay verifierad: 0 felmatchningar.
    - Stående JST-PH (B*B-PH-K Vertical) → kabel rakt upp (löser kanthänget).
    - Extra IMU (TDK ICM-45686) på I²C, delar NFC-bussen (adr 0x69), INT på det
    tidigare reservstiftet GPIO50.
    - 4 monteringshål i linje med P4-standoffsen → genomgående pelarstack
    optik→P4→FC.
    - Routat rent (0 oroutade inkl GND-plan, 0 clearance @0.2mm).
    [firecontrol.kicad_pcb, firecontrol.step]
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2026-06-15 Fixa stift-/socket-sidor för sandwich-stacken
    P4: edge B-stiften (→ optik under) flippade till UNDERSIDAN, edge A (→ FC ovan)
    kvar uppåt, kamera-USB nedåt. Tidigare pekade alla samma håll (fel för sandwich).
    FC: P4-socketen (J1) flippad till UNDERSIDAN (vänder nedåt mot P4 edge A-stiften).
    Genomgående paddar → mate fortf. 0 felmatchningar, routat rent (0/0).
    [firecontrol.kicad_pcb, firecontrol.step, p4-board.kicad_pcb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]
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2026-06-15 FC: kabelfri 3V3 via edge-B kraft-tapp (J2 → P4 edge B 3/4/5)
    Per användarens idé: FC:s bortre långsida sitter över edge B, så J2 (1×3 socket)
    tar 3V3+GND DIREKT från edge B (pin3=GND, 4=EN nc, 5=3V3). Ingen bygel, ingen
    kabel — edge B blir genomgående stackande stiftlist (optik under, FC ovan).
    - J2 byter från JST-pigtail → PinSocket 1×3 vid edge-B-läget; flippad till baksidan.
    - JST-fan-out omplacerad (J7 recoil → övre kant) för att rymma tappen + klara H4-hål.
    - firecontrol_flip flippar nu J1+J2; routat rent (0/0 inkl GND).
    - system_sim: FC matas via edge B-tappen (ej tråd) → 0 typkrock, 0 utan ström, 0 dingel.
    Verifierat separat: edge B↔optik J1 matchar alla 1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
    [firecontrol-stack.step, firecontrol.kicad_pcb, firecontrol.step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]
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2026-06-15 Fixa stackad montering: spegla optik-J1 → korrekt koppling + P4 inom kontur
    Korten monteras som en parallell stapel (optik lins-ut, P4+FC bakom, inom
    optikens kontur, 12 mm) — inte kant-mot-kant. För en stackad kort-mot-kort-
    kontakt (ansikte-mot-ansikte) ska pinouten speglas: optikens J1 nät-ordning
    vänd (pad k = forna 15-k). FC behövde ej speglas (parallell, native).
    Optiken omroutad rent (0/0). system_sim uppdaterad (speglad korrespondens)
    → 0 typkrock, 0 utan ström, 0 dinglar. build_assembly.py bygger inom-kontur-
    posen (P4 x123-145, lins utåt, kontakter 0.000mm) → strilas-assembly.step.
    [weapon-module.kicad_pcb, weapon-module.step]
2026-06-15 Fixa optik-header: flytta J1 till mate-läget (hål/kort orörda)
    Användarens iakttagelse korrekt: hålen och korten linjerar perfekt; bara
    optikens J1-header satt fel. Hålmönstret är en symmetrisk rektangel → den
    lins-fria, fysiskt korrekta korrespondensen ger J1 vid (-25.28, 5.14), inte
    original (14.71). Flyttade ENDAST J1 (standoff-hål orörda). Verifierat mot
    hål-linjeringen: J1↔edge B 0.005mm, 0 nät-fel; system_sim 0/0/0.
    IMU (U1) flyttad tätt intill J1 för routbarhet (följd av header-flytten);
    optik omroutad ren 0/0.
    [weapon-module.kicad_pcb, weapon-module.step]
2026-06-15 Optik: fixa Q2/H18-överlapp + planär IMU→J1-routning (0 fel)
    Q2/R3 (rev-pol NFET-driver + gate-R) flyttade vänster så de inte längre
    överlappar D3:s Carclo-linsben H18 (kurva-överlapp var 0.54×0.46 mm).
    Resultat: 0 courtyard-överlapp på kortet.
    Den flytten störde freerouting (DSN-hash) så IMU↔J1 inte routade rent
    (nCS/IMU_INT byter Y-ordning IMU↔J1 → en tvingad korsning som kräver via,
    som autoroutern bara löste stokastiskt). Löst DETERMINISTISKT:
    - C3 (IMU-avkoppling) flyttad upp till matningssidan → fri nCS-escape.
    - De 5 IMU/SPI-näten permuterade bland J1-stift {1,2,4,6,7} = P4-GPIO
    {32,27,26,23,22} (alla generiska GPIO; SPI via P4:ans GPIO-matris).
    Korsning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
    [weapon-module.kicad_pcb, weapon-module.step]
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2026-06-16 Minska ledtid: R2→2× 6R8 1W parallellt + in-stock-byten (C2/C5/J1/F1)
    Mål: bort med specialdelar med lång ledtid hos NextPCB.
    - R2 (Rset, eye-safety strömtak) 3R3 2W 2512 (specialeffekt, 7-18 dgr) →
    2× 6R8 1W 2512 PARALLELLT (R2 + nytt R4 @ rel(19,23)) = 3.4Ω, 2W tot.
    1W-2512 = vanlig in-stock-typ. Eye-safety bevarad (≈samma R, ≥2W).
    Netlist: Rset2 skapas sist → ref R4 (R3=gate-R behåller numret).
    Optik omplacerad + omdragen: 0 överlapp · 0 oroutade · 0 clearance · 0 oconn.
    - C2 100µF 25V 1210 (pending) → 100µF 16V (16V>8.4V 2S = ok marginal, vanligare).
    - C5 1µF 0805 → high-runner basic. F1 PTC → in-stock-typ (likvärdig OK).
    - J1/J2/kraft-tapp-socklar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
    [BOM.csv, firecontrol-bom.xls, firecontrol-stack.step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]
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2026-06-16 Prototyp 1: väst-patch fab-klar (J1-bugg fixad) + NextPCB-paket
    - FIX: J1 hängde ~5mm utanför kortkanten (otillverkbart) → flyttad in (vest_pos -17→-10).
    - Väst-patch färdigroutad (route_vest.py: alla nät inkl GND som spår, J1 on-board →
    freerouting lyckas; 0 oroutade·0 clearance·0 oconnected). Gerbers+STEP.
    - NextPCB-paket: vest-patch-bom.xls (10 rader/18 komp: 3×TSOP4856·2×860nm·3×BAT54·
    Q1·R/C·J1) + centroid. 860nm-LED flaggad (matcha kamerans bandpass).
    - PROTOTYP-1.md: beställ 5 optik + 5 väst-patch, bringup-mätpunkter.
    - build_vest.sh/route_vest.py/finish_vest.py som reproducerbar kedja.
    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
    [vest-patch-bom.xls, vest-patch-centroid.csv, vest-patch-centroid.xls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]
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2026-06-16 Återställ optik-BOM till matchande MPN (14/15) — ångra R2-split + in-stock-byten
    Mina 'in-stock'-byten gjorde matchningen sämre (14/15 → 11/15): FRC-resistor, JK-PTC,
    16V-cap blev pending. Återställt till de MPN som NextPCB faktiskt matchar:
    - R2: ångrade onödiga 2× 6R8-splitten → enkel 3R3 2W CRCW25123R30FKEGHP (matchad).
    Netlist + placement (R4 borttagen), optik omdragen ren (0 oroutade/clearance).
    - F1 → MF-MSMF075/16X-2 (matchad). C2 → 100µF 25V GRM32ER61E107ME20L (enda pending).
    - D2/D3 SFH4725S → Procurement 'C' (i BOM, NextPCB monterar, du levererar delen).
    Prototyp-optik: IMU(U1)+C3/C4/C5 DNP + J1/J2 kund-lödd kvarstår. Allt regenererat.
    https://claude.ai/c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
    [optik-PROTOTYP-bom.xls, optik-PROTOTYP-centroid.csv, optik-PROTOTYP-centroid.xls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]
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
